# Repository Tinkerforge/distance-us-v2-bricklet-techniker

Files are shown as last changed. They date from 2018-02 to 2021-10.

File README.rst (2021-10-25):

Distance US Bricklet 2.0
========================

**This Bricklet is currently in development.**

This repository contains the firmware source code and the hardware design
files. The documentation generator configs can be found at
https://github.com/Tinkerforge/generators

Repository Content
------------------

software/:
 * examples/: Examples for all supported languages
 * build/: Compiled files
 * src/: Source code of firmware
 * Makefile: Makefile to build project

hardware/:
 * Contains KiCad project files and additionally schematics as PDF

datasheets/:
 * Contains datasheets for sensors and complex ICs that are used

Hardware
--------

The hardware is designed with the open source EDA Suite KiCad
(http://www.kicad.org). Before you are able to open the files,
you have to install the Tinkerforge kicad-libraries
(https://github.com/Tinkerforge/kicad-libraries). You can either clone
them directly in hardware/ or clone them in a separate folder and
symlink them into hardware/
(ln -s kicad_path/kicad-libraries project_path/hardware). After that you
can open the .pro file in hardware/ with KiCad and from there view and
modify the schematics and the PCB layout.

Software
--------

If you want to do your own Brick/Bricklet firmware development we highly
recommend that you use our build environment setup script and read the
tutorial (https://www.tinkerforge.com/en/doc/Tutorials/Tutorial_Build_Environment/Tutorial.html).

To compile the C code we recommend you to install the newest GNU Arm Embedded
Toolchain (https://launchpad.net/gcc-arm-embedded/+download).
You also need to install bricklib2 (https://github.com/Tinkerforge/bricklib2).

You can either clone it directly in software/src/ or clone it in a
separate folder and symlink it into software/src/
(ln -s bricklib_path/bricklib2 project_path/software/src/). Finally make sure to
have CMake installed (http://www.cmake.org/cmake/resources/software.html).

After that you can build the firmware by invoking make in software/.
The firmware (.zbin) can then be found in software/build/ and uploaded
with brickv (click button "Flashing" on start screen).

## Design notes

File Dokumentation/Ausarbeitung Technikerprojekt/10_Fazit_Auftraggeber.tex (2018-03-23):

Aus den Versuchen und Messungen lassen sich mehrere Aussagen treffen. \\
Als erstes, eine Ultraschall-Entfernungsmessung ist mit wenigen Bauteilen, sowohl als Zwei-Kapsel-Variante, als auch als Ein-Kapsel-Variante durchführbar. Bei der Ein-Kapsel-Variante ist darauf zu achten, dass der Verstärker eine ausreichende Spannungsfestigkeit besitzt, um nicht durch das Sendersignal gestört zu werden. Es ist wichtig, dass bei der Erzeugung des Pulsweiten-Modulierten Ausgangssignals die MOSFETs so angesteuert werden, dass den MOSFETs zwischen den Schaltsignalen genug Zeit gegeben wird, um die Schaltzustände zu erreichen. Vergleiche Abbildung \ref{fig:PWMs}. Dadurch lassen sich Kurzschlüsse an dieser Stelle vermeiden.\\
Eine Auswertung des Echo-Signals ist prinzipiell sowohl digital, als auch analog möglich. Bei der digitalen Auswertung muss die Zeit erfasst werden, die zwischen dem Senden des PWM-Signals und dem Empfangen des Echo-Signals vergeht. Die errechnete Strecke ist zu halbieren, da die vergangene Zeit sowohl den Hin-, als auch den Rückweg beinhaltet. Bei der analogen Auswertung besteht zwar die Alternative über einen Frequenzvergleich auch Signale mit kleinerer Echo-Amplitude zu erkennen und auszuwerten, allerdings beinhaltet dieses Vorgehen einen deutlich höheren Programmieraufwand.\\
Bei der Berechnung der Zeiten muss berücksichtigt werden, dass das eingehende Echo-Signal die Ultraschallkapsel langsam in Schwingungen versetzt. Die ersten eintreffenden Schwingungen eines PWM-Signals erzeugen kleinere Spannungssignale als die darauf folgenden. Außerdem schwingt die Ultraschallkapsel nach Ende des eingehenden Signals noch etwas nach, was zur Folge hat, dass das analoge Abbild des gesendeten PWM-Signals leicht versetzt und etwas verlängert wirkt. All diese Faktoren müssen für eine genauere Berechnung der Strecke, die das Signal zurück gelegt hat, berücksichtigt werden. Eine exakte Entfernungsmessung ist nicht möglich, denn das empfangene Signal an der Ultraschallkapsel verändert sich. Eine Beschränkung des Fehlers auf einzelne Zentimeter ist durch rechnerische Korrekturfaktoren realisierbar.\\
Was noch überprüft werden sollte, ist in wie weit sich eine leichte Erhöhung der Frequenz von 40\,kHz auf 42\,kHz auf die Signalqualität und die Reichweite auswirkt. Auch war es zeitlich nicht möglich weitere Messreihen im Außenbereich durchzuführen, was noch weitere Erkenntnisse bringen könnte. Mit den aktuellen Schaltplänen ist der Aufbau eines Ultraschall-Entfernungsmessers durchführbar. Diese Variante arbeitet in einem Bereich von 20\,cm bis 3\,m zuverlässig. Mit erhöhter Sendespannung von 15\,V-20\,V ist auch eine Reichweite von 5\,m bei festen Hindernissen kein Problem. Was noch aussteht, ist eine Festlegung auf definierte Werte für die Verstärkung und die Sendespannung, um die beiden Potentiometer durch Widerstände zu ersetzen. Dadurch lässt sich der Arbeitsbereich auf einen gewünschten Bereich fixieren. Das vorhandene Programm muss nur noch derart erweitert werden, dass die Zeiterfassung für das Echo-Signal überarbeitet und der errechnete Objektabstand ausgegeben wird. Daraus resultiert, dass durch weitere Bearbeitung des Projektes ein qualitatives und durch seine Bauweise, selten auf dem Markt zu findendes Produkt, entstehen kann.

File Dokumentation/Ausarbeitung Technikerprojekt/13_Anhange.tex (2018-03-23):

Abbildungen der Messreihen mit Sendespannungen von 5\,V und 10\,V bei Abständen von ein bis fünf Metern.\\
\begin{minipage}{0.46\textwidth}
\includegraphics[width=1\textwidth%, draft
]{Abbildungen/MessungenP2/5V/1m.PNG}
\captionof{figure}{Signalverlauf bei 5\,V auf 1\,m Abstand}
\end{minipage}\qquad
\begin{minipage}{0.46\textwidth}
\includegraphics[width=1\textwidth%, draft
]{Abbildungen/MessungenP2/10V/1m.PNG}
\captionof{figure}{Signalverlauf bei 10\,V auf 1\,m Abstand}
\end{minipage}\\
\begin{minipage}{0.46\textwidth}
\includegraphics[width=1\textwidth%, draft
]{Abbildungen/MessungenP2/5V/2m.PNG}
\captionof{figure}{Signalverlauf bei 5\,V auf 2\,m Abstand}
\end{minipage}\qquad
\begin{minipage}{0.46\textwidth}
\includegraphics[width=1\textwidth%, draft
]{Abbildungen/MessungenP2/10V/2m.PNG}
\captionof{figure}{Signalverlauf bei 10\,V auf 2\,m Abstand}
\end{minipage}\\
\begin{minipage}{0.46\textwidth}
\includegraphics[width=1\textwidth%, draft
]{Abbildungen/MessungenP2/5V/3m.PNG}
\captionof{figure}{Signalverlauf bei 5\,V auf 3\,m Abstand}
\end{minipage}\qquad
\begin{minipage}{0.46\textwidth}
\includegraphics[width=1\textwidth%, draft
]{Abbildungen/MessungenP2/10V/3m.PNG}
\captionof{figure}{Signalverlauf bei 10\,V auf 3\,m Abstand}
\end{minipage}\\
\begin{minipage}{0.46\textwidth}
\includegraphics[width=1\textwidth%, draft
]{Abbildungen/MessungenP2/5V/4m.PNG}
\captionof{figure}{Signalverlauf bei 5\,V auf 4\,m Abstand}
\end{minipage}\qquad
\begin{minipage}{0.46\textwidth}
\includegraphics[width=1\textwidth%, draft
]{Abbildungen/MessungenP2/10V/4m.PNG}
\captionof{figure}{Signalverlauf bei 10\,V auf 4\,m Abstand}
\end{minipage}\\
\begin{minipage}{0.46\textwidth}
\includegraphics[width=1\textwidth%, draft
]{Abbildungen/MessungenP2/5V/5m.PNG}
\captionof{figure}{Signalverlauf bei 5\,V auf 5\,m Abstand}
\end{minipage}\qquad
\begin{minipage}{0.46\textwidth}
\includegraphics[width=1\textwidth%, draft
]{Abbildungen/MessungenP2/10V/5m.PNG}
\captionof{figure}{Signalverlauf bei 10\,V auf 5\,m Abstand}
\end{minipage}\\
Abbildungen der Messreihen mit Sendespannungen von 15\,V und 20\,V bei Abständen von ein bis fünf Metern.\\
\begin{minipage}{0.46\textwidth}
\includegraphics[width=1\textwidth%, draft
]{Abbildungen/MessungenP2/15V/1m.PNG}
\captionof{figure}{Signalverlauf bei 15V auf 1m Abstand}
\end{minipage}\qquad
\begin{minipage}{0.46\textwidth}
\includegraphics[width=1\textwidth%, draft
]{Abbildungen/MessungenP2/20V/1m.PNG}
\captionof{figure}{Signalverlauf bei 20\,V auf 1\,m Abstand}
\end{minipage}\\
\begin{minipage}{0.46\textwidth}
\includegraphics[width=1\textwidth%, draft
]{Abbildungen/MessungenP2/15V/2m.PNG}
\captionof{figure}{Signalverlauf bei 15\,V auf 2\,m Abstand}
\end{minipage}\qquad
\begin{minipage}{0.46\textwidth}
\includegraphics[width=1\textwidth%, draft
]{Abbildungen/MessungenP2/20V/2m.PNG}
\captionof{figure}{Signalverlauf bei 20\,V auf 2\,m Abstand}
\end{minipage}\\
\begin{minipage}{0.46\textwidth}
\includegraphics[width=1\textwidth%, draft
]{Abbildungen/MessungenP2/15V/3m.PNG}
\captionof{figure}{Signalverlauf bei 15\,V auf 3\,m Abstand}
\end{minipage}\qquad
\begin{minipage}{0.46\textwidth}
\includegraphics[width=1\textwidth%, draft
]{Abbildungen/MessungenP2/20V/3m.PNG}
\captionof{figure}{Signalverlauf bei 20V auf 3m Abstand}
\end{minipage}\\
\begin{minipage}{0.46\textwidth}
\includegraphics[width=1\textwidth%, draft
]{Abbildungen/MessungenP2/15V/4m.PNG}
\captionof{figure}{Signalverlauf bei 15\,V auf 4\,m Abstand}
\end{minipage}\qquad
\begin{minipage}{0.46\textwidth}
\includegraphics[width=1\textwidth%, draft
]{Abbildungen/MessungenP2/20V/4m.PNG}
\captionof{figure}{Signalverlauf bei 20\,V auf 4\,m Abstand}
\end{minipage}\\
\begin{minipage}{0.46\textwidth}
\includegraphics[width=1\textwidth%, draft
]{Abbildungen/MessungenP2/15V/5m.PNG}
\captionof{figure}{Signalverlauf bei 15\,V auf 5\,m Abstand}
\end{minipage}\qquad
\begin{minipage}{0.46\textwidth}
\includegraphics[width=1\textwidth%, draft
]{Abbildungen/MessungenP2/20V/5m.PNG}
\captionof{figure}{Signalverlauf bei 20\,V auf 5\,m Abstand}
\end{minipage}\\
\newpage
Tabellen mit errechneten Objektabständen zu den durchgeführten Messungen\\
\begin{minipage}{1\textwidth}
\captionof{table}{Entfernungsmessung bei 5\,V Sendespannung}
\label{tab:Entfernungsmessung5V}
\begin{tabularx}{\textwidth}{|p{0.1\textwidth}|p{0.2\textwidth}|p{0.2\textwidth}|p{0.2\textwidth}|X|}
\hline
Entfernung [m]& Zeit bis Anfang Echo [ms] & Zeit bis Ende Echo [ms] & Errechnete Entfernung Anfang [m] & Errechnete Entfernung Ende [m]\\
\hline
1 & 6,11 & 7,23 & 1,0485 & 1,2407\\
\hline
1,5 & 9,02 & 9,89 & 1,5478 & 1,6971\\
\hline
2 & 11,97 & 12,76 & 2,0541 & 2,1896\\
\hline
2,5 & 14,88 & 15,5 & 2,5534 & 2,659\\
\hline
3 & 17,84 & 18,2 & 3,06134 & 3,1231\\
\hline
3,5 & 20,8 & 21,11 & 3,569 & 3,6225\\
\hline
4 & 23,71 & 23,81 & 4,0686 & 4,0858\\
\hline
4,5 & 26,61 & 26,73 & 4,5663 & 4,5869\\
\hline
5 & 29,59 & 29,68 & 5,0776 & 5,0961\\
\hline
\end{tabularx}
\end{minipage}
\begin{minipage}{1\textwidth}
\captionof{table}{Entfernungsmessung bei 10\,V Sendespannung}
\label{tab:Entfernungsmessung10V}
\begin{tabularx}{\textwidth}{|p{0.1\textwidth}|p{0.2\textwidth}|p{0.2\textwidth}|p{0.2\textwidth}|X|}
\hline
Entfernung [m]& Zeit bis Anfang Echo [ms] & Zeit bis Ende Echo [ms] & Errechnete Entfernung Anfang [m] & Errechnete Entfernung Ende [m]\\
\hline
1 & 6,07 & 7,37 & 1,0416 & 1,2647\\
\hline
1,5 & 8,99 & 10,02 & 1,5427 & 1,7194\\
\hline
2 & 11,94 & 12,9 & 2,0489 & 2,2136\\
\hline
2,5 & 14,83 & 15,7 & 2,5448 & 2,6941\\
\hline
3 & 17,8 & 18,48 & 3,0545 & 3,1712\\
\hline
3,5 & 20,7 & 21,36 & 3,5521 & 3,6654\\
\hline
4 & 23,62 & 24 & 4,0532 & 4,1184\\
\hline
4,5 & 26,55 & 26,9 & 4,5560 & 4,6160\\
\hline
5 & 29,5 & 29,9 & 5,0622 & 5,1308\\
\hline
\end{tabularx}
\end{minipage}
\begin{minipage}{1\textwidth}
\captionof{table}{Entfernungsmessung bei 15\,V Sendespannung}
\label{tab:Entfernungsmessung15V}
\begin{tabularx}{\textwidth}{|p{0.1\textwidth}|p{0.2\textwidth}|p{0.2\textwidth}|p{0.2\textwidth}|X|}
\hline
Entfernung [m]& Zeit bis Anfang Echo [ms] & Zeit bis Ende Echo [ms] & Errechnete Entfernung Anfang [m] & Errechnete Entfernung Ende [m]\\
\hline
1 & 6,08 & 7,37 & 1,04333 & 1,2647\\
\hline
1,5 & 8,96 & 10,05 & 1,5375 & 1,7246\\
\hline
2 & 11,92 & 12,95 & 2,0455 & 2,2222\\
\hline
2,5 & 14,81 & 15,75 & 2,5414 & 2,7027\\
\hline
3 & 17,78 & 18,5 & 3,0510 & 3,1746\\
\hline
3,5 & 20,65 & 21,47 & 3,5435 & 3,6843\\
\hline
4 & 23,6 & 24,35 & 4,0698 & 4,1785\\
\hline
4,5 & 26,5 & 26,93 & 4,5474 & 4,6212\\
\hline
5 & 29,48 & 30 & 5,0588 & 5,148\\
\hline
\end{tabularx}
\end{minipage}
\begin{minipage}{1\textwidth}
\captionof{table}{Entfernungsmessung bei 20\,V Sendespannung}
\label{tab:Entfernungsmessung20V}
\begin{tabularx}{\textwidth}{|p{0.1\textwidth}|p{0.2\textwidth}|p{0.2\textwidth}|p{0.2\textwidth}|X|}
\hline
Entfernung [m]& Zeit bis Anfang Echo [ms] & Zeit bis Ende Echo [ms] & Errechnete Entfernung Anfang [m] & Errechnete Entfernung Ende [m]\\
1 & 6,07 & 7,42 & 1,0416 & 1,2733\\
\hline
1,5 & 8,97 & 10,12 & 1,5392 & 1,7366\\
\hline
2 & 11,92 & 13 & 2,0454 & 2,2308\\
\hline
2,5 & 14,8 & 15,8 & 2,5396 & 2,7113\\
\hline
3 & 17,75 & 18,55 & 3,0459 & 3,1832\\
\hline
3,5 & 20,65 & 21,52 & 3,5435 & 3,6928\\
\hline
4 & 23,56 & 24,31 & 4,0428 & 4,1716\\
\hline
4,5 & 26,49 & 27,13 & 4,5456 & 4,6555\\
\hline
5 & 29,46 & 30,1 & 5,0553 & 5,1652\\
\hline
\end{tabularx}
\end{minipage}\\

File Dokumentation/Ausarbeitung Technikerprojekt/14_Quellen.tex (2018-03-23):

\subsection{Dokumentationen}

{ {[EUR] {Eurocircuits}}, {https://www.eurocircuits.com/pcb-design-guidelines/ }
\\ {22.\,März.\,2018}.\\

{ {[RNW] {RN-Wissen}}, {http://rn-wissen.de/wiki/index.php/Abblockkondensator }
\\ {22.\,März.\,2018}.\\

{ {[EV] {Elektronikpraxis Vogel}}, {https://www.elektronikpraxis.vogel.de/sieben-suenden-beim-\\leiterplatten-design-a-356703/ }
\\ {22.\,März.\,2018}.\\

{ {[Mik1] {Mikrocontroller.net}}, { https://www.mikrocontroller.net/articles/Richtiges\_Designen\_von\\
\_Platinenlayouts }
\\ {22.\,März.\,2018}.\\

{ {[Mik2] {Mikrocontroller.net}}, {https://www.mikrocontroller.net/articles/Schaltplan\_richtig\_zeichnen }
\\ {22.\,März.\,2018}.\\

{ {[INFI3] {Infineon}}, {https://www.infineon.com/cms/de/product/microcontroller/32-bit-industria\\
l-microcontroller-based-on-arm-cortex-m/32-bit-xmc1000-industrial-microcontroller-arm-cortex-m0/   }
\\ {22.\,März.\,2018}.\\

\subsection{Datenblätter}

{ {[NEX] {Nexperia}}, {https://assets.nexperia.com/documents/data-sheet/2N7002P.pdf}
\\ {22.\,März.\,2018}.\\

{{[INC1] {Doides Incorporated}}, {https://www.diodes.com/assets/Datasheets/ds30149.pdf}
\\{22.\,März.\,2018}.\\

{{[INC2] {Doides Incorporated}}, {https://www.diodes.com/assets/Datasheets/DMG6602SVT.pdf}
\\{22.\,März.\,2018}.\\

{{[INFI1] {Infineon}}, {https://www.infineon.com/dgdl/Infineon-XMC1400-DS-v01\_03-EN.pdf?\\fileId=5546d46250cc1fdf015110a2596343b2}
\\ {22.\,März.\,2018}.\\

{{{INFI2}}, {https://www.infineon.com/dgdl/Infineon-XMC1400-AA\_ReferenceManual-UM
\\-v01\_01-EN.pdf?fileId=5546d46250cc1fdf0150f6ebc29a7109}
\\ {22.\,März.\,2018}.\\

{{[KHM] {Elektrotechnik Karl-Heinz Mauz GmbH}}, {http://www.produktinfo.conrad.com/daten
\\blaetter/525000-549999/541348-da-01-en-OFFENER\_ULTRASCHALLSENSOR\_A\_16P\_T\_R.pdf}
\\{22.\,März.\,2018}.\\

{{[AM] { Allegro MicroSystems, LLC }}, {https://www.allegromicro.com/de-DE/Products/Motor-
\\Driver-And-Interface-ICs/Brush-DC-Motor-Drivers/A5950.aspx}
\\ {22.\,März.\,2018}.\\

{{[TI] {Texas Instruments}}, {http://pdf1.alldatasheet.com/datasheet-pdf/view/522033/TI/TLC272A.html}
\\{22.\,März.\,2018}.\\

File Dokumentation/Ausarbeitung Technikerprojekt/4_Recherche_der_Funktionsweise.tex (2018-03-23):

\tikzstyle{block} = [draw, fill=blue!20, rectangle, 
    minimum height=3em, minimum width=6em]
\tikzstyle{block1} = [draw, fill=white!20, rectangle, 
    minimum height=3em, minimum width=10em]
\tikzstyle{pinstyle} = [pin edge={to-,think,black}]
\tikzstyle{input} = [coordinate]
\tikzstyle{output} = [coordinate]
\tikzstyle{line} = [ draw, dashed, line width = 0.5pt, -latex']
\begin{center}
\begin{minipage}{0.75\textwidth}
\includegraphics[width=1\textwidth%, draft
]{Abbildungen/Schema.png}
\captionof{figure}{Blockschaltbild des Ultraschall-Entfernungsmessers}
\label{fig:Blockschaltbild}
%\begin{tikzpicture}[auto, node distance=2cm,>=latex']
%\begin{picture}(250,100)
%%\put(-38,-122){\dashbox{2.5}(210,45)[rb] {Empfänger}}
%%\put(-38-122){\text{Empfänger}}
%\node [block](controller){Controller};
%\node [block, right of=controller, node distance=4.5cm] (schalter)  {Schalter};
%\node [block, above of=schalter, node distance=2cm] (hochsetzsteller) {Hochsetzsteller};
%\node [block, right of=schalter, node distance=4.5cm] (ultraschallkapsel)  {Ultraschallkapsel};
%\node [block, below of=ultraschallkapsel, node distance=3.5cm] (filterung)  {Filterung};
%\node [block, left of=filterung, node distance=4.5cm] (verstaerker)  {Verstaerker};
%\node [block, left of=verstaerker, node distance=4.5cm] (komperrator)  {Komperrator};
%
%\draw [->] (controller) -- node[name=PWM ] {$PWM$}  (schalter);
%\node [output, right of=schalter] (output) {};
%\coordinate [below of=PWM] (tmp);
%\draw [->] (hochsetzsteller) -- node[name=VBB ] {$VBB$}  (schalter);
%\node [output, above of=schalter] (output) {};
%\coordinate [below of=VBB] (tmp);
%\draw [->] (schalter) --  (ultraschallkapsel);
%\draw [->] (ultraschallkapsel) --  (filterung);
%\draw [->] (filterung) --  (verstaerker);
%\draw [->] (verstaerker) --  (komperrator);
%\node [output, right of=schalter] (output) {};
%\coordinate [below of=PWM] (tmp);
%\draw [->] (komperrator) --  node[name=Digital ] {$Digital$} (controller);
%\node [output, above of=komperrator] (output) {};
%\coordinate [below of=Digital] (tmp);
%\path[line] (verstaerker)--node[name=analog] {$Analog$}  (controller);
%\end{picture}
%\end{tikzpicture}
%\captionof{figure}{Blockschaltbild}
%\label{fig:Blockschaltbild1}

\end{minipage}
\end{center}
Die Abbildung \ref{fig:Blockschaltbild} zeigt eine vereinfachte Funktionsübersicht der Platine. Die Schaltpläne zu den verschiedenen Ausführungen der Platine sind den Anlagen beigefügt.

\subsection{Mikrocontroller}
Der Mikrocontroller soll eine stabile und variable PWM ausgeben können. Es werden für die Zeiterfassung und die PWM Ausgabe mehrere Timer benötigt, die sowohl intern als auch über die Hardware angesteuert werden können. Ein Analog/Digital-Wandler sollte ebenfalls vorhanden sein.

\subsection{Sender}
Der Sender soll Schallwellen im Ultraschallbereich (40\,kHz) aussenden. Diese sollen einen ausreichenden Schalldruck haben um von Hindernissen, die mehrere Meter entfernt sind, ein Echo erhalten zu können. Dafür muss die Ultraschallkapsel mit einem sinusähnlichen Signal angesteuert werden. Dessen Amplitude muss angemessen hoch sein, um den gewünschten Schalldruck zu erzeugen. Der Mikrocontroller ist auf eine Spannungsebene von 3,3\,V begrenzt. Um höhere Spannungen an der Ultraschallkapsel realisieren zu können, muss ein Schalter als weiteres Bauteil dazwischen geschaltet werden. Dieses zusätzliche Bauteil dient als Trennung zwischen den 3,3\,V des Mikrocontrollers und der höheren Spannungsebene der Lautsprecherkapsel. Dabei muss darauf geachtet werden, dass der Schalter schnell genug arbeitet, um die 40\,kHz auch zuverlässig schalten zu können.

\subsection{Hochsetzsteller}
Der Hochsetzsteller generiert aus den 5\,V Versorgungsspannung eine höhere Spannung für den Sendebetrieb. So kann der Schalldruck, der ausgegeben wird erhöht werden (größere Reichweite/größeres Rücksignal) siehe Abbildung \ref{fig:5v5m2}.\\
Die Funktionsweise des Hochsetzstellers (Spannungspumpe/Aufwärtswandler/Aufwärtsregler) ist überschaubar und findet in vielen Bereichen Anwendung. Grundsätzlich wird eine Induktivität in Reihe mit einer Freilaufdiode vor einen Ladekondensator geschaltet. Dieser liegt parallel zum Ausgang. Zwischen der Spule und der Diode ist ein Schalter angeschlossen, der die Spule gegen Masse schaltet. Die Spule lädt sich bei Betätigung des Schalters auf. Durch den Stromfluss entsteht ein Magnetfeld und beim öffnen steigt die Spannung am sekundären Ende der Spule. Durch das zusammenbrechende Magnetfeld an und lädt den Kondensator auf. Dieser Vorgang wird wiederholt bis der Kondensator so weit aufgeladen ist, dass die Ausgangsspannung den gewünschten Wert hält. Die mögliche Ausgangsspannung ist nicht unbegrenzt über das Schaltspiel regelbar. Sie ist von den Eigenschaften der Komponenten abhängig. Vergleiche Abbildung \ref{fig:Hochsetzsteller}.

\subsection{Ultraschallkapsel}
Für das Senden und Empfangen des Ultraschalls wird eine auf Piezomodulen basierende Ultraschallkapsel verwendet, weil Sie die Möglichkeit hat ein Signal auszugeben sowie zu empfangen und in Kleinbauform erhältlich ist. Wie stark das Nachschwingen der Kapsel eine Auswirkung auf die Empfängerschaltung hat, sowie die Größe der Störfrequenz bei verschiedenen Amplituden auf unterschiedlichen Entfernungen sollte überprüft werden. Es sollte auch getestet werden welche Kapseln sich für einen stand-alone Betrieb am besten eignen.

\subsection{Filter}
Die Filterschaltung soll am Eingang des Empfängers etwaig Störfrequenzen herauszufiltern um eine Verfälschung der gemessenen Strecke zu vermeiden, da die Ultraschallkapsel nicht ausschließlich Ultraschallsignale aufnimmt. Für hohe Frequenzen eignet sich eine passive Hochpassfilter-Schaltung, es wird zu einem Kondensator oder einer Spule ein Widerstand parallel zur Masse bestückt. 

\subsection{Empfänger}
Im Empfangsbetrieb werden die zurückkommenden Schallsignale, die auf die Ultraschallkapsel treffen, in sinusförmige Spannungssignale umgewandelt. Die Amplitude hängt von dem Schalldruck der empfangenen Signale ab und ist deutlich niedriger als die Amplitude der gesendeten Signale. Diese Signale müssen anschließend verstärkt werden, um sie mit dem Mikrocontroller auswerten zu können. Zur Vereinfachung der Auswertung wird das eingehende analoge Signal in ein digitales Signal umgewandelt, um Verarbeitungsaufwand einsparen zu können. Die Analyse eines Analogsignals erfordert mehr Programmieraufwand als die Auswertung eines Digitalsignals. Um die Qualität der gemessenen Entfernung besser zu beurteilen, sollte potenziell auch das Analogsignal ausgewertet und mit dem digitalen Signal verglichen werden.

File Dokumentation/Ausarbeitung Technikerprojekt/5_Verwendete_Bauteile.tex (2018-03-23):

Bevor ein erster Prototyp erstellt werden konnte, mussten die richtigen Bauteile ausgewählt werden. Dies Geschah unteranderem anhand der gewonnenen Informationen aus dem Kapitel 2 Vorbereitung. 

\subsection{Mikrocontroller}
Der Infineon XMC 1404\_Q048 gehört zur Familie der ARM Cortex -M0 Prozessoren und ist ein 32\,Bit Industrial Mikrocontroller, wird mit 48\,MHz externer Clock betrieben. Die Q048 im Namen steht für die Anzahl der Pins. Der interne Timer läuft mit 96~MHz. Die CCU4 des Prozessors bietet ein 2x4 16\,Bit Timer. Zudem hat der XMC einen 12\,Bit A/D Wandler, welcher für die Analogmessung eine genauere Auflösung bieten kann als ein 8\,Bit A/D Wandler. Die Betriebsspannung des Prozessors beträgt 3,3\,V. Die Auswahl des Mikrocontrollers wurde getroffen, weil dieser standardmäßig bei Tinkerforge eingesetzt wird und uns für den Prototypen vorgegeben wurde.

\subsection{Sender}Um eine Trennung zwischen der Mikrocontroller, (3,3\,V) und dem Hochsetzsteller (5\,V-20\,V)zu ermöglichen, wurde ein zusätzliches Bauteil benötigt. Dafür wurde das IC A5950 (Voll Brücke) ausgewählt. Diese H-Brücke kann eine angeschlossene Last mit der vom Hochsetzstellers erzeugten Spannung versorgen. Deren Frequenz wird über das Signal an dem Pin \glqq Phase \grqq~von dem Prozessor vorgegeben. An den Anschlüssen Out1 und Out2 wird das Ausgangssignal abgegriffen. Für die genaue Beschaltung des ICs siehe Anhang Datenblatt  \glqq Schimatic A5950 \grqq.

\subsection{Hochsetzsteller}
Tinkerforge nutzt schon eine Variante eines Hochsetzstellers auf ihren Platinen. Der Aufbau und die Bauteilauswahl mussten nur auf die variable Ausgangspannungs erweitert werden. Die Standardschaltung, von Tinkerforge, wurde an dem Eingang der Feedbackspannung mit einem Potentiometer (R\textsubscript{V1}) ergänzt, um die gewünschte variable Spannung zu generieren. Zu sehen in Abbildung \ref{fig:Hochsetzsteller}.\\
Die Ausgangsspannung wird mit den externen Widerständen R\textsubscript{V1}, R\textsubscript{13} und R\textsubscript{2} eingestellt (siehe Grundschaltung Datenblatt vom IC LRM62014x, Seite 11). Ein Wert von ca. \(\displaystyle 13,3\,k\Omega \) wurde für R\textsubscript{2} empfohlen. Mit den Potentiometer R\textsubscript{V1} lässt sich die Ausgangsspannung bei 5\,V Eingangsspannung bis 21,5\,V einstellen. In der Formel werden die Widerstände R\textsubscript{V1} und R\textsubscript{13} zum Ersatzwiderstand R\textsubscript{E} zusammengefasst.
\onehalfspacing \\
\[\displaystyle R_{E}=R_{2}*\left(\frac{Vout}{1,23}-1\right) \Rightarrow Vout=\left(\frac{R_{E}}{R_{2}}+1\right)*1,23\] 
\singlespacing
\begin{center}
\begin{minipage}{1\textwidth}
\includegraphics[width=1\textwidth%, draft
]{Abbildungen/Pumpe.png}
\captionof{figure}{Schaltplan des beschalteten Hochsetzstellers}
\label{fig:Hochsetzsteller}
\end{minipage}\\
\end{center}

\subsection{Ultraschallkapsel}%bearbeiten
Für den Prototypen wurden mehrere Kapseln diverser Hersteller bestellt. Dieses geschah um Unterschiede der verschieden preisigen Bauteile zu ermitteln und um festzustellen, welches Preissegment die nötige Qualität für die vorliegende Anwendung erfüllt.

\subsection{Filter}%bearbeiten
Um unerwünschte Signalanteile mit Frequenzen, die unter 40\,kHz liegen, zu unterdrücken musste die Filterschaltung mit einem Hochpassfilter (CR Glied) bestehend aus einem Kodensator und einem Widerstand bestückt. Der Widerstand wurde nach der e24\,Reihe ausgewählt.
Die Kapazität des Kondensators wurde an die Grenzfrequenz von 40\,kHz und den Widerstand angepasst.
\onehalfspacing \\
\[\displaystyle C=\frac{1}{2*\pi*fg*R}\Rightarrow\frac{1}{2*\pi*40\,kHz*100\,k\Omega}\approx40\,pF \]
\singlespacing
Anhand der Berechnung wurde für den Hochpassfilter ein Kondensator mit \(\displaystyle 39\,pF\) für C12 in der Abbildung \ref{fig:Empfaengerschaltung} verwendet.
\newpage
\subsection{Empfänger}
Die Abbildung \ref{fig:Empfaengerschaltung} zeigt die Empfängerschaltung. Durch diese Verschaltung von Operationsverstärkern wird das ankommende sinusförmige Signal verstärkt und in ein digitales Signal umgewandelt. Für die Verstärkung der Amplitude und der Umwandlung des analogen Signals in ein Rechtecksignal mit 40\,KHz wurde der das IC TLC272 ausgewählt, weil dieses günstig im Stückpreis ist und die technischen Spezifikationen ausreichend sind. Siehe Datenblatt vom IC TLC272 [TI].\\
Für die Verstärkung der Amplitude ist der Operationsverstärker TLC272 U2B als nicht invertierender Verstärker geschaltet.
Zur Umwandlung des analogen Signales in ein digitales wurde der Operationsverstärker TLC272 U2C als Komparator geschaltet. Beim Auftreten von Differenzen zwischen den Eingangssignalen, wechselt der Ausgang des Komparators zwischen Low (0\,Volt) auf High (3,3\,Volt).\\ Die Referenzspannung (\(\displaystyle U_{ref})\)  wird durch den Spannungsteiler R\textsubscript{9} und R\textsubscript{10} bestimmt.
\onehalfspacing \\
\[\displaystyle U_{ref}=\frac{U_{ges}*R_{9}}{R_{9}+R_{10}}\Rightarrow\frac{3,3\,V*120\,k\Omega}{100\,k\Omega+120\,k\Omega}=1,8\,V \]
\singlespacing
\begin{center}
\begin{minipage}{1\textwidth}
\includegraphics[width=1\textwidth%, draft
]{Abbildungen/Empfaenger.png}
\captionof{figure}{Schaltplan zweier Operationsverstärker mit einer vorgelagerten Filterung als Empfängerschaltung}
\label{fig:Empfaengerschaltung}
\end{minipage}\\
\end{center}

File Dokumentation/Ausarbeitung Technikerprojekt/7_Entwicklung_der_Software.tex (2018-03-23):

Zum Betrieb der Prototypen wurde bereits eine rudimentäre Version einer Betriebssoftware erstellt. Diese wurde benötigt um Ausgangssignale generieren zu können, damit Messungen an dem Empfängerkreis durchgeführt werden konnten.
\subsection{Benötigte Kenntnisse}
Um das Programm zu erstellen sollten Kenntnisse z.B. für die Capture Compare Unit des Mikrocontrollers vorhanden sein. Die CCU4 hat insgesamt 4 Einheiten und jede einzelne besitzt mehrer Slices von CC40 bis CC43. Slices können untereinander verschachtelt werden um z.B. Interrupt Service Routinen aufzurufen, siehe dazu das Reference Manual [INF2].
Die Werte der Register mit denen die Zeit gemessen wird müssen sofort zum beginn der Interrupt Service Routine zwischengespeichert werden damit sichergestellt wird das nicht die Zeit zur Brechung mit gemessen wird.\\

\subsubsection{Durchgeführte Berechnungen}
Für die Programmierung waren diverse Berechnungen notwendig. Zur Erzeugung der Ultraschallimpulse wurde ein pulsweitenmoduliertes Rechtecksignal mit einer Frequenz von 40\,kHz generiert. Dafür war es notwendig mithilfe der CCU4 einen Timer zur erstellen. Dabei musste bei einem Timertakt von 96\,MHz eine Periodendauer von 2400 Takten und einem Compare-Wert von 1200 Takten konfiguriert werden. Im Zählvorgang des Timers wird der Ausgang nach erreichen des Compare-Wertes auf 1 gesetzt, und nach erreichen der Periodendauer wieder auf 0 zurückgesetzt. Dadurch ergibt sich eine Periodendauer von 25\,\textmu s, was einer Frequenz von 40\,kHz entspricht.\\
Die Zeit, die vergeht, bis das Echo des Ultraschall-Impulses zurückkommt, wird über einen Timer erfasst. 
\onehalfspacing \\ \\
\[\displaystyle Periodendauer=\frac{96\,MHz}{40\,kHz} = 2400,\qquad	 Compare-Wert=\frac{2400}{2} = 1200 \] 
\singlespacing

\subsection{Quellcodeentwurf}

\textbf{Programmstruktur:}\\
In der Hauptpfunktion main.c befinden sich nur Funktionsaufrufe die eine Grundkonfiguration  für den Mikrocontroller beinhalten und eine Schleife die immer wieder aufgerufen wird um z.B. eine neue Entfernungsmessung zu starten. Siehe Abbildung \ref{fig:main.c1}. Anstatt den gesamten Programmcode in der Hauptpfunktion zu verfassen, hat das Auslagern den Vorteil, dass der Quellcode logisch getrennt werden kann. Dieses Vorgehen führt zu einer Verschlankung des Quellcodes anstatt ihn unübersichtlich zu gestalten. Somit stehen in dem Hauptprogramm nur noch die Aufrufe der separat verfassten Funktionen. Dadurch vereinfacht diese Struktur gerade bei Prototypen das Testen der Funktion. So kann im Falle einer fehlerhaften Funktion einfach ein Aufruf auskommentiert werden, um zu testen, ob der Fehler wirklich von der Funktion herrührt. Somit müssen nicht etliche Zeilen Programmcode einer Funktion auskommentiert werden. Dadurch ist die Fehlerrate durch verbleibende Zeichen oder beim Entfernen der Auskommentierung gelöschte Zeichen deutlich gesenkt.\\
\begin{minipage}{1\textwidth}
\begin{lstlisting}
#include <stdio.h>
#include <stdbool.h>
#include "bricklib2/logging/logging.h"
#include "bricklib2/bootloader/bootloader.h"
#include "communication.h"
/****Eigene Include Dateien*******/
#include "configs/config.h"
#include "system_timer/system_timer.h"
#include "a16pt.h"
int main(void)
{ 
	logging_init(); 
	logd("Start Distance US V2 Bricklet/n/r");  	//For the Debugmodus
	communication_init(); 					//Function call
	a16pt_init(); 								//Function call	
	while(true)
	{
		a16pt_tick(); 						//Function call
		bootloader_tick(); 					//Function call
		communication_tick(); 				//Function call	
	}
}
\end{lstlisting}
\captionof{figure}{kompletter Quellcode der main.c}
\label{fig:main.c1}
\end{minipage}\\
%Um die Funktionsaufrufe wie die a16pt\_init und die a16pt\_tick zu verstehen muss die Abbildung \ref{fig:a16pt.h}: Headerdatei der a16pt.h näher betrachtet werden. In der der Datei werden die Funktionen definiert und deren Funktionsanweisung steht dann in der a16pt.c.\\
Die verwendete Vorgehensweise bei der Programmierung arbeitet mit einer gewissen Verschachtlung. In den *.c Dateien befindet sich zwar der Großteil des des aktiv geschriebenen Programms, doch stehen die Funktionsdefinitionen in den Headerdateien, wie der a16pt.h. Zu sehen in der nachfolgenden Abbildung \ref{fig:a16pt.h}\\
\begin{minipage}{1\textwidth}
\begin{lstlisting}
#ifndef A16PT_H
#define A16PT_H
#include <stdint.h>
	void a16pt_init(void);			//Functional definition
	void a16pt_tick(void); 			//Functional definition
	uint16_t a16pt_get_distance(void); //Functional definition
#endif
\end{lstlisting}
\captionof{figure}{Inhalt der Headerdatei a16pt.h}
\label{fig:a16pt.h}
\end{minipage}\\
\\
\textbf{Init Aufruf:}
In der Abbildung \ref{fig:a16pt.c} ist ein Teilausschnitt aus der a16pt.c zu sehen. Dieser enthält zwei verschiedene PWM Konfigurationen, die auf den Ports P4\_4 und P4\_6 ausgegeben werden.

\begin{minipage}{1\textwidth}
\begin{lstlisting}
void a16pt_init(void)
{
/*****************Externe_Interrupt*******************/

	eru_init(eru_port);

/************PWM_Init*****************************/

	XMC_CCU4_Init(CCU41, XMC_CCU4_SLICE_MCMS_ACTION_TRANSFER_PR_CR_PCMP);
	XMC_CCU4_StartPrescaler(CCU41);

	ccu4_pwm_init(pwm_port_0,cc40, period_1);	//P4_4
	ccu4_pwm_set_duty_cycle( cc40, compare_1);

	ccu4_pwm_init(pwm_port_1,cc42, period_0);	//P4_6
	ccu4_pwm_set_duty_cycle( cc42, compare_0);
...
\end{lstlisting}
\captionof{figure}{Ein Teilausschnitt aus der a16pt.c mit Konfigurationen von Funktionen}
\label{fig:a16pt.c}
\end{minipage}

\textbf{Interrupt Aufrufe:}
In der Abbildung \ref{fig:a16pt.c1} werden beispielsweise die für die Entfernungsmessung notwendigen Funktionen und die Interrupt Anweisungen abgearbeitet. in diesem Fall die IRQ21. Außerdem werden die PWM-Signale synchron abgeschaltet. Unter der Überschrift \glqq New pin configuration\grqq~wird bereits eine neue Ausgangskonfiguration angefangen. Die IRQ wird als Interrupt Request bezeichnet und wird von der Hardware oder von der Software ausgelöst.
\\
\begin{minipage}{1\textwidth}
\begin{lstlisting}

/*************Interrupt_Funktionen****************/

void IRQ_Hdlr_21(void) // Compare Interrupt counter 10
{
	// Disable IRQs so we can't be interrupted
	__disable_irq();

	// Set CCU trigger to low, otherwise ccu counter is restarted
	XMC_SCU_SetCcuTriggerLow(XMC_SCU_CCU_TRIGGER_CCU41);

	// Stop slice 2
	XMC_CCU4_SLICE_StopClearTimer(CCU41_CC40);

	// For slice 1 we wait until PWM is run through (to get exactly 10 pwm peaks on P4_4 and P4_6)
	while(XMC_CCU4_SLICE_GetTimerValue(CCU41_CC42) > compare_1) {

		__NOP();
	}
	
	//New pin configuration
	const XMC_GPIO_CONFIG_t pin_out_config	= {
			.mode                = XMC_GPIO_MODE_OUTPUT_PUSH_PULL,
			.output_level        = XMC_GPIO_OUTPUT_LEVEL_HIGH,
		};

...
\end{lstlisting}
\captionof{figure}{Ein Teilausschnitt von der a16pt.c mit einem Interrupt Request}
\label{fig:a16pt.c1}
\end{minipage}

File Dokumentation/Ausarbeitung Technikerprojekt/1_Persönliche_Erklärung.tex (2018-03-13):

\textbf{\Large{Persönliche Erklärung}}\vspace{10pt}

Hiermit bestätigen wir, dass die vorliegende Arbeit selbstständig verfasst und keine anderen als die angegebenen Hilfsmittel benutzt wurden. Die Stellen der Arbeit, die dem Wortlaut oder dem Sinn nach anderen Werken (dazu zählen auch Internet-quellen) entnommen sind, wurden unter Angabe der Quellen kenntlich gemacht.

\vspace{50pt}

\noindent Bielefeld,\noindent\rule{4cm}{.4pt} \hfill\rule{5cm}{.4pt}\par
\hfill Eduard Meiser 

\vspace{30pt}
%\noindent\rule{5cm}{.4pt}
\hfill\rule{5cm}{.4pt}\par
%\noindent Ort, Datum
\hfill Omar Hachimi 

\vspace{30pt}
%\noindent\rule{5cm}{.4pt}
\hfill\rule{5cm}{.4pt}\par
%\noindent Ort, Datum 
\hfill Stephan Dannat

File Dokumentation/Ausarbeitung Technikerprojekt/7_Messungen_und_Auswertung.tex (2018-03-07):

Zu Beginn wurden Messungen direkt an dem Prozessor durchgeführt, um zu kontrollieren, dass die im Programm errechneten Signale auch die vorgesehenen Frequenzen erreichen. Anschließend wurden einzelne Baugruppen mit dem Prozessor kombiniert, um das Zusammenspiel dieser auswerten zu können. Danach wurden die Baugruppen um den Sensor erweitert und auch dieses Zusammenspiel wurde ausgewertet. Zum Abschluss wurde dann die komplette Platine im Betrieb getestet und optimiert.

\section{Ausgabe}
Um das Signal für die Entfernungsmessung zu generieren wurde der Mikrocontroller so programmiert, dass zehn Impulse mit einer Frequenz von 40kHz ausgegeben werden. Danach erfolgt eine Pause, um das zurückkehrende Signal abzuwarten und auszuwerten.\\
\begin{minipage}{0.5\textwidth}
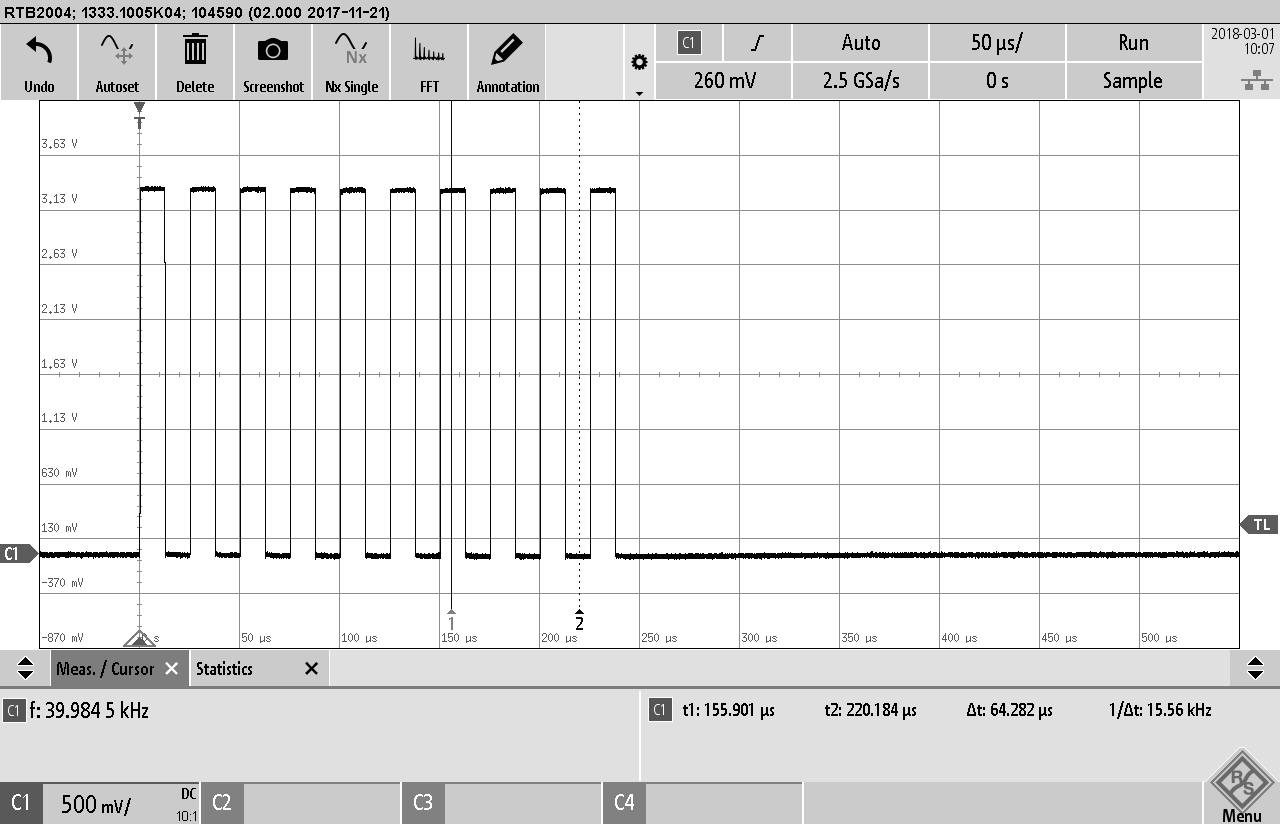
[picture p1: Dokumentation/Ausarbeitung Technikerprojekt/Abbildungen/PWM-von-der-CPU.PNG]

\captionof{figure}{PWM-Burst auf 40kHz Basis an der CPU}
\label{fig:pwm-burst}
\end{minipage}
\begin{minipage}{0.5\textwidth}
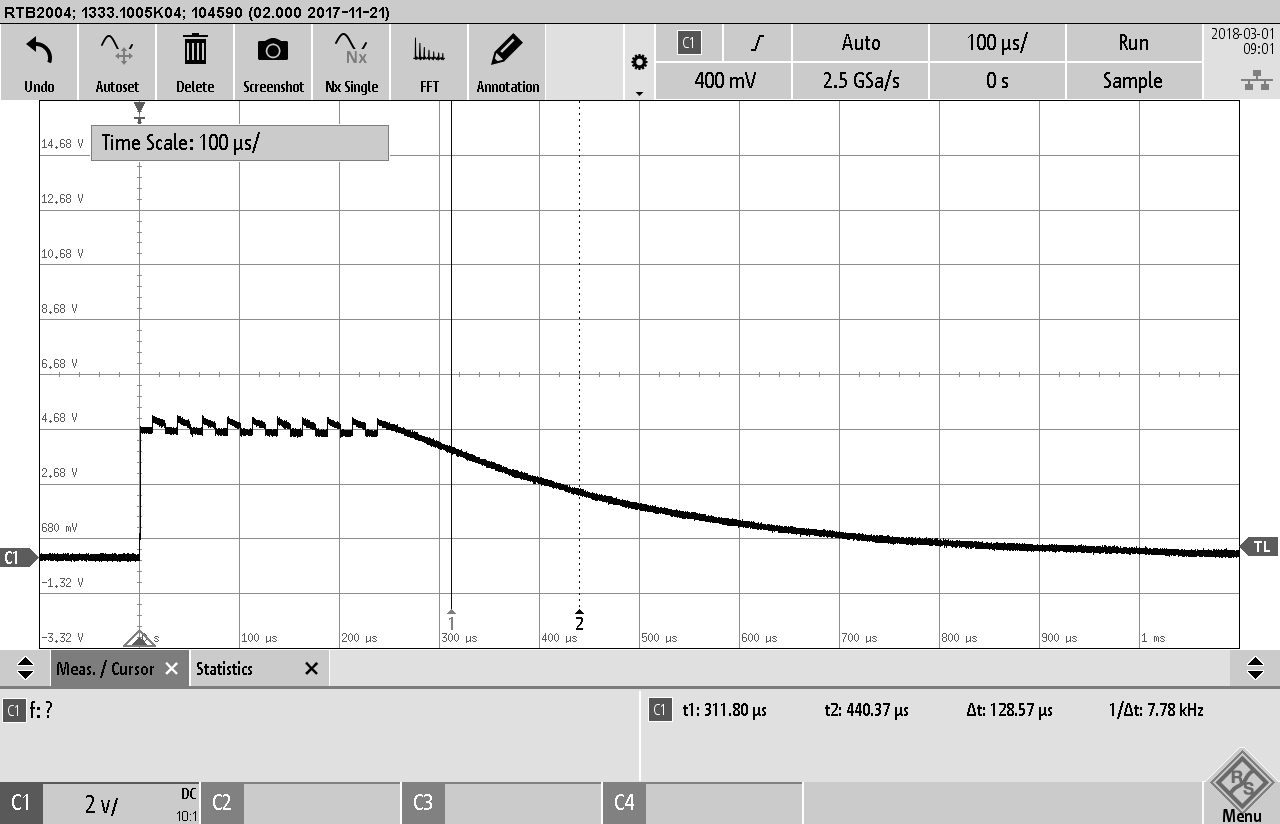
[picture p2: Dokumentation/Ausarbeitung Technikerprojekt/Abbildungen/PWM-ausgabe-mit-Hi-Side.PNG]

\captionof{figure}{PWM Ausgabe über einen Hi-Side}
\label{fig:HiSide}
\end{minipage}

In der Abbildung \ref{fig:pwm-burst} ist zu sehen, dass ein Burst aus zehn Impulsen mit einer Periodendauer von jeweils 25us generiert wurde. Diese Messung wurde direkt an dem Mikrocontroller vorgenommen, um zu überprüfen, wie sich das Signal durch die eingesetzten Bauteile verändert.\\
Die Abbildung \ref{fig:HiSide} zeigt, wie das Ausgangssignal nach der Hi-Side aussieht. So wird zwar im Takt des PWM-Signals geschaltet, allerdichgs fehlt es an einem Gegenpool, um das Potential in den Schaltpausen wieder auf Null zu ziehen. Dadurch bleibt das Signal während des Schaltens immer auf einem erhöhten Pegel und sinkt erst nach Ende des Signals langsam ab. Dadurch kann natürlich keine vernünftige Ausgabe am Lautsprecher erzeugt werden, denn ohne deutliche Potentialunterschiede kann dieser auch nicht richtig schwingen. Der ausgegebene Schalldruck würde maximal für kürzeste Entfernungsmessungen reichen, wenn überhaupt und dann würde das zurückkommende Signal noch von der abklingenden Spannung des Hi-Side überlagert. Dadurch ist dieser Aufbau nicht operabel.\newpage
Wird das Signal über eine Halbbrücke geschaltet, um das Potential auch auf Null ziehen zu können, ergibt sich das folgende Bild. \ref{fig:Halfbridge}.\\
\begin{minipage}{0.5\textwidth}
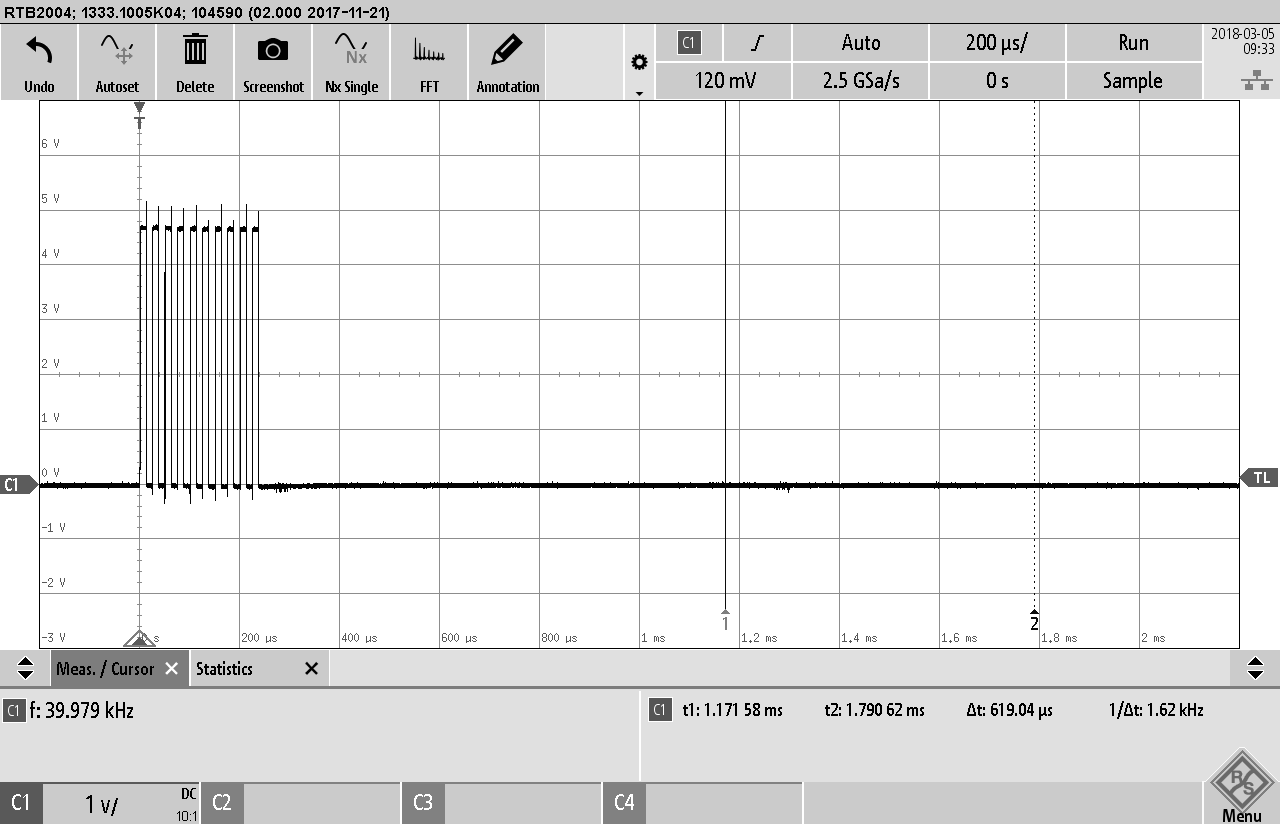
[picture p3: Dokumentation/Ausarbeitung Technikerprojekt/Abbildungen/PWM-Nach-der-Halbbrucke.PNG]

\captionof{figure}{PWM Ausgabe über eine Halbbrucke}
\label{fig:Halfbridge}
\end{minipage}
\begin{minipage}{0.5\textwidth}
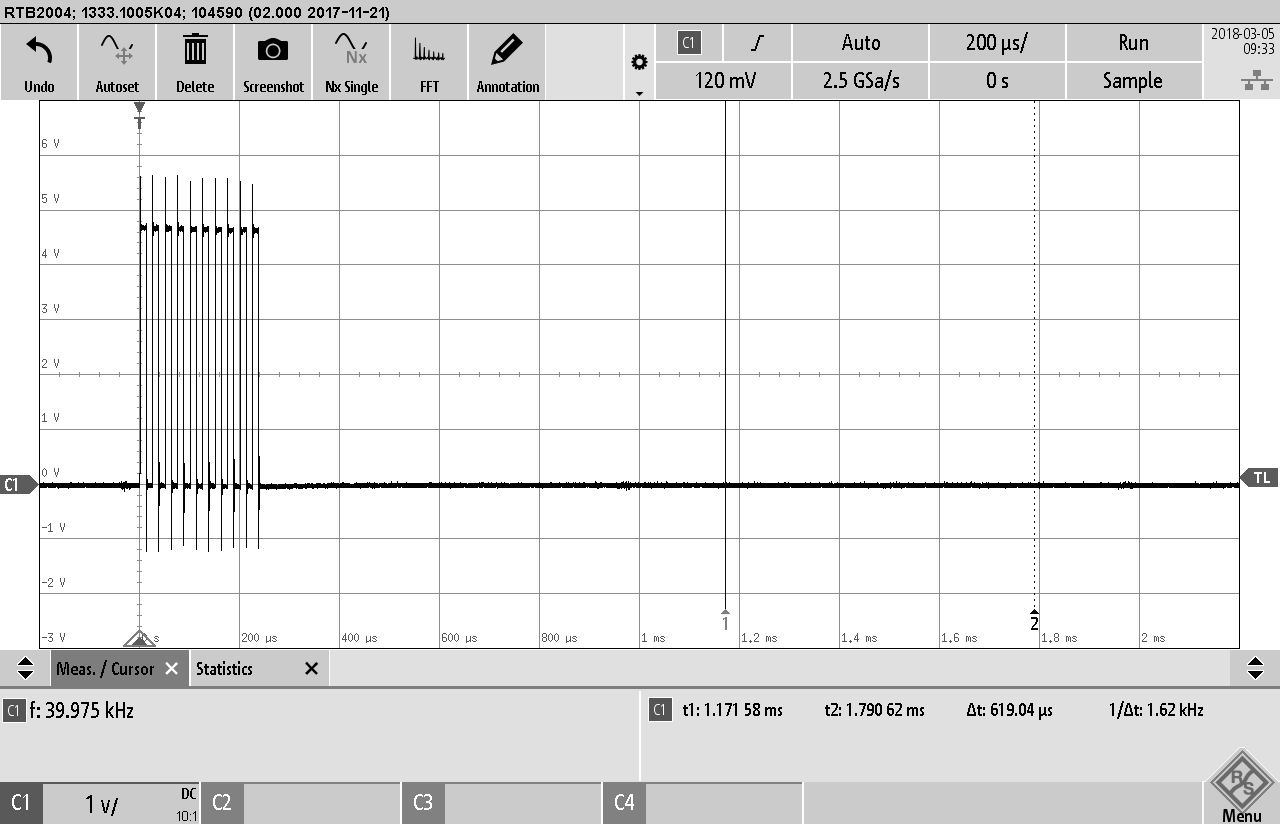
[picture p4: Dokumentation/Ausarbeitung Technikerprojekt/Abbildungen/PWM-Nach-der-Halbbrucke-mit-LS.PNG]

\captionof{figure}{Ausgabe der PWM mit erhöhter Amplitude am Sender}
\label{fig:Sender}
\end{minipage}
Es zeigt sich, dass das Signal nach der Erweiterung auf eine Halbbrücke wieder wie das von der CPU ausgegebene PWM-Signal \ref{fig:pwm-burst} aussieht, nur dass die Amplitude wie geplant höher ausfällt. Somit kann die Höhe der Amplitude über die Spannungspumpe variiert werden um die Stärke des ausgegebenen Signals zu variieren, ohne die CPU durch die höhere Spannung zu beschädigen.
Wie in der Abbildung \ref{fig:Sender} zu entnehmen ist, entstehen durch den angeschlossenen Sender noch Spannungsimpulse im Schaltmoment.

%\section{H-Brücke}
%Mach ersten Versuchen wurde die H-Brücke durch einen IXDN602, einen MOSFET ersetzt. Dies geschah, weil erstens die Beschaltung des OPV nur für eine positive Halbwelle funktioniert und zweitens die Beschaltung der H-Brücke fehlerhaft war. So wurde einer der Ausgänge auf Masse gelegt, was im Betrieb einen Kurzschluss verursachen würde. Um diese Probleme zu beheben, müssten der Sender- und der Empfängerkreis aufgetrennt werden und eine zweite Ultrashallkapsel eingesetzt werden. Dadurch ließ sich eine Reihe an Tests an der Senderschaltung durchführen. Allerdings viel auf, dass im Betrieb keine Signale empfangen wurden. Der Grund dafür war, dass der Mosfet als Low-Side-Driver geschaltet war, was bedeutet dass er das Signal entweder auf High, oder auf Low zieht. Somit werden auch alle von der Ultraschallkapsel empfangenen Signale direkt auf Low gezogen. Also musste eine weitere Überlegung angestellt werden und es wurden aus einem Mosfet zwei. Einer, der vom Prozessor angesteuert wird(3.3V) und den zweiten, der die Sendespannung(5V-20V) freigibt, schaltet. 
\section{Empfangseinheit}
In den ersten Versuchen wurde die Empfangseinheit auf einer zweiten Platine getrennt vom Sender getestet, um eine mögliche Überlagerung der elektrischen Signale zu verhindern. Dafür wurden beide Platinen auf einem Versuchsaufbau befesting und die Sender- und die Empfängerkapsel nebeneinander, parallel ausgerichtet, befestigt.\\
\begin{minipage}{0.5\textwidth}
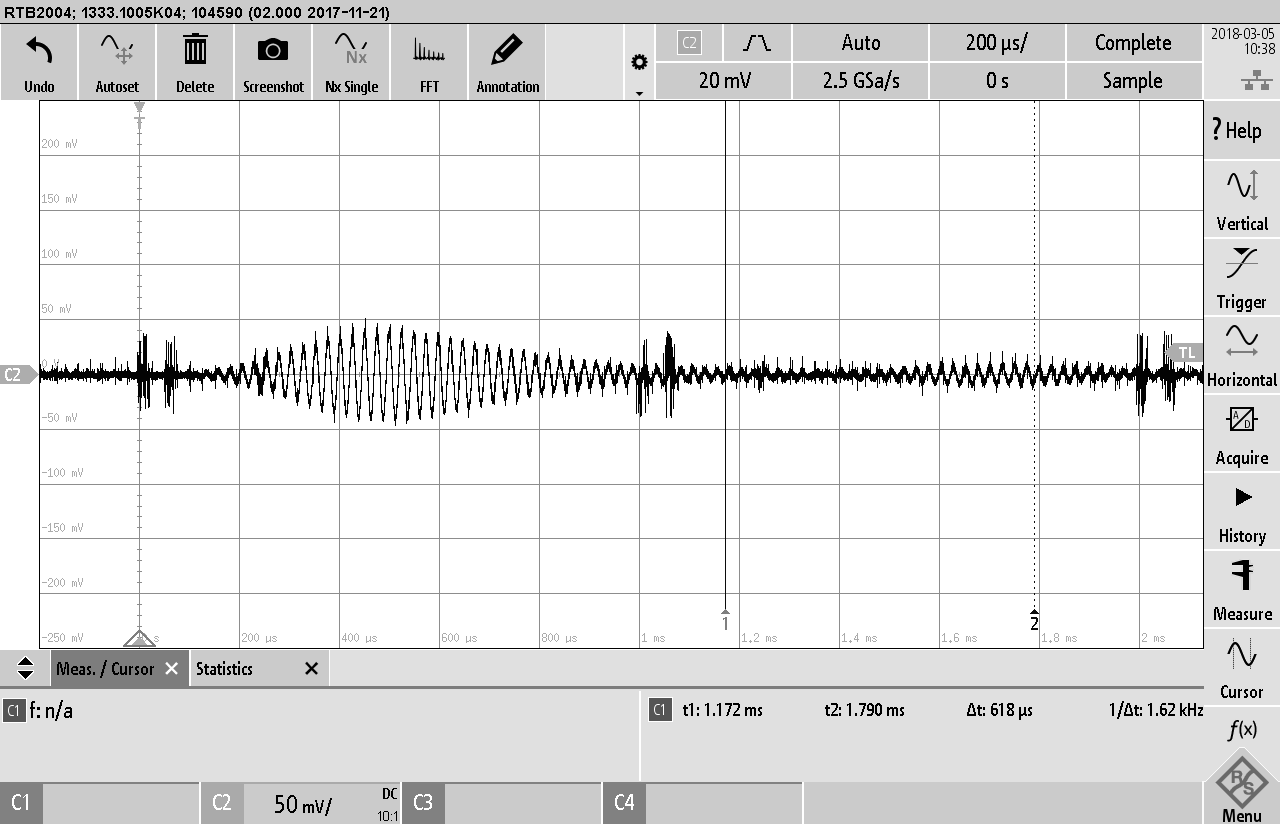
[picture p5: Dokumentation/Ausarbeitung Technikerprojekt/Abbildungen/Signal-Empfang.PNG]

\captionof{figure}{Signal Empfang}
\label{fig:Empfang am LS}
\end{minipage}
\begin{minipage}{0.5\textwidth}
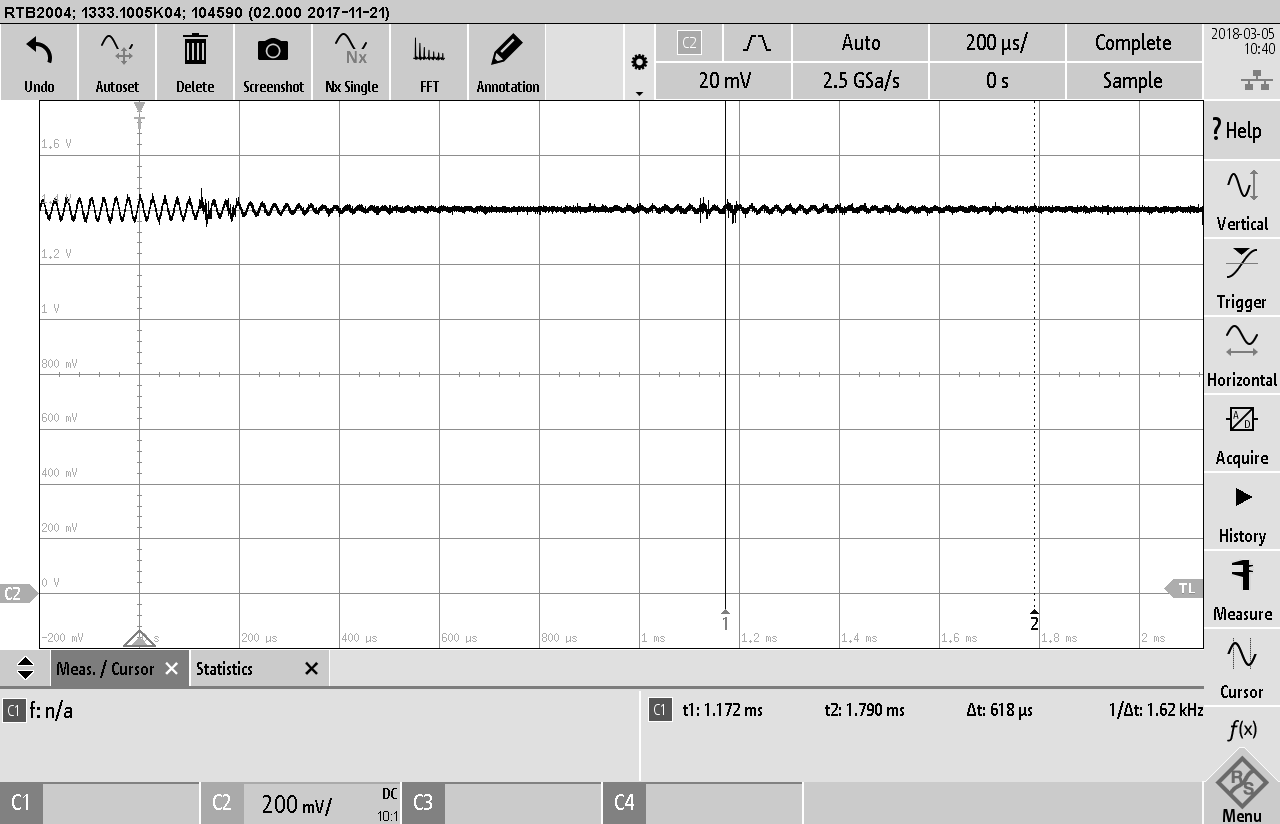
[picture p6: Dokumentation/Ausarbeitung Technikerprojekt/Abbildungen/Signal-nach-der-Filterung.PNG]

\captionof{figure}{Signal nach der Filterung}
\label{fig:Filterung}
\end{minipage}
Die Abbildung \ref{fig:Empfang am LS} zeigt das Signal, das direkt am Empfänger zu messen war. Hier sind verschiedene vorerst nicht zuordnenbare Signale zu sehen. Allein aus diesem Bild lässt sich aber keine Aussage zu den Signalen machen, fest steht nur dass ebenfalls Signale, die nicht der gewünschten Frequenz entsprechen ebenfalls vom Empfänger aufgenommen werden. Diese gilt es natürlich schnellst möglich auszumerzen, um unerwünschte Störungen zu vermeiden.
In der Abbildung \ref{fig:Filterung} ist das Signal nach dem eingebauten Hochpassfilter zu sehen.\\
\begin{minipage}{0.5\textwidth}
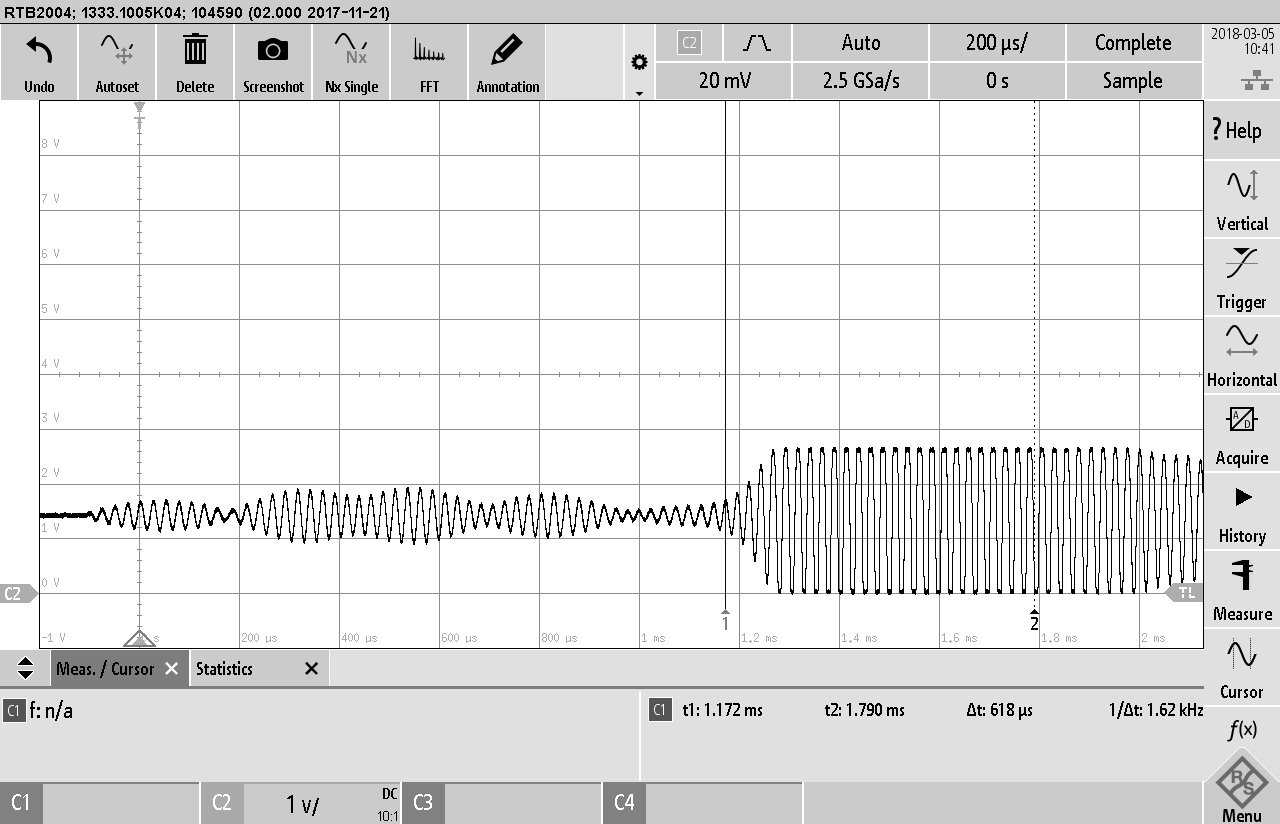
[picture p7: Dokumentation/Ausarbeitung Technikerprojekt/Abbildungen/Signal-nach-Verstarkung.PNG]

\captionof{figure}{Signal nach Verstärkung}
\label{fig:Verstaerkung}
\end{minipage}
\begin{minipage}{0.5\textwidth}
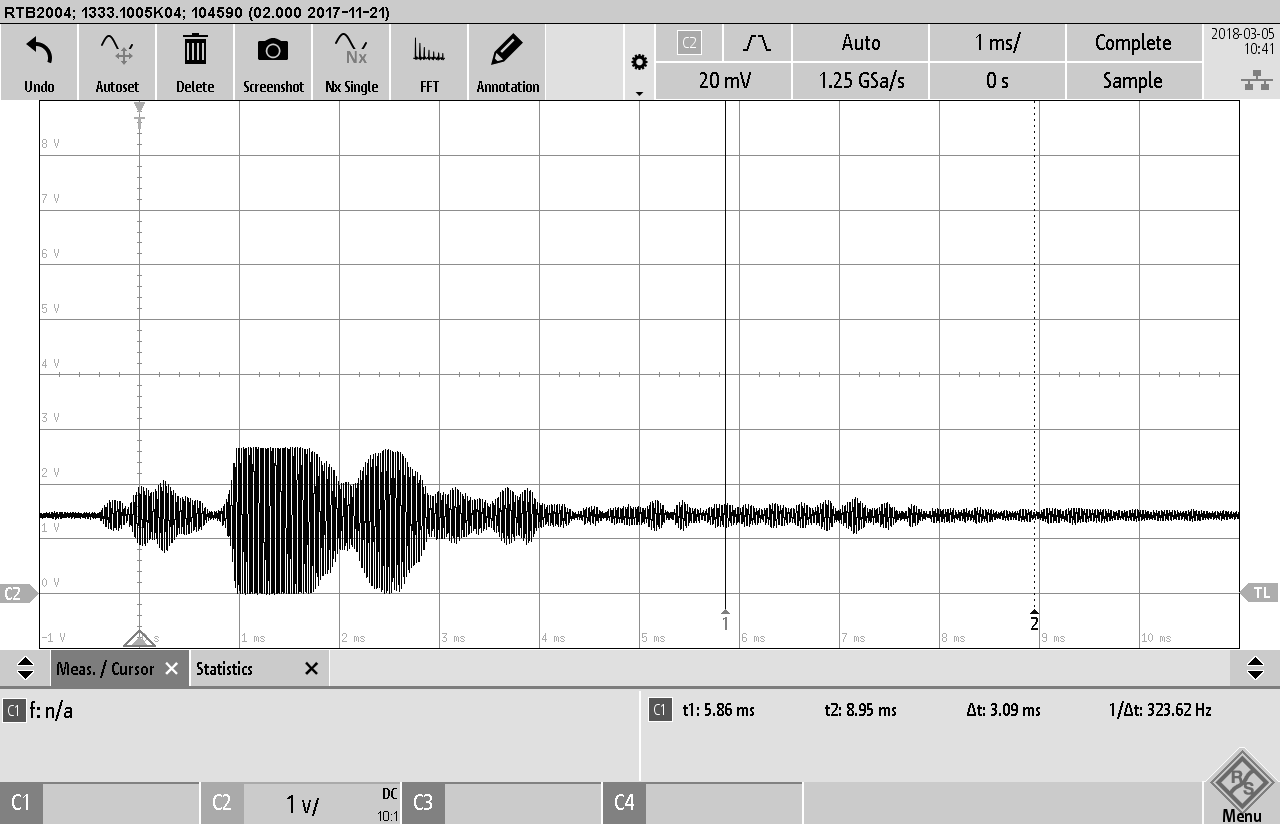
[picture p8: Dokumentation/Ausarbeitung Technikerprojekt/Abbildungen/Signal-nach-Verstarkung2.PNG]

\captionof{figure}{Signal nach Verstärkung2}
\label{fig:Verstaerkung2}
\end{minipage}
Der erste Operationsverstärker dient der Verstärkung des gefilterten Eingangssignals. Dieses ist notwendig, da das ausgesendete Schallsignal mit zunehmendem Weg an Schalldruck verliert, und beim Eintreffen am Empfänger deutlich niedrigere Spannungen erzeugt, als beim absenden eingesetzt wurden. 
\begin{figure}[H]
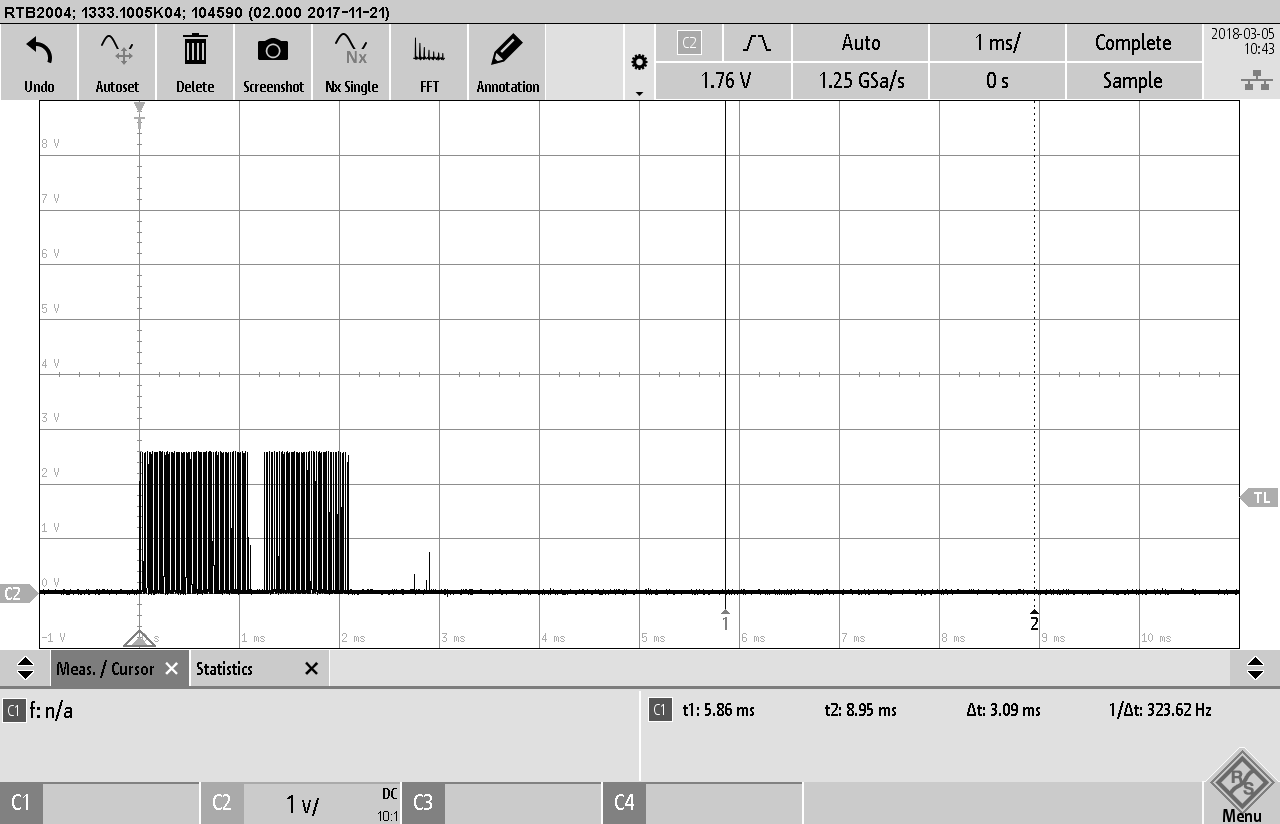
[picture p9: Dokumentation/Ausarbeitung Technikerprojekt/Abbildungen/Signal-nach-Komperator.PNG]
\caption{Signal nach Komperator}\label{fig:Komperator}
\end{figure}
Nach dem das Signal den Komperator passiert hat, ergibt sich das Bild wie in Abbildung \ref{fig:Komperator} zu sehen ist. Aus dem anfänglichen Eingangssignal, aus dem nichts verwertbares abzulesen war, ist ein wesentlich übersichtligeres Signal entstanden. Nun sind lediglich zwei Signalblöcke übriggeblieben, die beide eine Frequenz von 40kHz haben. Bei dem ersten Signalblock handelt es sich um ein Störsignal, denn es ist das vom Sender ausgesandte Signal, das seitlich auf den Empfänger abstrahlt. Der zweite Signalblock ist dagegen das Echo, also das Signal, das vom Hindernis zurückgeworfen wurde. Mit diesem Signal ließe sich die Entfernung zum Hinderniss berechnen.\\
Nachfolgend wurden die Signalverläufe mit verschiedenen Ultraschallkapseln aufgenommen, um vergleichen zu können, wie die Signalqualität bei verschiedenen Produkten schwankt. Dabei wurde die Amplitude von 4,6V für das Sendersignal nicht verändert.\\
\begin{minipage}{0.5\textwidth}
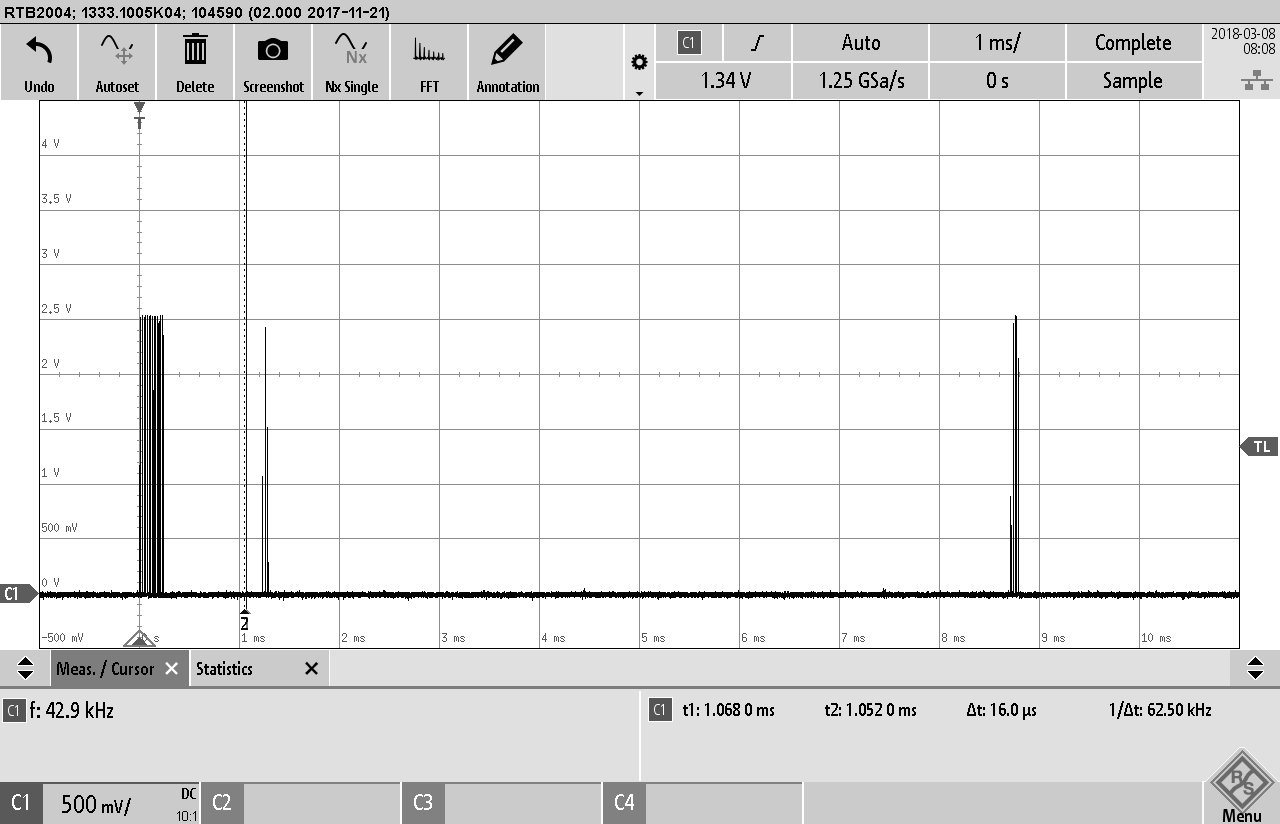
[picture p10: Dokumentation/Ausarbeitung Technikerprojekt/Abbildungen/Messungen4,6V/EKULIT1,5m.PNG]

\captionof{figure}{EKULIT}
\label{fig:EKULIT1,5m}
\end{minipage}
\begin{minipage}{0.5\textwidth}
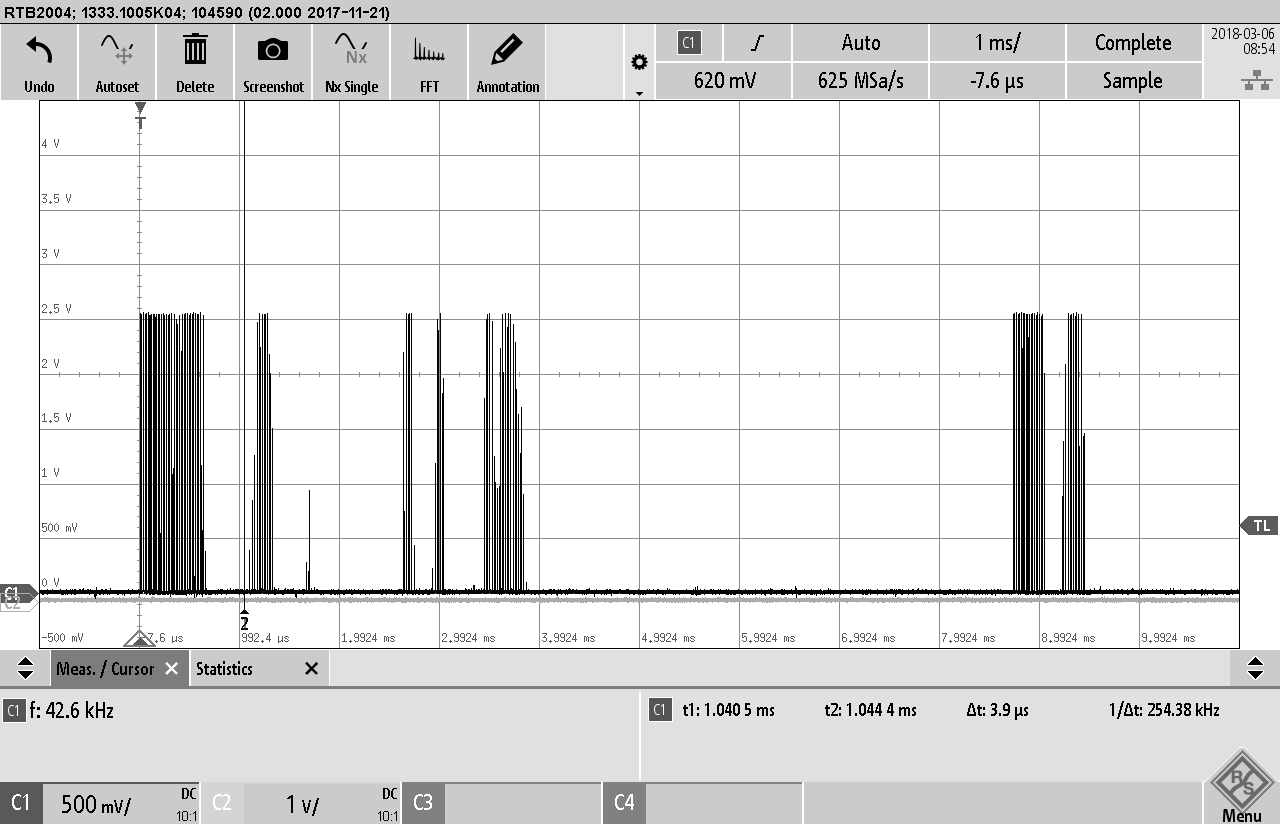
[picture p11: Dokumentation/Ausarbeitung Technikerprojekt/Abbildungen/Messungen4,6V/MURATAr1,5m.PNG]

\captionof{figure}{MURATA reciver}
\label{fig:EKULIT1,5m}
\end{minipage}
\begin{minipage}{0.5\textwidth}
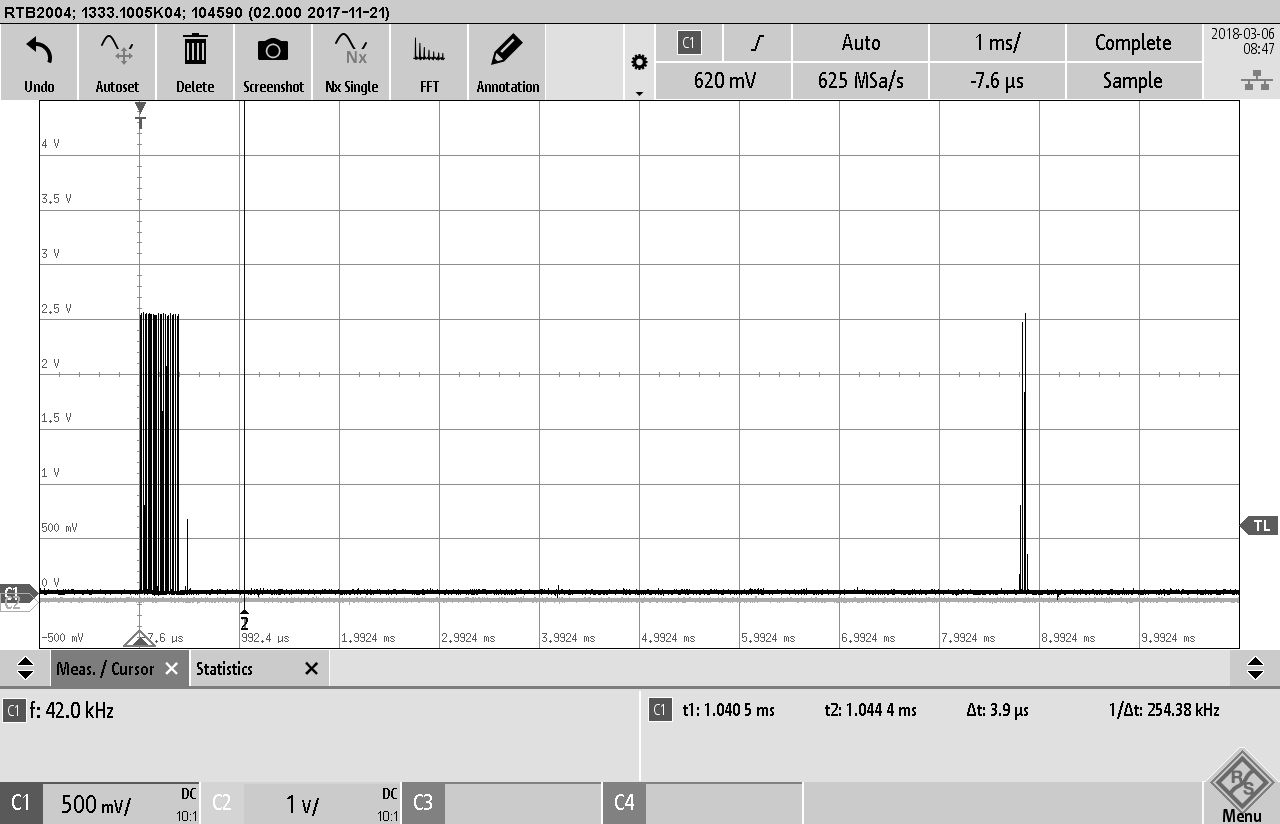
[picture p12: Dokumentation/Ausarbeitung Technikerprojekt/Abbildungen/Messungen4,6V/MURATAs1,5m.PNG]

\captionof{figure}{MURATA sender}
\label{fig:EKULIT1,5m}
\end{minipage}
\begin{minipage}{0.5\textwidth}
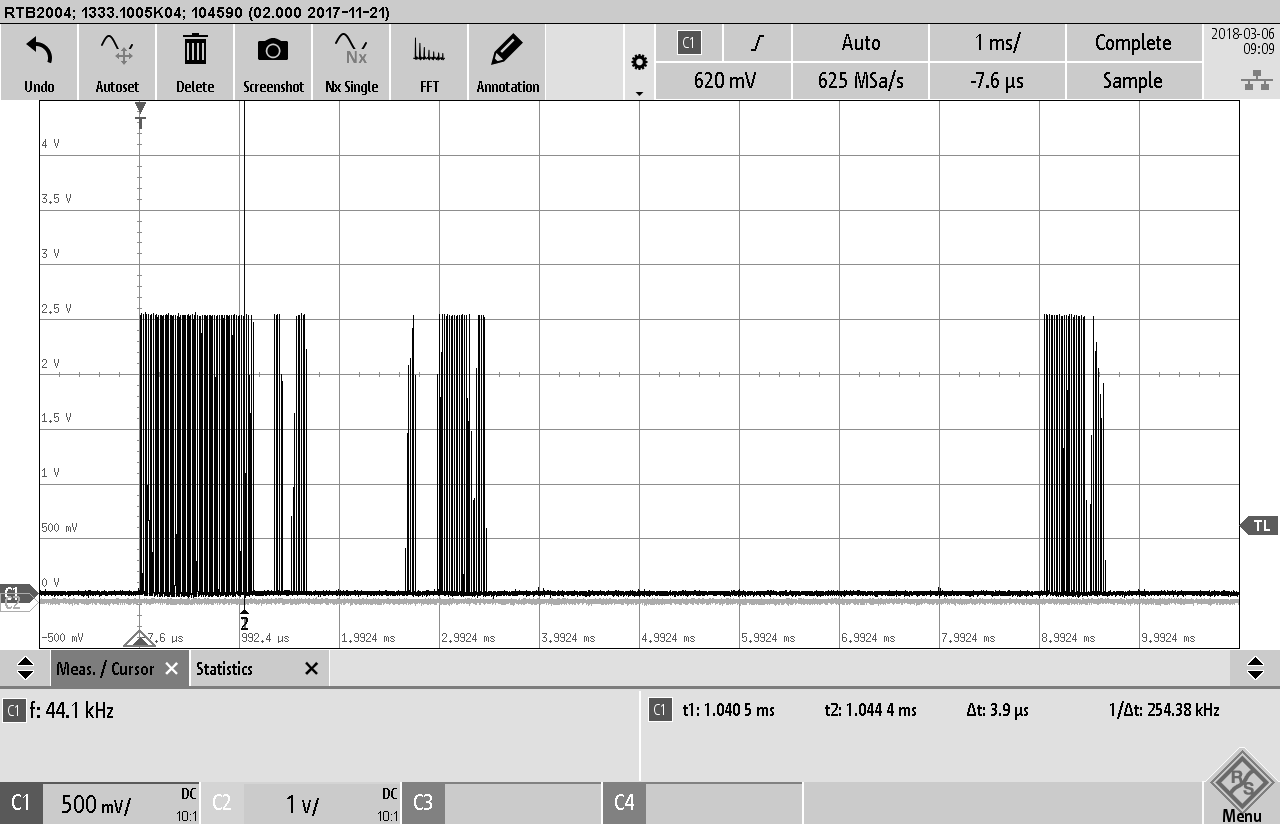
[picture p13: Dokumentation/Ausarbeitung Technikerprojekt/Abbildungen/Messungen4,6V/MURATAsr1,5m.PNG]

\captionof{figure}{MURATA sender+reciver}
\label{fig:EKULIT1,5m}
\end{minipage}

%\section{Signalverlauf nach Verstärkung durch den OPV}
%Durch die Verbindung der Sender- und der Empfängerseite entstand das Problem, dass die Entstörkondensatoren am Empfänger durch den Sendebetrieb zu sehr aufgeladen wurden, und sich danach erstmal entladen mussten, was eine Spannung am Sender/Empfänger zur Folge hatte. Das Entladen der Kondensatoren dauerte länger als die Pausen zwischen den Sendeimpulsen, dadurch konnten keine Signale empfangen werden.Um dieses Problem zu beheben wurde versucht, die OPV's durch einen MOSFET vom Sensor zu trennen, so lange gesendet wird. Da dieses erfolglos blieb wurde der Empfänger durch eine weitere Filterstufe erweitert.

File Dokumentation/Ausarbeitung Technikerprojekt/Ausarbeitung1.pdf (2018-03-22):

# Entwicklung und testen eines Ultraschall-Entfernungsmessers als Vorbereitung eines Produktentwurfes

# Projektarbeit

## erstellt an der Fachschule für Technik des Carl-Severing-Berufskolleg für Metall- und Elektrotechnik der Stadt Bielefeld

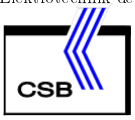
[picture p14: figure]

## Erstellt durch:

## Eduard Meiser Omar Hachimi Stephan Dannat FET6A

## in Zusammenarbeit mit der Fa. Tinkerforge betreut durch Herr Simon

## Bielefeld, 22. März 2018

## Persönliche Erklärung

Hiermit bestätigen wir, dass die vorliegende Arbeit selbstständig verfasst und keine anderen als die angegebenen Hilfsmittel benutzt wurden. Die Stellen der Arbeit, die dem Wortlaut oder dem Sinn nach anderen Werken (dazu zählen auch Internet-quellen) entnommen sind, wurden unter Angabe der Quellen kenntlich gemacht.

Bielefeld,
Eduard Meiser

Omar Hachimi

Stephan Dannat

# Inhaltsverzeichnis

1 Einleitung | 1

1.4 Richtlinien zu Erstellung von Schaltplänen und Platinenlayout anhand einem ECAD-

2 Vorbereitung | 4
3 Messungen und Auswertung der Ergebnisse | 12
4 Reektion über den Projektablauf | 19
5 Anhänge | 20

i

# 1 Einleitung

## 1.1 Zusammenfassung

Bei dieser Projektarbeit wurden Messungen an einem zuvor selbst entworfenen Prototyp eines Ultraschall-Entfernungsmessers durchgeführt. Das geschah im Auftrag der Firma Tinkerforge, um herauszunden, wie sich ein solcher Sensor realisieren lässt. Dabei gab es zwei Möglichkeiten und entsprechend dieser auch zwei unterschiedliche Prototyp-Versionen. Begonnen wurde mit einer Variante mit getrenntem Sende- und Empfangsbetrieb, auf zwei Platinen aufgebaut. Danach wurde eine zweite Variante mit kombiniertem Betrieb, auf einer Platine aufgebaut. Diese zweite Prototyp-Version besaÿ nur noch eine Ultraschallkapsel für den Sende- und Empfangsbetrieb Trotz mehrerer notwendiger Veränderungen an den Platinen lieÿen sich Aussagekräftige Messungen durchführen.

## 1.2 Lastenheft

1.2.1 Über Tinkerforge

Die Tinkerforge GmbH wurde Ende 2011 mit dem Ziel gegründet, die Handhabung eingebetteter Systeme zu vereinfachen. Das Tinkerforge Baukastensystem besteht aus aktuell fast 80 verschiedenen Modulen, die vom Anwender exibel für die jeweilige Aufgabe kombiniert werden können. Zu den Modulen zählen diverse Sensor- Aktor- und Schnittstellenmodule, die alle über Hochsprachen wie C#, Python und Java gesteuert werden können. Tinkerforge unterstützt aktuell 17 verschiedene Programmiersprachen. Sowohl Hardware als auch die Software aller Module sind OpenSource. Die Stärke des Baukastensystems ist aus Anwendersicht die enorme Flexibilität, die Einfachheit und die Schnelligkeit mit der Projekte realisiert werden können. Es eignet sich daher besonders im Bereich Rapid Prototyping. Daher ndet das Tinkerforge Baukastensystem Anwendung in vielen Forschungsinstituten, in diversen Entwicklungsabteilungen bekannter Automobilhersteller und Ingenieurbüros.

1.2.2 Motivation

Diese Technikerarbeit soll die Grundlage zur Entwicklung eines Entfernungssensors für das Baukastensystem bilden, der auf einer Ultraschall-Entfernungsmessung basiert. Das Baukastensystem verfügt aktuell über so einen Sensor. Bei diesem handelt es sich um ein zugekauftes Modul, welches nicht die gewünschten Leistungen liefert. Daher soll an einem zu entwerfenden Prototypen Forschung betrieben werden, um eine eigene Lösung entwerfen zu können.

1.2.3 Aufgabenbeschreibung

Innerhalb dieser Arbeit soll der Entwurf eines Prototypen des Entfernungssensors und die damit verbundene Forschung durchgeführt werden. Dabei ist durch Recherche zu erarbeiten, welche Möglichkeiten zur Realisierung zur Verfügung stehen. Durch Messungen am Prototypen soll festgestellt werden, welche dieser Möglichkeiten funktional realisierbar sind, um ein eigenes Produkt zu erstellen.

Diverse Teilaufgaben sind zu erledigen:

Recherche
Zu Anfang muss recherchiert werden, welche Möglichkeiten es gibt mittels Ultraschall eine

Entfernung zu ermitteln und wie diese technisch umgesetzt werden können. Zusätzlich müssen die Techniker sich mit dem Tinkerforge Baukastensystem und seiner internen Funktionsweise vertraut machen.

Bauteilauswahl
Abhängig von der gewählten technischen Umsetzung müssen geeignete Komponenten ausgewählt werden. Die Auswahl sollte auch unter dem Gesichtspunkten Preis, der Bauteilverfügbarkeit und der technischen Anforderungen erfolgen.

Schaltplanentwurf und Layouterstellung
Von Tinkerforge wird das Open Source CAD Programm KiCad verwendet. Mit diesem Programm ist ein Schaltplan für den Prototypen und anschlieÿend ein Leiterplattenlayout zu erstellen.

Leiterplattenbestückung
Die erstellte Leiterplatte wird von Tinkerforge in Auftrag gegeben. Diese muss mit den gewählten Komponenten bestückt werden. Die Tinkerforge GmbH stellt dazu die notwendigen Werkzeuge bereit.

Einrichten und Einarbeitung in die Tinkerforge Toolchain
Viele Softwarekomponenten werden von der Tinkerforge Toolchain automatisch generiert. Um diese Nutzen zu können muss ein Linux System eingerichtet werden. Anschlieÿend muss sich mit der Funktionsweise des Generators und der Softwareversionsverwaltung Git vertraut gemacht werden.

Testsoftware und Forschung
Um Messungen an der Hardware durchführen zu können gilt es Programmblöcke zu entwerfen, mit denen die einzelnen Funktionen der Baugruppen getestet werden können. So soll ermittelt werden, wie zum einen das Ultraschallsignal eektiv ausgegeben werden kann und wie sich die Signalamplitude auf die Reichweite auswirkt. Zum anderen gilt es zu recherchieren, wie das zurückkommende Signal verarbeitet werden kann. Auch soll erarbeitet werden, wie gut das Signal unter verschiedenen Bedingungen verarbeitet werden kann und ob eine zuverlässige Verarbeitungsqualität ohne groÿen Aufwand realisierbar ist.

## 1.3 Management des Projektes

1.3.1 Trello

Zur zeitlichen Planung und Übersicht des Ablaufes wurde auf das Onlinetool Trello zurückgegrien. Dieses ist ein kostenfreies, webbasiertes Projektmanagementtool. Es ermöglicht den Gruppenmitgliedern gleichzeitig von verschiedenen Orten auf die Oberäche zuzugreifen und Änderungen vorzunehmen. So kann ein Teilnehmer auch neue Termine mit Kennzeichnung der Fälligkeit für andere Gruppenmitglieder einfügen, oder bereits erledigte Aufgaben für alle abhaken. Auch können hier relevante Dokumente, die alle Gruppenmitglieder lesen sollen hochgeladen, und bei Bedarf noch kommentiert werden. Für die Dokumentation lässt sich an diesem System auch einfach abgleichen, zu welchen Zeitpunkten die einzelnen Aufgaben abgeschlossen wurden.

1.3.2 Github

Bei Github handelt es sich um einen webbasierten Online-Dienst, der Server für Entwicklungsprojekte mit einer Versionsverwaltung bereitstellt. So können alle Daten nach einer Änderung im Programm wieder hochgeladen und mit einem Kommentar versehen werden. Sollte nach mehreren Änderungen ein Problem auftreten, kann einfach auf eine ältere Version zurück gegrien und so der Fehler eingegrenzt werden. Auch kann ein Projekt in mehrere Abschnitte aufgeteilt werden, damit mehrere Personen unabhängig voneinander daran arbeiten können. Nach der Bearbeitung können diese wieder zusammengefügt werden. Dabei ist erkennbar, welche Änderungen von wem vorgenommen wurden. So können alle Vorgänge jederzeit verfolgt werden, um eine gröÿtmögliche Übersicht zu gewährleisten. Durch das Kommentieren der Änderungen kann die Nachvollziehbarkeit dieser ebenfalls deutlich gesteigert werden. Des weiteren ist diese Plattform gerade für Unternehmen wie Tinkerforge, die ihren Quellcode als Open-Source anbieten besonders praktisch, da den Nutzern hier alle veröentlichten Daten direkt zur Verfügung stehen.

## 1.4 Richtlinien zu Erstellung von Schaltplänen und Platinenlayout anhand einem ECAD-Programmpaket

Das Open Source ECAD-Programm KiCAD ist eine Anwendung zum Erstellen von Schaltplänen und elektronischen Leiterplatten. Mit einem solchen Programm lassen sich die erstellten Schaltpläne vor einer Leiterplattenerstellung auf Verdrahtungsfehler prüfen, um spätere Probleme zu vermeiden.

1.4.1 Schaltplan

Beim Schaltplanentwurf gilt es auf gewisse Regeln zu achten, zu dem ist auf die Übersichtlichkeit des Schaltplans zu achten. So sollten beispielsweise Filterkondensatoren an der Spannungsversorgung des Mikrocontrollers eingeplant werden, um die Versorgungsspannung zu stabilisieren. Auch ist schon bei dem Entwurf des Schaltplans an das spätere Platinenlayout zu denken. So muss bei der Platzierung der Bauteile darauf geachtet werden, dass die Signalintegrität gewährleistet ist, und es zu keiner Potential Verschiebung kommt.
Im Schaltplan wurden die Baugruppen Empfänger, Sender, Hochsetzsteller und die Anschlüsse vom Controller getrennt und so positioniert, dass die beste Übersicht dargestellt wird.
Um die einzelnen Bestandteile separat testen zu können, wurden dem Design NULL Ohm Widerstände, an den Verbindungspunkten, hinzugefügt. Auÿerdem ist es dadurch möglich, eine Zerstörung einzelner Baugruppen durch einen Verdrahtungsfehler bei der Erstinitialisierung zu vermeiden.

1.4.2 Platinenlayout

Beim Entwerfen eines Platinenlayouts gibt es viele Möglichkeiten ein Ergebnis zu erzielen. So können alle Bauteile so angeordnet werden, dass alle parallelen Bauteile nebeneinander aufgereiht werden und die in Reihe dazu liegenden Bauteile darunter angeordnet sind. So sähe die Platine zwar ähnlich eines Kontaktplanes aus, allerdings ist diese Variante aus Sicht der EMV nicht sonderlich empfehlenswert.
Eine andere Möglichkeit wäre, die Bauteile schon im Schaltplan in Gruppen zusammenzulegen und den Schaltplan auf der Platine exakt nachzubilden. Auch bei dieser Variante ergeben sich gelegentlich Probleme, was die Führung der Leitungen und vor allem den Verlauf der Ströme angeht.
So sollte ein Augenmerk auf den stromführenden Leitungen liegen. Je höher der Strom ist, desto breiter und kürzer ist die Leitung auszulegen, um weniger EMV-Störungen zu erzeugen. Auch sollte die Rückführung (GND) günstigerweise als eigene Leiterschicht ausgeführt werden, um einen groÿen Leiterquerschnitt zu gewährleisten. So kann bei der Rückführung der Ströme auch das Risiko vermieden werden, durch Bildung von gröÿeren Schleifen, Antennen zu erzeugen. Die GND-Schicht sollte so wenig wie möglich unterbrochen werden, vor allem sind Unterbrechungen quer zur Strom-ussrichtung zu vermeiden. Zusätzlich ist zu beachten, dass Kondensatoren, die der Verringerung von Störenden Spannungsschwankungen dienen, nahe schaltenden Bauteilen angebracht werden. Die optimale Platzierung ist direkt am VDD oder VCC des ICs, so dass die Leiterbahn vor dem IC mit einem höheren Querschnitt am Kondensator liegt und dann mit leicht verringertem Querschnitt an das IC angeschlossen ist.

# 2 Vorbereitung

Bevor ein erster Entwurf der Schaltpläne durchgeführt werden konnte, mussten Informationen zu den zu verwendenden Bauteilen eingeholt werden, um sicherzustellen, dass diese auch die passenden Betriebsparameter haben und untereinander kompatibel sind.

## 2.1 Recherche der Funktionsweise

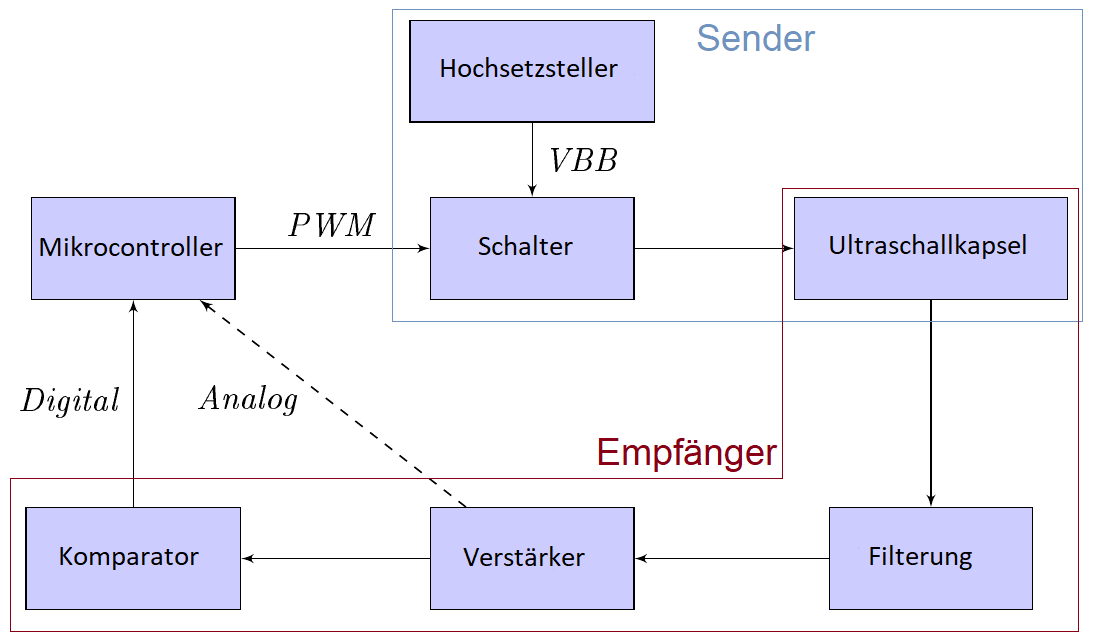
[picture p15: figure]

Abbildung 2.1: Blockschaltbild des Ultraschall-Entfernungsmessers

Die Abbildung 2.1 zeigt eine vereinfachte Funktionsübersicht der Platine. Die Schaltpläne zu den verschiedenen Ausführungen der Platine sind den Anlagen beigefügt.

2.1.1 Mikrocontroller

Der Mikrocontroller soll eine stabile und variable PWM ausgeben können. Es werden für die Zeiterfassung und die PWM Ausgabe mehrere Timer benötigt, die sowohl intern als auch über die Hardware angesteuert werden können. Ein Analog/Digital-Wandler sollte ebenfalls vorhanden sein.

2.1.2 Sender

Der Sender soll Schallwellen im Ultraschallbereich (40 kHz) aussenden. Diese sollen einen ausreichenden Schalldruck haben um von Hindernissen, die mehrere Meter entfernt sind, ein Echo erhalten zu können. Dafür muss die Ultraschallkapsel mit einem sinusähnlichen Signal angesteuert werden. Dessen Amplitude muss angemessen hoch sein, um den gewünschten Schalldruck zu erzeugen. Der Controller ist auf eine Spannungsebene von 3,3 V begrenzt. Um höhere Spannungen an der Ultraschallkapsel realisieren zu können, muss ein Schalter als weiteres Bauteil dazwischen geschaltet werden. Dieses zusätzliche Bauteil dient als Trennung zwischen den 3,3 V des Mikrocontrollers und der höheren Spannungsebene der Lautsprecherkapsel. Dabei muss darauf geachtet werden, dass der Schalter schnell genug arbeitet, um die 40 kHz auch zuverlässig schalten zu können.

2.1.3 Hochsetzsteller

Der Hochsetzsteller generiert aus den 5 V Versorgungsspannung eine höhere Spannung für den Sendebetrieb. So kann der Schalldruck, der ausgegeben wird erhöht werden (gröÿere Reichweite/-gröÿeres Rücksignal) siehe Abbildung 3.14.
Die Funktionsweise des Hochsetzstellers (Spannungspumpe/Aufwärtswandler/Aufwärtsregler) ist überschaubar und ndet in vielen Bereichen Anwendung. Grundsätzlich wird eine Induktivität in Reihe mit einer Freilaufdiode vor einen Ladekondensator geschaltet. Dieser liegt parallel zum Ausgang. Zwischen der Spule und der Diode ist ein Schalter angeschlossen, der die Spule gegen Masse schaltet. Die Spule lädt sich bei Betätigung des Schalters auf. Durch den Stromuss entsteht ein Magnetfeld und beim Önen steigt die Spannung am sekundären Ende der Spule. Durch das zusammenbrechende Magnetfeld an und lädt den Kondensator auf. Dieser Vorgang wird wiederholt bis der Kondensator so weit aufgeladen ist, dass die Ausgangsspannung den gewünschten Wert hält. Die mögliche Ausgangsspannung ist nicht unbegrenzt über das Schaltspiel regelbar. Sie ist von den Eigenschaften der Komponenten abhängig.

2.1.4 Ultraschallkapsel

Für das Senden und Empfangen des Ultraschalls wird eine auf Piezomodulen basierende Ultraschallkapsel verwendet, weil Sie die Möglichkeit hat ein Signal auszugeben sowie zu empfangen und in Kleinbauform erhältlich ist. Wie stark das Nachschwingen der Kapsel eine Auswirkung auf die Empfängerschaltung hat, sowie die Gröÿe der Störfrequenz bei verschiedenen Amplituden auf unterschiedlichen Entfernungen sollte überprüft werden. Es sollte auch getestet werden welche Kapseln sich für einen stand-alone Betrieb am besten eignen.

2.1.5 Filter

Die Filterschaltung soll am Eingang des Empfängers mögliche Störfrequenzen herauszultern um eine Verfälschung der gemessenen Strecke zu vermeiden, da die Ultraschallkapsel nicht ausschlieÿlich Ultraschallsignale aufnimmt. Für Hochefrequenzen eignet sich eine passive Hochpasslter-Schaltung, es wird zu einem Kondensator oder einer Spule ein Widerstand parallel zur Masse bestückt.

2.1.6 Empfänger

Im Empfangsbetrieb werden die zurückkommenden Schallsignale, die auf die Ultraschallkapsel treffen, in sinusförmige Spannungssignale umgewandelt. Die Amplitude hängt von dem Schalldruck der empfangenen Signale ab und ist deutlich niedriger als die Amplitude der gesendeten Signale. Diese Signale müssen anschlieÿend verstärkt werden, um sie mit dem Mikrocontroller auswerten zu können. Zur Vereinfachung der Auswertung wird das eingehende analoge Signal in ein digitales Signal umgewandelt, um Verarbeitungsaufwand einsparen zu können. Die Auswertung eines Analogsignals erfordert mehr Programmieraufwand als die Auswertung eines Digitalsignals. Um die Qualität der gemessenen Entfernung besser zu beurteilen sollte eventuell auch das Analogsignal ausgewertet und mit dem digitalen Signal verglichen werden.

## 2.2 Verwendete sowie Dimensionierung der Bauteile

Bevor ein erster Prototyp erstellt werden konnte, mussten die richtigen Bauteile ausgewählt werden. Dies Geschah unteranderem anhand der gewonnenen Informationen aus dem Kapitel 2 Vorbereitung.

2.2.1 Mikrocontroller

Der Inneon XMC 1404_Q048 gehört zur der Familie der ARM Cortex -M0 Prozessoren und ist ein 32-bit Industrial Microcontroller, wird mit 48 MHz externer Clock betrieben. Die 48 im Namen des Prozessors steht für die Anzahl der Pins. Der interne Timer läuft mit 96Mhz. Die CCU4 des Prozessor bietet ein 2x4 16 bit Timer. Auÿerdem hat der XMC einen 12 bit A/D Wandler, welcher für die Analogmessung eine genauere Auösung bieten kann als ein 8 bit A/D Wandler. Die Betriebsspannung des Prozessors beträgt 3,3 V. Die Auswahl des Controller wurde getroen, weil dieser standardmäÿig auch schon bei Tinkerforge eingsetz wird und uns für den Prototypen vorgegeben wurde.

2.2.2 Sender

Um eine Trennung zwischen der CPU (3,3 V) und dem Hochsetzsteller (5 V-20 V)zu ermöglichen, wurde ein weiteres Bauteil benötigt. Dafür wurde das IC A5950 (Voll Brücke) ausgewählt. Diese H-Brücke kann eine angeschlossene Last mit der vom Hochsetzstellers erzeugten Spannung versorgen. Deren Frequenz wird über das Signal an dem Anschluss Phase von der CPU vorgegeben. An den Anschlüssen Out1 und Out2 wird das Ausgangssignal abgegrien. Für die genaue Beschaltung des ICs siehe Anhang Datenblatt Schimatic A5950.

2.2.3 Hochsetzsteller

Tinkerforge nutzt schon eine Variante eines Hochsetzstellers auf ihren Platinen. Der Aufbau und die Bauteilauswahl musste nur auf die variable Ausgangspannungs erweitert werden. Die Standardschaltung, von Tinkerforge, wurde an dem Eingang der Feedbackspannung mit einem Potentiometer (RV1) erweitert, um die gewünschte Variable Spannung zu generieren.
Die Ausgangsspannung wird mit den externen Widerständen RV1, R13 und R2 eingestellt (siehe Grundschaltung Datenblatt vom IC LRM62014x, Seite 11). Ein Wert von ca. 13, 3 kΩ wurde für R2 empfohlen. Mit den Potentiometer (RV1) lässt sich die Ausgangsspannung bei 5 V Eingangsspannung bis 21,5 V einstellen. In der Formel werden die Widerstände RV1 und R13 zum Ersatzwiderstand(Re) zusammengefasst.

Re = R2 ∗

Vout
1, 23

− 1

⇒ Vout =
Re
R2

+ 1
∗ 1, 23

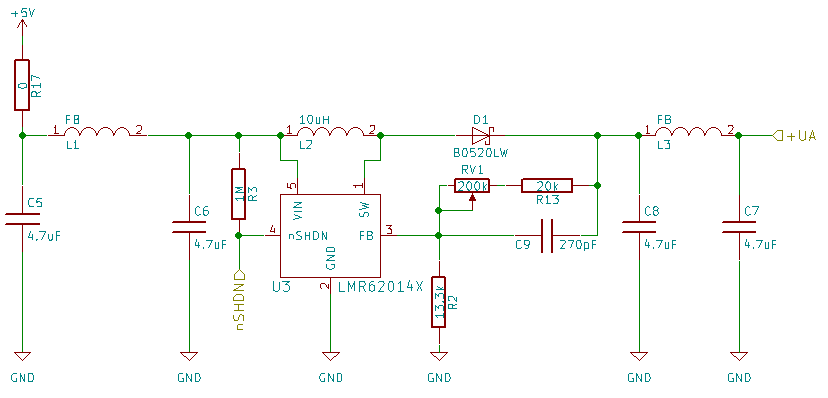
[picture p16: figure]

Abbildung 2.2: Schaltplan des beschalteten Hochsetzstellers

2.2.4 Ultraschallkapsel

Für den Prototypen wurden mehrere Kapseln verschiedener Hersteller bestellt. Dieses geschah um Unterschiede der verschiedenpreisigen Bauteile zu ermitteln und festzustellen welches Preissegment die nötige Qualität für die vorliegende Anwendung erfüllt.

2.2.5 Filter

Um unerwünschte Signalanteile mit Frequenzen, die unter 40 kHz liegen, zu unterdrücken musste die Filterschaltung mit einem Hochpasslter (CR Glied) bestehend aus einem Kodensator und einem Widerstand bestückt. Der Widerstand wurde nach der e24 Reihe ausgewählt. Die Kapazität des Kondensators wurde an die Grenzfrequenz von 40 kHz und den Widerstand angepasst.

C =

1
2 ∗ pi ∗ fg ∗ R

⇒

1
2 ∗ pi ∗ 40 kHz ∗ 100 KΩ

≈ 40 pF

Anhand der Berechnung wurde für den Hochpasslter ein Kondensator mit 39 pF genommen.

2.2.6 Empfänger

Die Abbildung 2.3 zeigt die Empfängerschaltung. Durch diese Verschaltung von Operationsverstärkern wird das ankommende sinusförmige Signal verstärkt und in ein digitales Signal umgewandelt. Für die Verstärkung der Amplitude so wie der Umwandlung des analogen Signals in ein Rechtecksignal mit 40 KHz wurde der TLC272 ausgewählt, weil er günstigem Stückpreis ist und die Technischenspezikationen ausreichend sind. Für die Verstärkung der Amplitude ist der Operationsverstärker TLC272 U2B als nicht invertierender Verstärker geschaltet.

Für die Umwandlung des analogen Signales in ein digitales wurde der Operationsverstärker TLC272 U2C als Komparator geschaltet. Beim Auftreten von Dierenzen zwischen den Eingangssignalen, wechselt der Ausgang des Komparators zwischen Low (0 Volt) auf High (3,3 Volt).
Die Referenzspannung (Uref ) wird durch den Spannungsteiler R9 und R8 bestimmt.

Uref =

Uges ∗ R9
R8 + R9

⇒

3, 3 V ∗ 120 KΩ
100 KΩ + 120 KΩ

= 1, 8 V

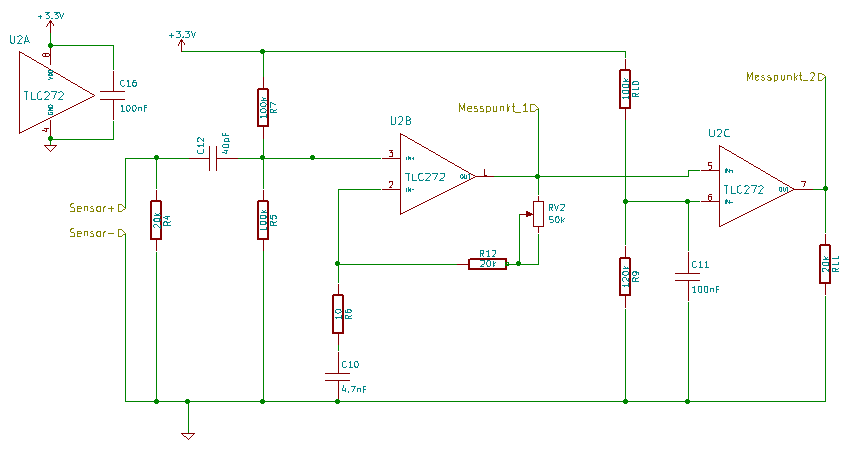
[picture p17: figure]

Abbildung 2.3: Schaltplan zweier Operationsverstärker mit einer vorgelagerten Filterung als Empfängerschaltung

## 2.3 Entwicklung der Software zum Betrieb des Prototypen

2.3.1 Benötigte Kenntnisse

Um das Programm zu erstellen sollten Kenntnisse z.B. für die Capture Compare Unit des Mikrocontrollers vorhanden sein. Die CCU4 hat insgesamt 4 Einheiten und jede einzelne besitzt mehrer Slices von CC40 bis CC43. Slices können untereinander verschachtelt werden um so z.B. Interrupt Service Routinen aufzurufen, siehe dazu das Reference Manuel. Die Werte der Register mit denen die Zeit gemessen wird müssen sofort zum beginn der Interrupt Service Routine zwischengespeichert werden damit sichergestellt wird das nicht die Zeit zur Brechung mit gemessen wird.

Durchgeführte Berechnungen

Auch für die Programmierung waren diverse Berechnungen notwendig. Zur Erzeugung der Ultraschallimpulse wurde ein pulsweitenmoduliertes Rechtecksignal mit einer Frequenz von 40 kHz generiert. Dafür war es notwendig mit Hilfe der CCU4 einen Timer zur erstellen. So musste bei einem Timertakt von 96 MHz eine Periodendauer von 2400 Takten und einem Compare_Wert von 1200 Takten konguriert werden. Im Zählvorgang des Timers wird der Ausgang nach erreichen des Compare-Wertes auf 1 gesetzt, und nach erreichen der Periodendauer wieder auf 0 zurückgesetzt. Dadurch ergibt sich eine Periodendauer von 25 µs, was einer Frequenz von 40 kHz entspricht. Die Zeit die vergeht bis das Echo des Ultraschall-Impulses zurück kommt wird über einen Timer erfasst.

Periodendauer =

96 MHz
40 kHz = 2400, Compare_Wert =

2400
2

= 1200

2.3.2 Quellcodeentwurf

Programmstruktur:
In dem Hauptprogramm main.c benden sich nur Funktionsaufrufe die eine Grundkonguration für den Mikrocontroller beinhaltet und eine Schleife die immer wieder abgerufen wird um z.B. eine neue Entfernungsmessung zu starten, siehe Abbildung 2.4. Anstatt den gesamten Programmcode im Hauptprogramm zu verfassen was bei komplexen Programmen schnell zu Unübersichtlichkeit führt hat das Auslagern den Vorteil, dass der Quellcode Logisch getrennt werden kann was eine Verschlankung des Quellcodes mit sich bringt. Somit stehen in dem Hauptprogramm nur noch die Aufrufe der separat verfassten Funktionen. Auch vereinfacht diese Struktur gerade bei Prototypen das Testen der Funktion. So kann im Falle einer fehlerhaften Funktion einfach ein Aufruf auskommentiert werden um zu testen, ob der Fehler wirklich von der Funktion herrührt. Dadurch müssen nicht etliche Zeilen Programmcode einer Funktion auskommentiert werden. Dadurch ist die Fehlerrate durch übriggebliebene Zeichen, oder gar beim entfernen der Auskommentierung gelöschte Zeichen deutlich gesenkt.

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

21

22 | }
23 | }

Abbildung 2.4: Quellcode der main.c des Distance US

Die verwendete Vorgehensweise bei der Programmierung arbeitet mit einer gewissen Verschachtlung. In den *.c Dateien bendet sich zwar der Groÿteil des des aktiv geschriebenen Programms, doch ste-

hen die Funktionsdenitionen in den Headerdateien, wie der a16pt.h 2.5

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

Abbildung 2.5: Inhalt der Headerdatei a16pt.h

Init Aufruf: In der Abbildung 2.6 ist ein Teilausschnitt aus der a16pt.c zu sehen. Dieser enthält zwei verschiedene PWM kongurationen, die auf den Ports P4_4 und P4_6 ausgegeben werden.

1 | v oid a 1 6 p t_i ni t ( v oid )
2 | {
3 | /* **************** E x te rne_ In te r rup t ****************** */

4
5 e r u_i ni t ( eru_port ) ;

6

7 /* ***********PWM_Init**************************** */

8
9 | XMC_CCU4_Init(CCU41, XMC_CCU4_SLICE_MCMS_ACTION_TRANSFER_PR_CR_PCMP) ;
10 | XMC_CCU4_StartPrescaler (CCU41) ;

11
12 | ccu4_pwm_init (pwm_port_0 , cc40 , period_1 ) ; //P4_4
13 | ccu4_pwm_set_duty_cycle ( cc40 , compare_1 ) ;

14
15 | ccu4_pwm_init (pwm_port_1 , cc42 , period_0 ) ; //P4_6
16 | ccu4_pwm_set_duty_cycle ( cc42 , compare_0 ) ;
17 | . . .

Abbildung 2.6: Ein Teilausschnitt aus der a16pt.c mit Kongurationen von Funktionen

Interrupt Aufruf: In der Abbildung 2.7 :a16pt.c Interrupt Request, werden die für die Entfernungsmessung notwendigen Funktionen und die Interrupt Anweisungen, in dem Fall die IRQ21, abgearbeitet. Auÿerdem werden die Timer synchron abgeschaltet und aus experimentellen gründen wurde ein weiterer Impuls generiert um zu beobachten wie sich das Nachschwingen bei einer längeren Kurzschlusszeit an der Ultraschallkapsell verhält. Die IRQ wird auch als Interrupt Request bezeichnet und wird von der Hardware oder von der Software ausgelöst.

1

2 /* ************ In te r rup t_Funk ti onen *************** */

3
4 | v oid IRQ_Hdlr_21 ( v oid ) // Compare I n t e r r u p t c o u n t e r 10
5 | {

6
7 | // Di s a bl e IRQs s o we can ' t be i n t e r r u p t e d
8 | __disable_irq ( ) ;

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

12
13 | // Stop s l i c e 2
14 | XMC_CCU4_SLICE_StopClearTimer (CCU41_CC40) ;

15
16 // For s l i c e 1 we w ai t u n t i l PWM i s run through ( t o g e t e x a c tl y 10 pwm peaks on P4_4 and P4_6)
17 w hil e (XMC_CCU4_SLICE_GetTimerValue(CCU41_CC42) > compare_1 ) {

18
19 | __NOP( ) ;
20 | }

21
22 | //New pin c o n f i g u r a t i o n
23 | c o n s t XMC_GPIO_CONFIG_t pin_out_con fig | = {
24 | . mode | = XMC_GPIO_MODE_OUTPUT_PUSH_PULL,
25 | . o u t p u t_l e v el | = XMC_GPIO_OUTPUT_LEVEL_HIGH,
26 | } ;

27
28 | XMC_GPIO_Init(P4_6 , &pin_out_con fig ) ;
29 | //Creatw a hi gh impul se
30 | f o r ( s =0; s <50; s++)
31 | {
32 | __NOP( ) ;
33 | }
34 | // Stop s l i c e 0
35 | XMC_CCU4_SLICE_StopClearTimer (CCU41_CC42) ;

36
37 | //Pin c o n f i g u r a t i o n back t o the PWM−Mode
38 | c o n s t XMC_GPIO_CONFIG_t gpio_ou t_con fig1 | = {
39 | . mode | = XMC_GPIO_MODE_OUTPUT_PUSH_PULL_ALT9,
40 | . i n p u t _ h y s t e r e si s | = XMC_GPIO_INPUT_HYSTERESIS_STANDARD,
41 | . o u t p u t_l e v el | = XMC_GPIO_OUTPUT_LEVEL_LOW,
42 | } ;

43
44 | XMC_GPIO_Init(P4_6 , &gpio_ou t_con fig1 ) ;
45 | // Enable IRQs a g ain
46 | __enable_irq ( ) ;

47

48

49 }

Abbildung 2.7: Ein Teilausschnitt von der a16pt.c mit einem Interrupt Request

# 3 Messungen und Auswertung der Ergebnisse

Für die Messungen wurden im Laufe des Projekts zwei Versionen an Prototyp-Platinen entworfen. Im Verlauf der Versuche wurden Veränderungen an den Platinen vorgenommen, um den Betrieb dieser zu verbessern.

## 3.1 Prototyp 1

Bei dem ersten Prototyp wurden die Sendereinheit und die Empfängereinheit auf getrennten Platinen aufgebaut. So bestand die Möglichkeit, den Senderkreis und den Empfängerkreis getrennt zu untersuchen, ohne dass sich elektrische Signale der beiden Schaltkreise überlagern konnten. Anfangs wurde für den Senderkreis eine komplette H-Brücke als Schalter verwendet. Allerdings war der Aufbau nicht funktional, da ein Beschaltungsfehler vorhanden war. Dieser wurde mit Fädeldraht provisorisch behoben. Dadurch, dass das A5950 eine H-Brücke mit integrierter Kontroll-Logik und eigener Spannungspumpe ist, wurde anhand der Schaltweise der Baugruppe festgestellt, dass diese H-Brücke nicht für die Schaltung einsetzbar ist. Um nicht sofort eine neue Platine in Auftrag geben zu müssen, was einiges an Zeit gekostet hätte, wurde das IC einfach ausgelötet. Danach wurde zunächst ein MOSFET als HIGH-Side an der Stelle eingesetzt.Dadurch lieÿen sich erste Versuche durchführen, allerdings entsprach das Ergebnis noch nicht den Anforderungen. Deswegen wurde die Beschaltung an dieser Stelle auf eine Halbbrücke erweitert. Damit war die Funktion des Senderkreises für die ersten Versuche und Messungen gegeben.
Der Empfängerkreis war von Beginn an funktional, konnte aber erst mit Inbetriebnahme des Senderkreises richtig getestet werden. Am Empfängerkreis wurden lediglich zu Testzwecken Änderungen an der Filterung, vor dem Verstärker, vorgenommen. Die Filterung wurde in ihrer Dimensionierung verändert, um herauszunden, wie sich die Qualität des Echo-Signals verbessern lässt.

3.1.1 Senderkreis

Zu erst wurden Signale direkt an der CPU gemessen, um sicher zu stellen, dass die Einstellungen im Programm auch die gewünschten Ausgaben zur Folge haben, und keine Gefärdung der Bauteile entsteht. Um das Signal für die Entfernungsmessung zu generieren wurde der Mikrocontroller so programmiert, dass zehn Impulse mit einer Frequenz von 40 kHz ausgegeben werden. Danach erfolgt eine Pause, um das zurückkehrende Signal abzuwarten und auszuwerten.

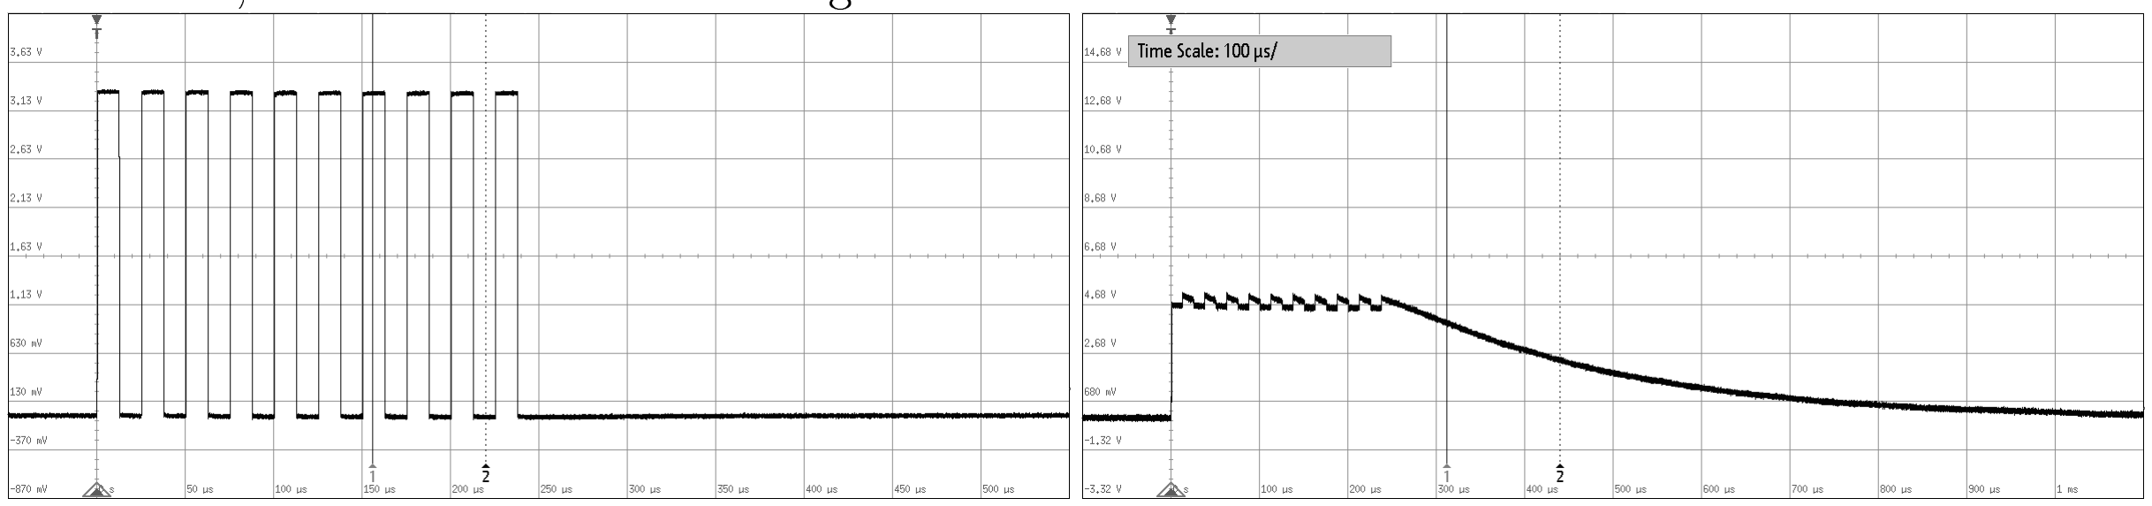
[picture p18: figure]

Abbildung 3.1: PWM-Burst auf 40 kHz Basis an der CPU

Abbildung 3.2: PWM Ausgabe | über | einen
HIGH-Side

In der Abbildung 3.1 ist zu sehen, dass der gewünschte Burst aus zehn Impulsen mit einer Periodendauer von jeweils 25 µs vom Mikrocontroller generiert wurde. Diese Messung wurde auch vorgenommen, um zu überprüfen, wie sich das Signal durch die eingesetzten Bauteile verändert.

Die Abbildung 3.2 zeigt, wie das Ausgangssignal nach einer HIGH-Side aussieht. So wird zwar im Takt des PWM-Signals geschaltet, allerdings fehlt es an einem Gegenpol, um das Potential in den Schaltpausen wieder auf Null zu ziehen. Dadurch bleibt die Spannung während des Schaltens immer auf einem erhöhten Pegel und sinkt erst nach Ende des PWM-Signals langsam ab. Dadurch kann natürlich keine vernünftige Ausgabe am Lautsprecher erzeugt werden, denn ohne deutliche Potentialunterschiede kann dieser auch nicht in Schwingungen versetzt werden. Der ausgegebene Schalldruck würde nur für kurze Entfernungsmessungen reichen. Das zurückkommende Signal wird von der abklingenden Spannung des HIGH-Side überlagert. Somit ist dieser Aufbau nicht operabel. Um die Spannung nicht nur auf einen HIGH-Pegel, sondern auch auf einen LOW-Pegel schalten zu können wurde danach auf eine Halbbrücke gewechselt. Mit dieser lässt sich der Ausgang, über zwei durch das PWM-Signal gesteuerte MOSFETs, sauber auf HIGH- oder LOW-Pegel schalten. Mit der verwendeten Halbbrücke ergab sich die Abbildung 3.3

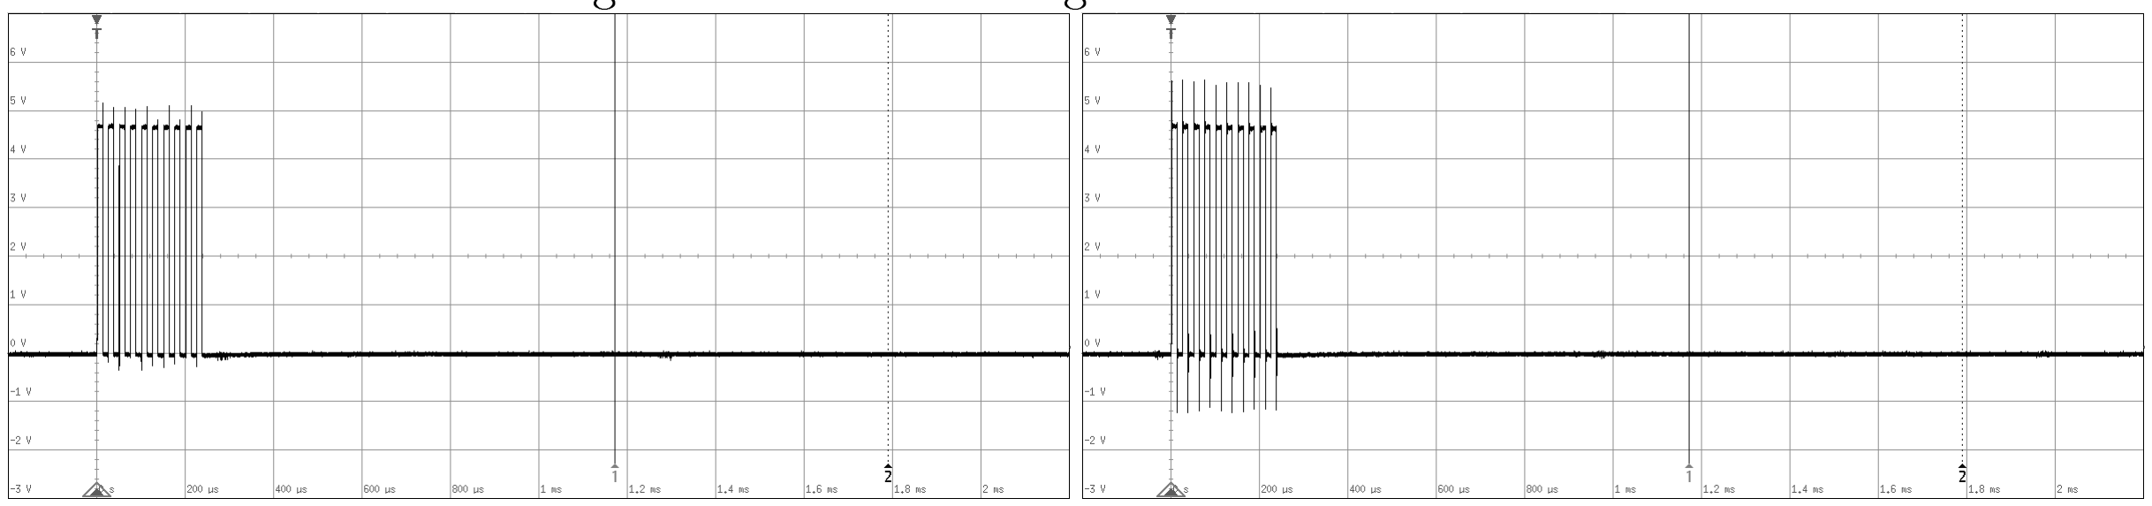
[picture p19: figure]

Abbildung 3.3: PWM Ausgabe über eine Halbbrucke

Abbildung 3.4: Ausgabe der PWM an der Ultraschallkapsel

Es zeigt sich, dass das Signal nach der Erweiterung auf eine Halbbrücke wieder wie das von der CPU ausgegebene PWM-Signal 3.1 aussieht. Die Amplitude fällt wie geplant höher aus. Somit kann die Höhe der Amplitude über die Spannungspumpe variiert werden um die Stärke des ausgegebenen Signals zu verändern, ohne die CPU durch die höhere Spannung zu beschädigen. Wie in der Abbildung 3.4 zu entnehmen ist, entstehen durch die angeschlossene Ultraschallkapsel höhere Spannungsimpulse in den Schaltmomenten. Diese Spannungsspitzen, die durch die Ultraschallkapsel entstehen, wurden in den Versuchen vernachlässigt, da keine Gefährdung anderer Bauteile entstand. Das somit generierte Ausgangssignal entsprach den Anforderungen und musste für die Versuche nicht weiter bearbeitet werden.

3.1.2 Empfängerkreis

Die Platinen des Sender- und Empfängerkreises wurden gemeinsam auf einer Halterung montiert, so dass die Ultraschallkapseln zum senden und empfangen der Signale nebeneinander befestigt werden konnten. Ziel war es, durch verschieben eines Hindernisses die Signaländerungen an den Platinen beobachten zu können, ohne die gesamten Messaufbauten bewegen zu müssen. Bei der Aufnahme der Messungen wurde der Empfängerkreis Schritt für Schritt überprüft um zu erfahren, wie sich das empfangene Signal durch die einzelnen Bauteile verändert.

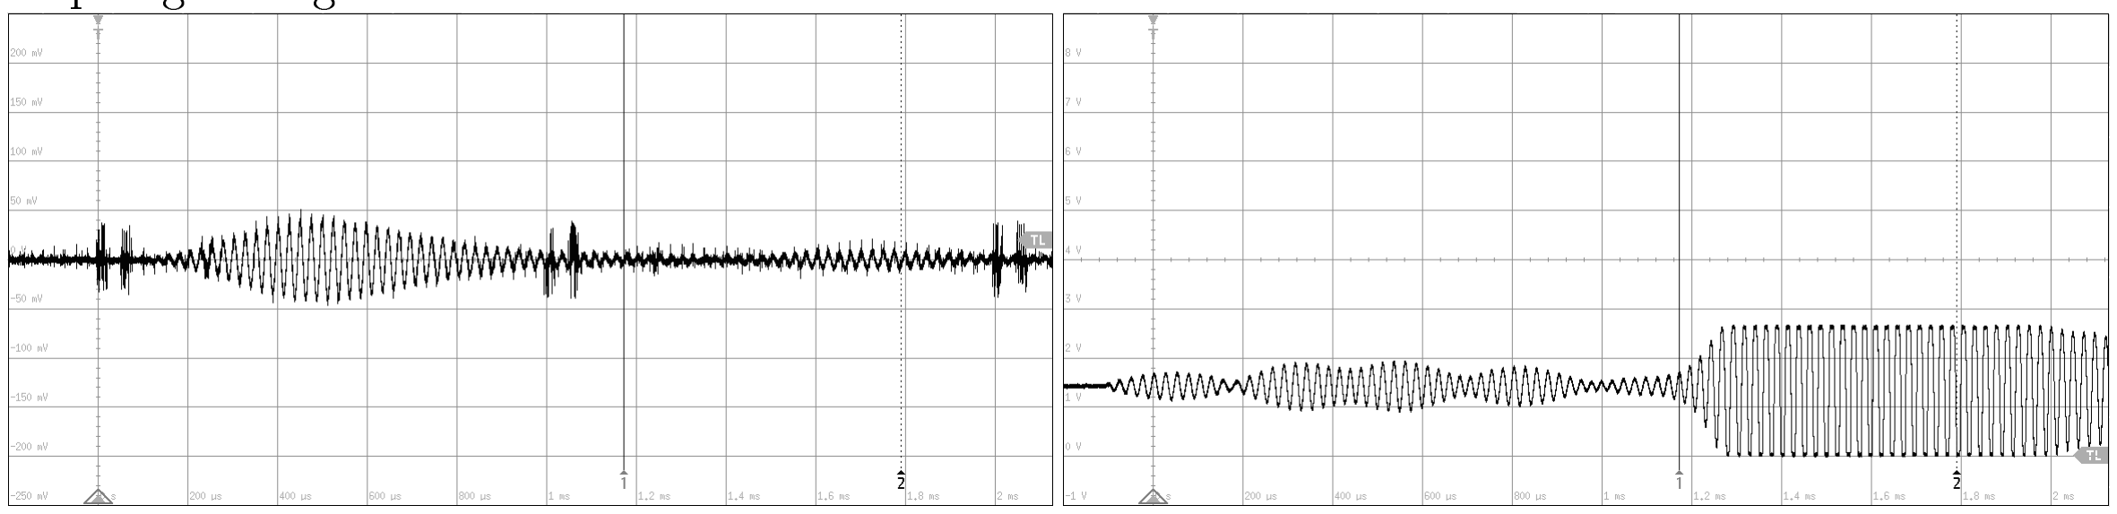
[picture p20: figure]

Abbildung 3.5: Signal Empfang | Abbildung 3.6: Signal nach Verstärkung

Die Abbildung 3.5 zeigt das Signal, das direkt am Empfänger zu messen war. Hier sind verschiedene vorerst nicht zuordenbare Signale zu sehen. Allein aus diesem Bild lässt sich daher keine Aussage zu den einzelnen Signalen machen. Fest steht nur, dass ebenfalls Signale die nicht der gewünschten Frequenz entsprechen, vom Empfänger aufgenommen werden. Dies gilt es natürlich schnellst möglich auszumerzen, um unerwünschte Störungen zu vermeiden. Die Abbildungen 3.6 und 3.7 zeigen den Verlauf des Signals nach der Filterung und Verstärkung in zwei verschiedenen Zeitauösungen. Dabei entspricht 3.6 den ersten drei Kästchen von 3.7 und dient um darzustellen, dass die Verstärkung eine maximale Aussteuerung von 3,3 V nicht überschreitet.

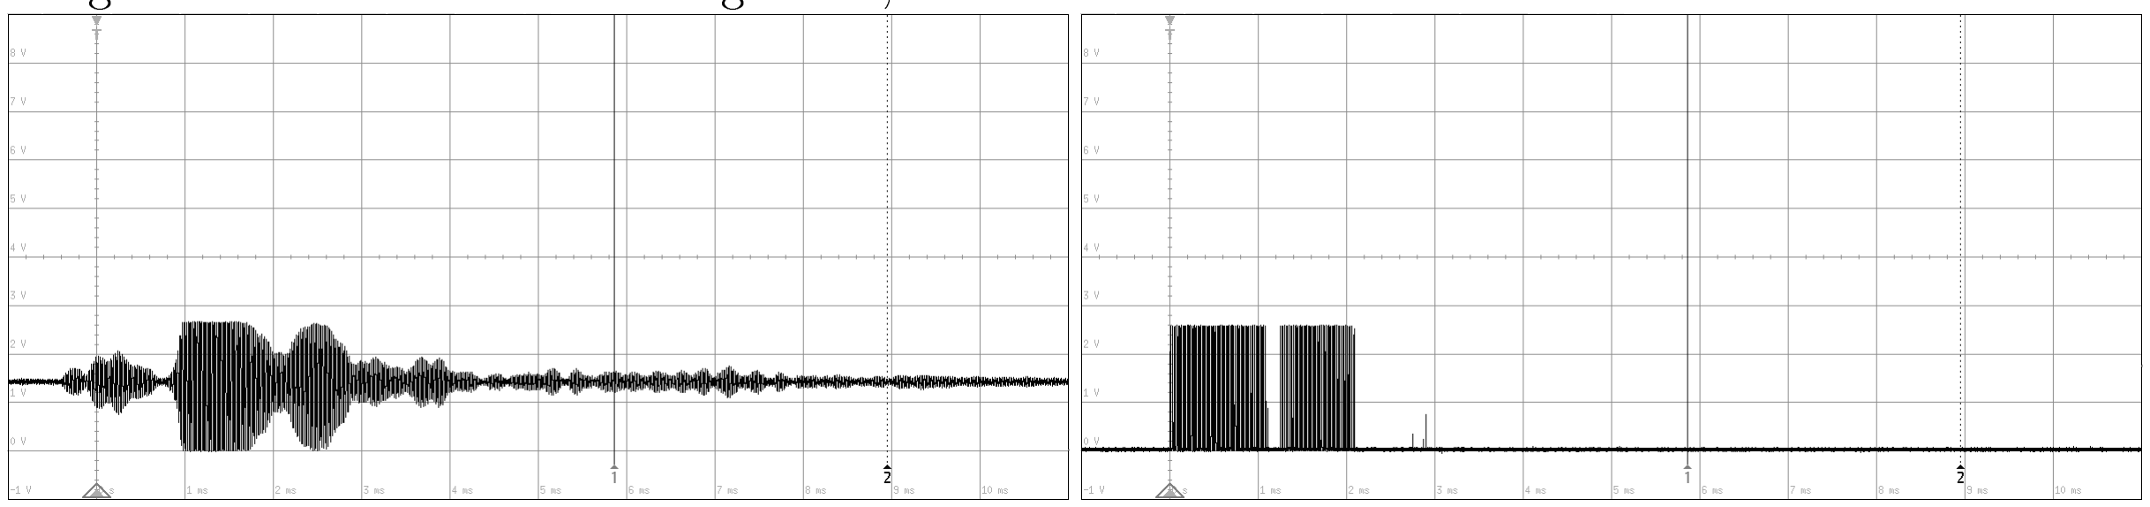
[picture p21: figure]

Abbildung 3.7: Signal nach Verstärkung2 | Abbildung 3.8: Signal nach Komparator

Nach dem das Signal den Komparator passiert hat, ergibt sich das Bild wie in Abbildung 3.8 zu sehen ist. Bei einem Vergleich mit dem Signal nach der Verstärkung 3.7 wird sichtbar, dass der Komparator nur Signale, die über seinem Schwellwert von 1,8 V liegen, durchschaltet. Die Aufteilung in zwei Signalblöcke in den Abbildungen kommt daher, dass der erste Block das Signal der Sender-Kapsel ist, das direkt beim Senden seitlich auf die Empfänger-Kapsel abgestrahlt wurde. Der zweite Block ist bereits das Echo, das vom 20 cm entfernten Hindernis zurückgeworfen wurde. Anhand dieser Ergebnisse kann festgehalten werden, dass die einfachere Version des Ultraschall-Entfernungsmessers durchaus simpel umzusetzen ist. Es fehlt nur noch ein Programm, das die Zeit zum eintreen des Echo-Signals in einen Abstand zum Hindernis konvertiert. Besagtes Programm wurde nicht für diese Prototypversion erstellt, da der Anspruch bestand, den Betrieb nicht nur über eine Platine, sondern auch noch über eine Ultraschallkapsel ablaufen zu lassen.

## 3.2 Prototyp 2

Nachdem mit der ersten Prototyp-Version bereits Versuche an der Elektronik durchgeführt wurden und auch erste Messungen mit einem beweglichen Hindernis auswertbare Ergebnisse brachten, wurde eine zweite Prototyp-Version entworfen. Bei der zweiten Prototyp-Version wurden der Senderund der Empfängerkreis auf einer Platine aufgebaut und es wurde nur noch eine Ultraschallkapsel für beide Anwendungen vorgesehen. Dadurch wurden für den fehlerfreien Betrieb drei und nicht zwei Schaltzustände der Halbbrücke benötigt. Deswegen wurde die Halbbrücke der ersten Prototyp-Version durch eine voll gesteuerte Halbbrücke ersetzt. Nicht nur sollte die Ultraschallkapsel mit HIGH-, oder LOW-Signal ansteuerbar sein, auch ein dritter potentialfreier Zustand war nötig, damit die Echo-Signale auch empfangen werden konnten. Um bei diesem Aufbau einen fehlerfreien Betrieb der verwendeten voll gesteuerten Halbbrücke sicherzustellen wurden durch den Mikrocontroller zwei getrennte PWM-Signale generiert die wie in Abbildung 3.9 zu sehen ist durch Lücken getrennt sind. Verzögerungen im Schaltbetrieb der Halbleiter konnten daher, keine Kurzschlüsse mehr verursachen. Auÿerdem konnten durch den neuen Platinenentwurf die ab der ersten Prototyp-Version vorgenommenen Änderungen direkt in den Schaltplan übernommen werden. Dadurch lieÿ sich die Störanfälligkeit durch empndliche Drahtbrücken deutlich reduzieren. Bedingt durch anfängliche Befürchtungen wurden für die MOSFETs der Halbbrücke anfangs jeweils ein weiteres MOSFET vorgeschaltet. Dieser Zusatz stellte sich als unnötig heraus, da durch eines der zusätzlichen Bauteile eines der PWM-Signale invertiert wurde. Somit wurde das überüssige MOSFET entfernt. Durch zwei Drahtbrücken konnte die komplette Schaltung nach Entlarvung eines weiteren Verdrahtungsfehlers, in Betrieb genommen werden.

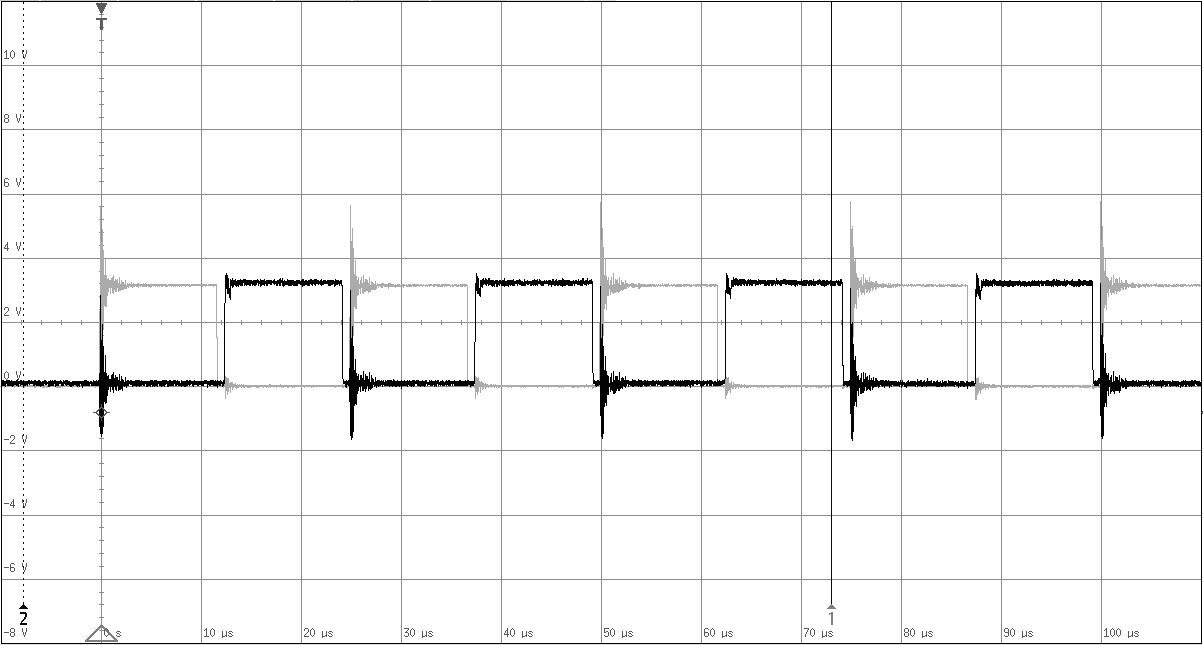
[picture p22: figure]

Abbildung 3.9: Verlauf der zwei generierten PWMs für den Betrieb der voll
gesteuerte Halbbrücke

Nachdem dieser Betrieb sichergestellt war, wurden Messungen am Verstärker (obere Linie), und am Komparator (untere Linie) vorgenommen. Dabei wurde die Verstärkung so eingestellt, dass unerwünschte Störungen nicht vom Komparator weitergegeben wurden. Die Spannung für den Sendebetrieb wurde für die Versuche zwischen 5V und 20V variiert, um betrachten zu können, wie sich das auf die Reichweite und Genauigkeit der Messungen auswirkt. Als Hindernis wurde bei allen Versuchen eine glatte Holzplatte der Maÿe 50x64cm verwendet und in einem Abstand von ein bis fünf Metern von der Ultraschallkapsel entfernt aufgestellt. In den Abbildungen 3.10 bis 3.13 sind die Ergebnisse einer Messreihe mit einer Spannung von 5 V für den Sendebetrieb dargestellt. Die Ansicht wurde so eingestellt, dass zwei Sendeimpulse zu sehen sind. Dadurch wird deutlicher, welches die Sende Impulse sind, und welches die von der Entfernung abhängigen Echos sind.

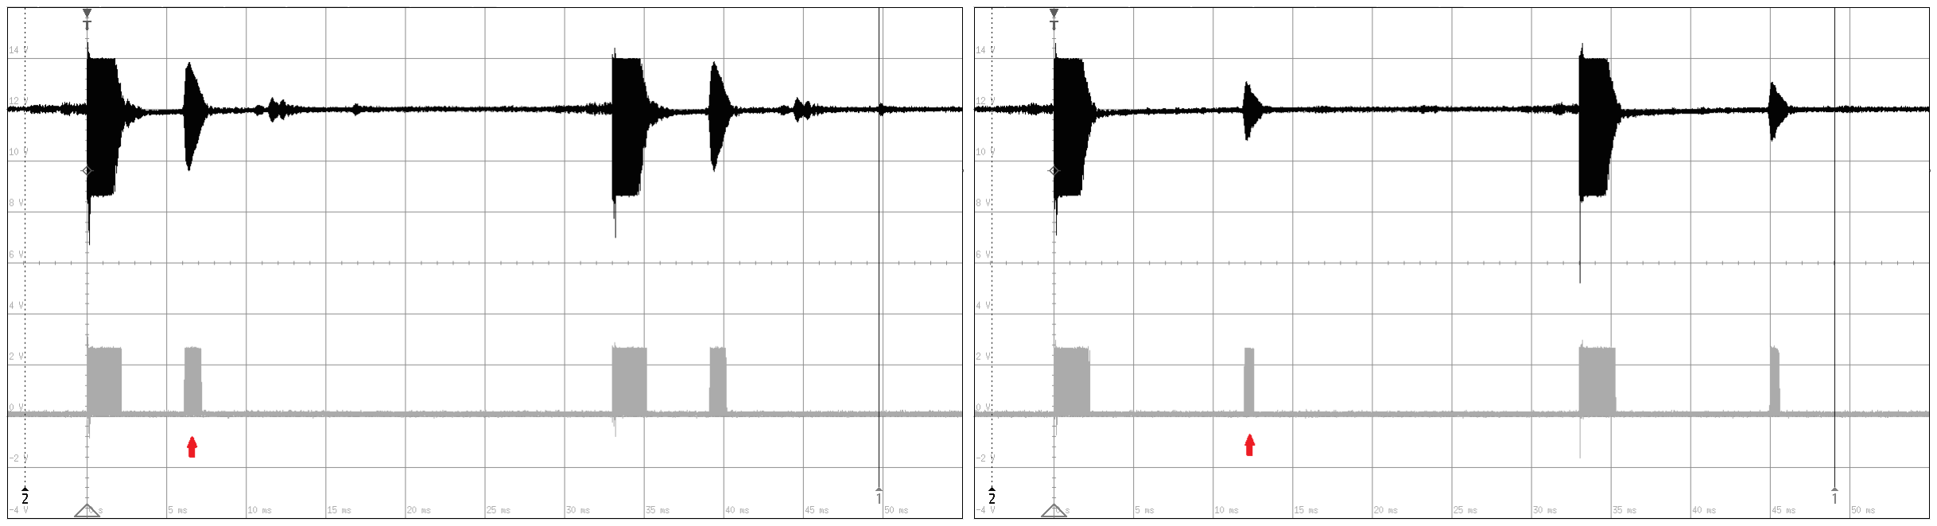
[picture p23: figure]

Abbildung 3.10: Signalverlauf bei 5 V auf 1 m Abstand

Abbildung 3.11: Signalverlauf bei 5 V auf 2 m Abstand

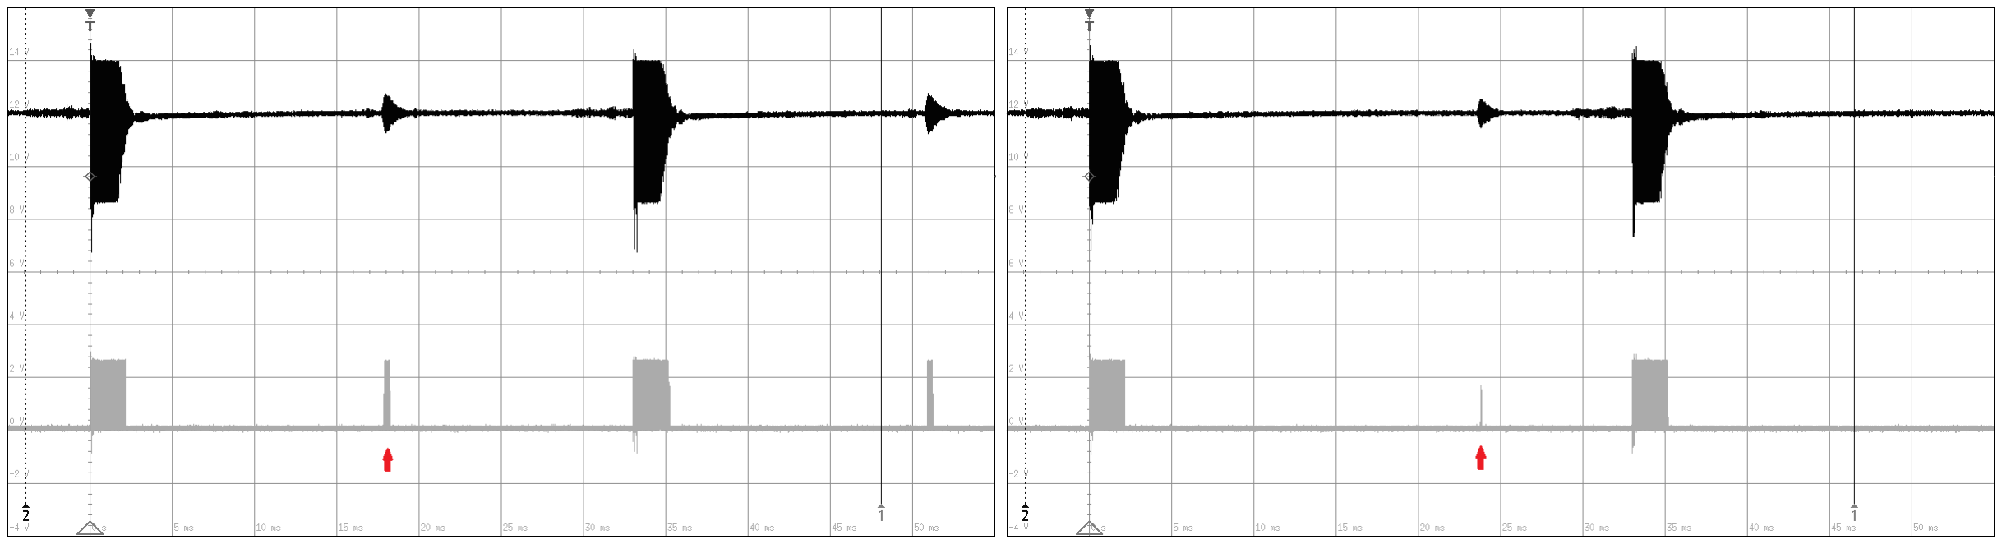
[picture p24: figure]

Abbildung 3.12: Signalverlauf bei 5 V auf 3 m Abstand

Abbildung 3.13: Signalverlauf bei 5 V auf 4 m Abstand

Bei den Abbildungen ist zu sehen, dass das Echo-Signal mit zunehmender Entfernung immer schwächer wird. Bei einer Entfernung von vier Metern (Abbildung 3.13) wird das Echo-Signal so schwach, dass die Signalstärke nach dem Komparator nicht mehr für eine eindeutige Auswertung über den Mikrocontroller ausreicht. Nachfolgend sind die Abbildungen einer Messreihe mit verschiedenen Spannungseinstellungen für den Sendebetrieb zu sehen. Anhand dieser Messreihe soll dargestellt werden, welchen Einuss die eingestellte Spannung im Sendebetrieb auf die Reichweite des Ultraschallsignals hat. Für die Darstellung wurden die Messungen bei 5 Meter Abstand ausgewählt.


Abbildung 3.14: Signalverlauf bei 5 V auf 5 m Abstand

Abbildung 3.15: Signalverlauf bei 10 V auf 5 m Abstand


Abbildung 3.16: Signalverlauf bei 15 V auf 5 m Abstand

Abbildung 3.17: Signalverlauf bei 20 V auf 5 m Abstand

Bei Vergleich der Abbildungen 3.14 und 3.15 mit den Abbildungen 3.16 und 3.17 ist zu sehen, dass bei einem Abstand von 5 Metern erst bei einer Sendespannung von über 10 V, auch am Komparator ein über den Mikrocontroller auswertbares Signal vorhanden ist.
In der nachfolgenden Tabelle 3.1 wurden die Zeitabstände vom ersten Impuls des gesendeten Signals, bis zum ersten Impuls des Echo-Signals aufgetragen. Anhand der Schallgeschwindigkeit die Entfernung, die der Schall zurückgelegt hat berechnet. Dazu wurde noch die Abweichung der berechneten Entfernung von der eingestellten Entfernung angegeben.

Tabelle 3.1: Entfernungsmessung mit Abweichung bei 20 V Sendespannung

Entfernung [m] | Zeit bis Anfang Echo [ms] | Errechnete Entfernung [m] | Abweichung [cm]
1 | 6,07 | 1,0416 | 4,16
1,5 | 8,97 | 1,5392 | 3,92
2 | 11,92 | 2,0454 | 4,54
2,5 | 14,8 | 2,5396 | 3,96
3 | 17,75 | 3,0459 | 4,59
3,5 | 20,65 | 3,5435 | 4,35
4 | 23,56 | 4,0428 | 4,28
4,5 | 26,49 | 4,5456 | 4,56
5 | 29,46 | 5,0553 | 5,53

Wie befürchtet sind bei der errechneten Entfernung Abweichungen im Bereich weniger Zentimeter aufgetreten. Bei Betrachtung der Abweichungen wird allerdings deutlich, dass die Werte bis auf einen, alle im Bereich von 4 cm bis 4,5 cm liegen. Ähnliche Abweichungen waren auch bei den anderen Messreihen zu beobachten. Somit lieÿe sich die Abweichung durch einen Korrekturwert auf ein Minimum reduzieren und würde einen Zentimeter nur noch selten überschreiten. Der erste Impuls des Echo-Signals als Referenz für die Entfernungsberechnung zu nutzen ist. Die anfänglichen Überlegungen, den letzten Impuls des Echo-Signals, oder einen Mittelwert aus allen empfangenen Impulsen zu verwenden beinhaltet ein höheres Fehlerpotential. Die Dauer des Echo-Signals kann durch niederfrequente Störgeräusche deutlich verlängert werden. Dies lieÿ sich bei einem der Tests beobachten, als im Hintergrund ein Lasercutter betrieben wurde. Dabei entstanden entgegen der Befürchtung keine Störsignale, stattdessen war die Signalintensität des Echo-Signals deutlich höher als bei Versuchen in einer stillen Umgebung.

## 3.3 Fazit aus den Ergebnissen für den Auftraggeber

Aus den Versuchen und Messungen lassen sich mehrere Aussagen treen.
Als erstes, eine Ultraschall-Entfernungsmessung ist mit wenigen Bauteilen, sowohl als Zwei-Kapsel-Variante, als auch als Ein-Kapsel-Variante durchführbar. Bei der Ein-Kapsel-Variante ist darauf zu achten, dass der Verstärker eine ausreichende Spannungsfestigkeit besitzt, um nicht durch das

Sendersignal gestört zu werden. Auch ist wichtig, dass bei der Erzeugung des PW-Modulierten Ausgangssignals die MOSFETs so angesteuert werden, dass den MOSFETs zwischen den Schaltsignalen genug Zeit gegeben wird, um die Schaltzustände zu erreichen. Vergleiche Abbildung 3.9. Dadurch lassen sich Kurzschlüsse an dieser Stelle vermeiden.
Eine Auswertung des Echo-Signals ist prinzipiell sowohl digital, als auch analog möglich. bei der digitalen Auswertung muss die Zeit erfasst werden, die zwischen dem Senden des PWM-Signals und dem Empfangen des Echo-Signals vergeht. Die errechnete Strecke ist zu halbieren, da die vergangene Zeit sowohl den Hin-, als auch den Rückweg beinhaltet. Bei der analogen Auswertung besteht zwar die Möglichkeit über einen Frequenzvergleich auch Signale mit kleinerer Echo-Amplitude zu erkennen und auszuwerten, allerdings beinhaltet dieses Vorgehen einen deutlich höheren Programmieraufwand.
Bei der Berechnung der Zeiten muss berücksichtigt werden, dass das eingehende Echo-Signal die Ultraschallkapsel langsam in Schwingungen versetzt. Die ersten eintreenden Schwingungen eines PWM-Signals erzeugen kleinere Spannungssignale als die darauf folgenden. Auÿerdem schwingt die Ultraschallkapsel auch nach Ende des eingehenden Signals noch etwas nach, was zur Folge hat, dass das analoge Abbild des gesendeten PWM-Signals leicht versetzt und etwas verlängert wirkt. All diese Faktoren müssen für eine genauere Berechnung der Strecke, die das Signal zurück gelegt hat, berücksichtigt werden. Die Tatsache, dass das empfangene Signal an der Ultraschallkapsel verändert wird, ist eine absolut exakte Messung nicht möglich. Eine Beschränkung des Fehlers auf einzelne Zentimeter ist realisierbar.
Mit den aktuellen, korregierten Schaltplänen ist der Aufbau eines Ultraschall-Entfernungsmessers durchführbar. Was noch aussteht, ist eine Festlegung auf denierte Werte für die Verstärkung und die Sendespannung, um die beiden Potentiometer durh Widerstände zu ersetzen. Denn schlieÿlich soll ein Produkt nist erst eingestellt werden, sondern nach einschalten funktionieren.

# 4 Reektion über den Projektablauf

Nach Erhalt der Aufgabenbeschreibung war das Bild, das man sich von den bevorstehenden Aufgaben machte, doch sehr anders, als die Abeiten später aussahen. So war mit der Programmierung, auf Grund des doch deutlich komplexeren Mikrocontrollers, ein enormer Lernaufwandt verbunden. Die Recherche der Hardwarebauteile und das Erstellen der Schaltpläne und Platinen hingegen verlief ähnlich den Erwartungen.
Eddy: Die Einarbeitung in die Tinkerforge verwendeten Programme, KiCad und GitHub, erforderten genausoviel Aufmerksamkeit wie die Programmierung trotz der Einarbeitungsphasen war stest konstant ein Lernerfolg zu verbuchen und konnten bis zum ende des Projektes uns neues Wissen sowie Fähigkeiten erwerben.

# 5 Anhänge


Abbildungen der Messreihen mit verschiedenen Spannungen bei Abständen von ein bis fünf Metern.

Abbildung 5.1: Signalverlauf bei 5V auf 1m Abstand

Abbildung 5.2: Signalverlauf bei 10V auf 1m Abstand

Abbildung 5.3: Signalverlauf bei 5V auf 2m Abstand

Abbildung 5.4: Signalverlauf bei 10V auf 2m Abstand

Abbildung 5.5: Signalverlauf bei 5V auf 3m Abstand

Abbildung 5.6: Signalverlauf bei 10V auf 3m Abstand

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

# Abbildungsverzeichnis

2.1 Blockschaltbild des Ultraschall-Entfernungsmessers | | 4
2.2 Schaltplan des beschalteten Hochsetzstellers | | 6
2.3 Schaltplan zweier Operationsverstärker mit einer vorgelagerten Filterung als Emp-
fängerschaltung | | 8
2.4 Quellcode der main.c des Distance US | | 9
2.5 Inhalt der Headerdatei a16pt.h | | 9
2.6 Ein Teilausschnitt aus der a16pt.c mit Kongurationen von Funktionen | 10
2.7 Ein Teilausschnitt von der a16pt.c mit einem Interrupt Request | 11
3.1 PWM-Burst auf 40 kHz Basis an der CPU | 12
3.2 PWM Ausgabe über einen HIGH-Side | 12
3.3 PWM Ausgabe über eine Halbbrucke | 13
3.4 Ausgabe der PWM an der Ultraschallkapsel | 13
3.5 Signal Empfang | 13
3.6 Signal nach Verstärkung | 13
3.7 Signal nach Verstärkung2 | 14
3.8 Signal nach Komparator | 14
3.9 Verlauf der zwei generierten PWMs für den Betrieb der voll gesteuerte Halbbrücke . 15
3.10 Signalverlauf bei 5 V auf 1 m Abstand | 16
3.11 Signalverlauf bei 5 V auf 2 m Abstand | 16
3.12 Signalverlauf bei 5 V auf 3 m Abstand | 16
3.13 Signalverlauf bei 5 V auf 4 m Abstand | 16
3.14 Signalverlauf bei 5 V auf 5 m Abstand | 16
3.15 Signalverlauf bei 10 V auf 5 m Abstand | 16
3.16 Signalverlauf bei 15 V auf 5 m Abstand | 17
3.17 Signalverlauf bei 20 V auf 5 m Abstand | 17
5.1 Signalverlauf bei 5V auf 1m Abstand | 20
5.2 Signalverlauf bei 10V auf 1m Abstand | 20
5.3 Signalverlauf bei 5V auf 2m Abstand | 20
5.4 Signalverlauf bei 10V auf 2m Abstand | 20
5.5 Signalverlauf bei 5V auf 3m Abstand | 20
5.6 Signalverlauf bei 10V auf 3m Abstand | 20
5.7 Signalverlauf bei 5V auf 4m Abstand | 21
5.8 Signalverlauf bei 10V auf 4m Abstand | 21
5.9 Signalverlauf bei 5V auf 5m Abstand | 21
5.10 Signalverlauf bei 10V auf 5m Abstand | 21

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

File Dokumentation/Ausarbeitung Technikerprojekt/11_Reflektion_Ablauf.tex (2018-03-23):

Bei Erhalt der Aufgabenstellung entstand bereits ein Bild der zu erledigenden Arbeiten. Dieses Bild wurde binnen kürzester Zeit deutlich umgestaltet. So war der Aufwand bei der Einarbeitung, gerade im Bereich der Programmierung deutlich höher als durch schulische Erfahrungen angenommen. Dank der tatkräftigen Unterstützung durch die betreuenden Mitarbeiter konnten größere Schwierigkeiten in diesem Bereich vermieden werden. Bezüglich der Hardwareentwicklung zeigte sich bei diesem Projekt das Problem, dass jeder Fehler im Platinenlayout ein längeres Nachspiel mit sich brachte. Erstens konnte der Fehler nach Bestellung der Platine nicht mehr korrigiert werden und die Platine musste mit Hilfe von Fädeldraht und Leiterbahnunterbrechungen angepasst werden. Zweitens betrug die Lieferzeit einer Platine immer mindestens eine halbe Woche. Dies bedeutet, dass auch wenn ein Fehler bekannt war, dieser erst nach Erhalt der Platine behoben werden konnte. Dadurch ging zusätzlich Zeit verloren, die bereits für Messungen hätte genutzt werden können. Durch die kontinuierliche Mitschrift von Informationen und Stichpunkten für die Dokumentation konnte in diesem Punkt einiges an Aufwand und Zeit eingespart werden, obwohl einzelne Teile der Dokumentation komplett überarbeitet werden mussten. Bedingt durch anfängliche, kleine Fehler in der Recherche wurden anfangs falsche Bauteile für die Platine ausgewählt. Aufgrund einer umsichtigen Arbeitsweise ließ sich die Zerstörung anderer Bauteile durch Fehler größtenteils vermeiden. Durch die Aufteilung der Gruppenmitglieder, zu beginn des Projekts, auf verschiedene Arbeitsbereiche, ließen sich auch im späteren Verlauf mehrere Aufgaben parallel abarbeiten. Durch diese Aufteilung ließen sich gleichzeitig Versuche an der Testplatine und an dem Programm zur Steuerung der Platine durchführen.\\
Daraus resultierend ließ sich das Ziel des Projekts trotz Verzögerungen problemlos erreichen.

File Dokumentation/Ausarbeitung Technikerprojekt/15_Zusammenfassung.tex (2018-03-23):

\section{Zusammenfassung}
Das Ziel des Technikerprojekts war das Entwickeln und testen eines Ultraschall-Entfernungsmessers als Vorbereitung eines Produktentwurfes. Dabei gab es zwei Möglichkeiten den Ultraschall- Entfernungsmesser zu realisieren. Begonnen wurde mit einer Variante mit getrenntem Sende- und Empfangsbetrieb, auf zwei Leiterplatten aufgebaut. Bei den Tests dieser wurden Fehler behoben und Verbesserungen integriert. Danach entstand eine neue Variante mit kombiniertem Betrieb, auf einer Platine aufgebaut. Diese zweite Prototyp-Version besaß nur noch eine Ultraschallkapsel für den Sende- und Empfangsbetrieb. Mit dieser zweiten Prototyp-Version wurden zahlreiche Messungen durchgeführt um aufzuzeigen, dass die Ergebnisse mit denen einer zwei-Kapsel Variante vergleichbar sind.
Aus den Messungen und Tests ist klar ersichtlich, dass ein Ultraschall-Entfernungsmesser mit nur einer Ultraschallkapsel realisierbar ist. Die Messgenauigkeiten liegen im Bereich von wenigen Zentimetern. Diese lassen sich durch Anpassungen in der Software noch weiter verbessern. Das Ergebnis ist ein funktionaler Prototyp.

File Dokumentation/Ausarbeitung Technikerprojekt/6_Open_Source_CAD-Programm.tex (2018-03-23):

Das Open Source ECAD-Programm KiCAD ist eine Anwendung zum Erstellen von Schaltplänen und elektronischen Leiterplatten. Mit einem solchen Programm lassen sich die erstellten Schaltpläne vor einer Leiterplattenerstellung auf Verdrahtungsfehler prüfen, um spätere Probleme zu vermeiden.

\subsection{Schaltplan}
Beim Schaltplanentwurf gilt es auf gewisse Regeln zu achten, zu dem ist auf die Übersichtlichkeit des Schaltplans zu achten.
So sollten beispielsweise Filterkondensatoren an der Spannungsversorgung des Mikrocontrollers eingeplant werden, um die Versorgungsspannung zu stabilisieren. Auch ist schon bei dem Entwurf des Schaltplans an das spätere Platinenlayout zu denken. So muss bei der Platzierung der Bauteile darauf geachtet werden, dass die Signalintegrität gewährleistet ist, und es zu keiner Potential Verschiebung kommt.\\
Im Schaltplan wurden die Baugruppen Empfänger, Sender, Hochsetzsteller und die Anschlüsse vom Mikrocontroller getrennt und so positioniert, dass die beste Übersicht dargestellt wird.\\
Um die einzelnen Bestandteile separat testen zu können, wurden dem Design 0\,Ohm Widerstände, an den Verbindungspunkten, hinzugefügt. Außerdem ist es dadurch möglich, eine Zerstörung einzelner Baugruppen durch einen Verdrahtungsfehler bei der Erstinitialisierung zu vermeiden.\\   
\newpage
\subsection{Platinenlayout}
Beim Entwerfen eines Platinenlayouts gibt es viele Alternativlösungen ein Ergebnis zu erzielen. Somit können alle Bauteile so angeordnet werden, dass alle parallelen Bauteile nebeneinander aufgereiht werden und die in Reihe dazu liegenden Bauteile darunter geordnet sind. So sähe die Platine zwar ähnlich eines Kontaktplanes aus, jedoch ist diese Variante aus Sicht der EMV nicht sonderlich empfehlenswert.\\
Eine andere Gestaltungsmöglichkeit wäre, die Bauteile schon im Schaltbild in Gruppen zusammenzulegen und den Schaltplan auf der Platine exakt nachzubilden. Auch bei dieser Variante ergeben sich gelegentlich Probleme, was die Führung der Leitungen und vor allem den Verlauf der Ströme angeht.\\
Es sollte ein Augenmerk auf den stromführenden Leitungen liegen. Je höher der Strom ist, desto dicker und kürzer ist die Leitung auszulegen, um weniger EMV-Störungen zu erzeugen. Auch sollte die Rückführung (GND) günstigerweise als eigene Leiterschicht ausgeführt werden, um einen großen Leiterquerschnitt zu gewährleisten. So kann bei der Rückführung der Ströme auch das Risiko vermieden werden, durch Bildung von größeren Schleifen, Antennen zu erzeugen. Die GND-Schicht sollte so wenig wie möglich unterbrochen werden, vor allem sind Unterbrechungen quer zur Stromflussrichtung zu vermeiden. Zusätzlich ist zu beachten, dass Kondensatoren, die der Verringerung von störenden Spannungsschwankungen dienen, nahe schaltenden Bauteilen angebracht werden. Die optimale Platzierung ist direkt am VDD oder VCC Pin des ICs, sodass die Leiterbahn vor dem IC mit einem höheren Querschnitt am Kondensator liegt und dann mit leicht verringertem Querschnitt an dem IC angeschlossen ist.

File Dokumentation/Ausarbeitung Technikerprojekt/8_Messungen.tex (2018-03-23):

Für die Messungen wurden im Laufe des Projekts zwei Versionen an Prototyp-Platinen entworfen. Im Verlauf der Versuche wurden Veränderungen an den Platinen vorgenommen, um den Betrieb dieser zu verbessern. 
\section{Prototyp 1}
\begin{center}
\begin{minipage}{0.75\textwidth}
\includegraphics[width=1\textwidth%, draft
]{Abbildungen/BilderPrototypen/Prototyp1.JPG}
\captionof{figure}{Aufgebaute und bearbeitete Platine des ersten Prototypen}
\label{fig:Prototyp1}
\end{minipage}
\end{center}
Bei dem ersten Prototyp wurden die Sendereinheit und die Empfängereinheit auf getrennten Platinen aufgebaut. So bestand die Möglichkeit, den Senderkreis und den Empfängerkreis unabhängig voneinander zu untersuchen, ohne dass sich elektrische Signale der beiden Schaltkreise überlagern konnten. Anfangs wurde für den Senderkreis eine komplette H-Brücke als Schalter verwendet. Allerdings war der Aufbau nicht funktional, da ein Beschaltungsfehler vorhanden war. Dadurch, dass das IC A5950 eine H-Brücke mit integrierter Kontroll-Logik und eigener Spannungspumpe ist, wurde anhand der Schaltweise der Baugruppe festgestellt, dass diese H-Brücke nicht für die Schaltung einsetzbar ist. Denn durch die nicht veränderbare Ansteuerung der beiden Brückenzweige entstand ein Kurzschluss auf der Platine. Um nicht sofort eine neue Platine in Auftrag geben zu müssen, was einiges an Zeit gekostet hätte, wurde das IC ausgelötet. Danach wurde ein MOSFET als HIGH-Side an der Stelle eingesetzt. Vergleiche Abbildung \ref{fig:hiside} Die notwendige Umverdratung wurde mit Fädeldrat durchgeführt. Dadurch ließen sich erste Versuche realisieren, nichtsdestotrotz entsprach das Ergebnis noch nicht den Anforderungen. Deswegen wurde die Beschaltung an dieser Stelle auf eine Halbbrücke erweitert. Damit war die Funktion des Senderkreises für die ersten Versuche und Messungen gegeben.\\
Der Empfängerkreis war von Beginn an funktional, konnte aber erst mit Inbetriebnahme des Senderkreises richtig getestet werden. Am Empfängerkreis wurden zu Testzwecken Änderungen an der Filterung, vor dem Verstärker, vorgenommen. Die Filterung wurde in ihrer Dimensionierung verändert, um herauszufinden, wie sich die Qualität des Echo-Signals verbessern lässt.\\

\begin{minipage}{1\textwidth}
\begin{center}
\includegraphics[width=0.5\textwidth%, draft
]{Abbildungen/h-side.png}
\captionof{figure}{Aufbau des Senders mit einem HIGH-Side}
\label{fig:hiside}
\end{center}
\end{minipage}

\subsection{Senderkreis}
Zuerst wurden Signale direkt an dem Mikrocontroller gemessen, um sicher zu stellen, dass die Einstellungen im Programm die gewünschten Ausgaben zur Folge haben, und keine Gefährdung der Bauteile entsteht.
Um das Signal für die Entfernungsmessung zu generieren wurde der Prozessor so programmiert, dass zehn Impulse mit einer Frequenz von 40\,kHz ausgegeben werden. Danach erfolgt eine Pause, um das zurückkehrende Signal abzuwarten und auszuwerten.\\
\begin{minipage}{0.46\textwidth}
\includegraphics[width=1\textwidth%, draft
]{Abbildungen/MessungenP1/PWM-von-der-cpu.png}
\captionof{figure}{PWM-Burst auf 40\,kHz Basis an der CPU}
\label{fig:pwm-burst}
\end{minipage}\qquad
\begin{minipage}{0.46\textwidth}
\includegraphics[width=1\textwidth%, draft
]{Abbildungen/MessungenP1/PWM-ausgabe-mit-Hi-Side.png}
\captionof{figure}{PWM Ausgabe über einen HIGH-Side}
\label{fig:HiSide}
\end{minipage}\\
In der Abbildung \ref{fig:pwm-burst} ist zu sehen, dass der gewünschte Burst aus zehn Impulsen mit einer Periodendauer von jeweils 25\,\textmu s vom Mikrocontroller generiert wurde. Diese Messung wurde auch vorgenommen, um zu überprüfen, wie das Signal durch die eingesetzten Bauteile verändert wird.\\
Die Abbildung \ref{fig:HiSide} zeigt, wie das Ausgangssignal nach einer HIGH-Side aussah. So wurde zwar im Takt des PWM-Signals geschaltet, allerdings fehlte es an einem Gegenpol, um das Potential in den Schaltpausen wieder auf Null zu ziehen. Somit blieb die Spannung während des Schaltens immer auf einem erhöhten Pegel und sank erst nach Ende des PWM-Signals allmählich ab. Dadurch konnte keine vernünftige Ausgabe an der Ultraschallkapsel erzeugt werden, denn ohne deutliche Potentialunterschiede konnte diese auch nicht in Schwingungen versetzt werden. Der ausgegebene Schalldruck würde nur für kurze Entfernungsmessungen reichen. Das zurückkommende Signal wäre von der abklingenden Spannung des HIGH-Side überlagert worden. Somit war dieser Aufbau nicht umsetzbar.\\
Um die Spannung nicht nur auf einen HIGH-Pegel, sondern auch auf einen LOW-Pegel schalten zu können wurde danach auf eine Halbbrücke gewechselt. Mit dieser ließ sich der Ausgang, über zwei durch das PWM-Signal gesteuerte MOSFETs, sauber auf HIGH- oder LOW-Pegel schalten. 
Mit der verwendeten Halbbrücke ergab sich die Abbildung \ref{fig:Halfbridge}\\
\begin{minipage}{0.46\textwidth}
\includegraphics[width=1\textwidth%, draft
]{Abbildungen/MessungenP1/PWM-Nach-der-Halbbrucke.png}
\captionof{figure}{PWM Ausgabe über eine Halbbrücke}
\label{fig:Halfbridge}
\end{minipage}\qquad
\begin{minipage}{0.46\textwidth}
\includegraphics[width=1\textwidth%, draft
]{Abbildungen/MessungenP1/PWM-Nach-der-Halbbrucke-mit-LS.png}
\captionof{figure}{Ausgabe der PWM an der Ultraschallkapsel}
\label{fig:Senderausgabe}
\end{minipage}\\
Es zeigt sich, dass das Signal nach der Erweiterung auf eine Halbbrücke wieder wie das von dem Mikrocontroller ausgegebene PWM-Signal aussah. Vergleiche Abbildung \ref{fig:pwm-burst}. Die Amplitude fiel wie geplant höher aus. Somit konnte die Höhe der Amplitude über die Spannungspumpe variiert werden um die Stärke des ausgegebenen Signals zu verändern, ohne den Mikrocontroller durch die höhere Spannung zu beschädigen. Wie in der Abbildung \ref{fig:Senderausgabe} zu entnehmen ist, entstanden durch die angeschlossene Ultraschallkapsel höhere Spannungsimpulse in den Schaltmomenten. Diese Spannungsspitzen, die durch die Ultraschallkapsel entstanden, wurden in den Expirementen vernachlässigt, da keine Gefährdung anderer Bauteile entstand. Das dadurch generierte Ausgangssignal entsprach den Anforderungen und musste für die Versuche nicht weiter bearbeitet werden.
\subsection{Empfängerkreis}
Die Platinen des Sender- und Empfängerkreises wurden gemeinsam auf einer Halterung montiert, damit die Ultraschallkapseln zum senden und empfangen der Signale nebeneinander befestigt werden konnten. Ziel war es, durch verschieben eines Hindernisses die Signaländerungen an den Platinen beobachten zu können, ohne die gesamten Messaufbauten bewegen zu müssen. Bei der Aufnahme der Messungen wurde der Empfängerkreis Schritt für Schritt überprüft, um zu erfahren, wie sich das empfangene Signal durch die einzelnen Bauteile verändert.\\
\begin{minipage}{0.46\textwidth}
\includegraphics[width=1\textwidth%, draft
]{Abbildungen/MessungenP1/Signal-Empfang.png}
\captionof{figure}{Signal Empfang}
\label{fig:Empfang am LS}
\end{minipage}\qquad
\begin{minipage}{0.46\textwidth}
\includegraphics[width=1\textwidth%, draft
]{Abbildungen/MessungenP1/Signal-nach-Verstarkung.png}
\captionof{figure}{Signal nach Verstärkung}
\label{fig:Verstaerkung}
\end{minipage}\\
Die Abbildung \ref{fig:Empfang am LS} zeigt das Signal, das direkt am Empfänger zu messen war. Hier waren verschiedene vorerst nicht zuordenbare Signale zu sehen. Allein aus diesem Bild ließ sich daher keine Aussage zu den einzelnen Signalen machen. Fest stand nur, dass ebenfalls Signale die nicht der gewünschten Frequenz entsprachen, vom Empfänger aufgenommen wurden. Dieses Problem galt es natürlich zu beheben, um unerwünschte Störungen zu vermeiden.
Die Abbildungen \ref{fig:Verstaerkung} und \ref{fig:Verstaerkung2} zeigen den Verlauf des Signals nach der Filterung und Verstärkung in zwei verschiedenen Zeitauflösungen. Dabei entspricht \ref{fig:Verstaerkung} den ersten drei Messintervallen von \ref{fig:Verstaerkung2} und dient um darzustellen, dass die Verstärkung eine maximale Aussteuerung von 3,3\,V nicht überschreitet.\\
\begin{minipage}{0.46\textwidth}
\includegraphics[width=1\textwidth%, draft
]{Abbildungen/MessungenP1/Signal-nach-Verstarkung2.png}
\captionof{figure}{Signal nach Verstärkung 2}
\label{fig:Verstaerkung2}
\end{minipage}\qquad
\begin{minipage}{0.46\textwidth}
\includegraphics[width=1\textwidth%, draft
]{Abbildungen/MessungenP1/Signal-nach-Komparator.png}
\captionof{figure}{Signal nach Komparator}
\label{fig:Komparator}
\end{minipage}\\
Nach dem das Signal den Komparator passiert hatte, ergab sich das Bild wie in Abbildung \ref{fig:Komparator} zu sehen ist. Bei einem Vergleich mit dem Signal nach der Verstärkung \ref{fig:Verstaerkung2} wurde sichtbar, dass der Komparator nur Signale, die über seinem Schwellwert von 1,8\,V liegen, durchschaltet. Die Aufteilung in zwei Signalblöcke in den Abbildungen kam daher, dass der erste Block das Signal der Sender-Kapsel ist, das direkt beim Senden seitlich auf die Empfänger-Kapsel abgestrahlt wurde. Der zweite Block ist bereits das Echo, das vom 20\,cm entfernten Hindernis zurückgeworfen wurde.\\
Auch wurden Vergleichsmessungen mit Ultraschallkapseln verschiedener Hersteller durchgeführt. Für die nachfolgenden Abbildungen wurden  Ultraschallkapseln des Herstellers MURATA verwendet. Für Abbildung \ref{fig:MURATAs1,5m} wurden sowohl für den Sendebetrieb, als auch für den Empfängerbetrieb, als Sender deklarierte Ultraschallkapseln verwendet. Für die Abbildung \ref{fig:MURATAsr1,5m} wurden die Kapseln entsprechend der Beschriftung verwendet.\\
\begin{minipage}{0.46\textwidth}
\includegraphics[width=1\textwidth%, draft
]{Abbildungen/MessungenP1/MURATAs1,5m.png}
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

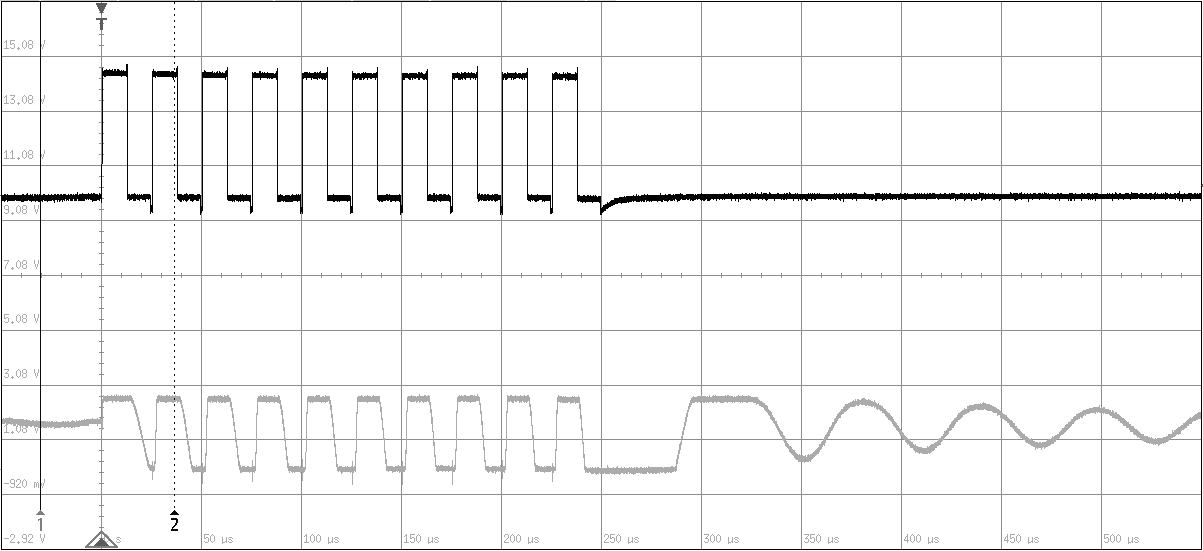
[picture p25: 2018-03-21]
Dokumentation/Ausarbeitung Technikerprojekt/Abbildungen/MessungenP1/Nachschwingen am Verstarker ohne LS.PNG

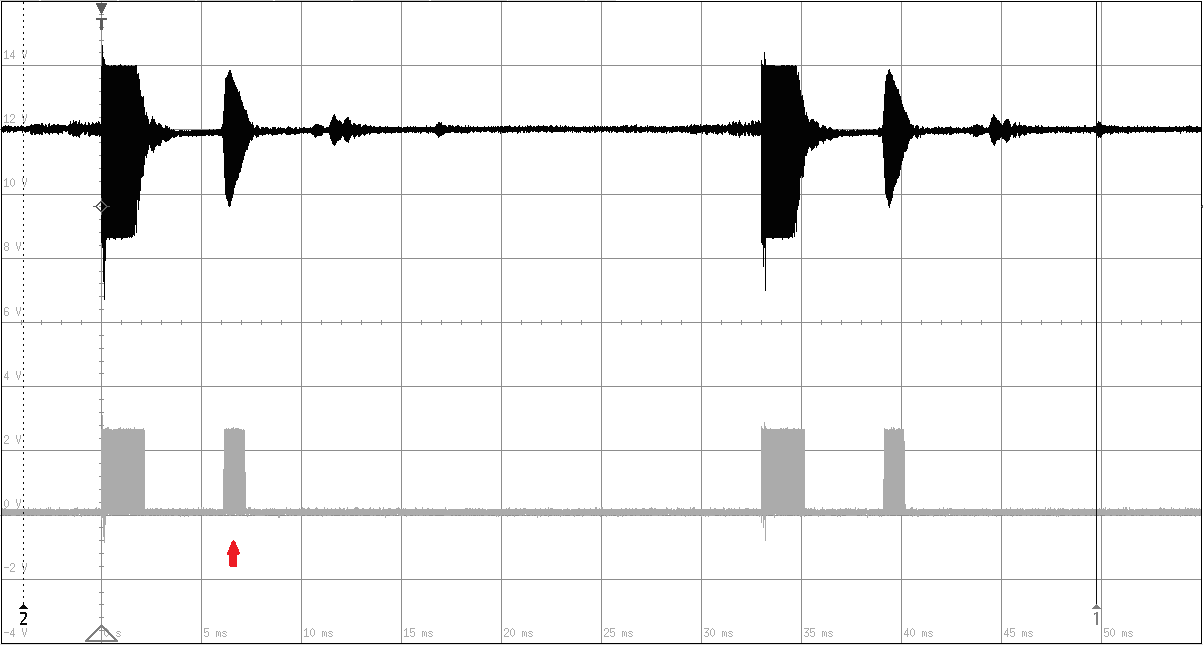
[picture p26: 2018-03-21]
Dokumentation/Ausarbeitung Technikerprojekt/Abbildungen/MessungenP2/5V/1mb.png

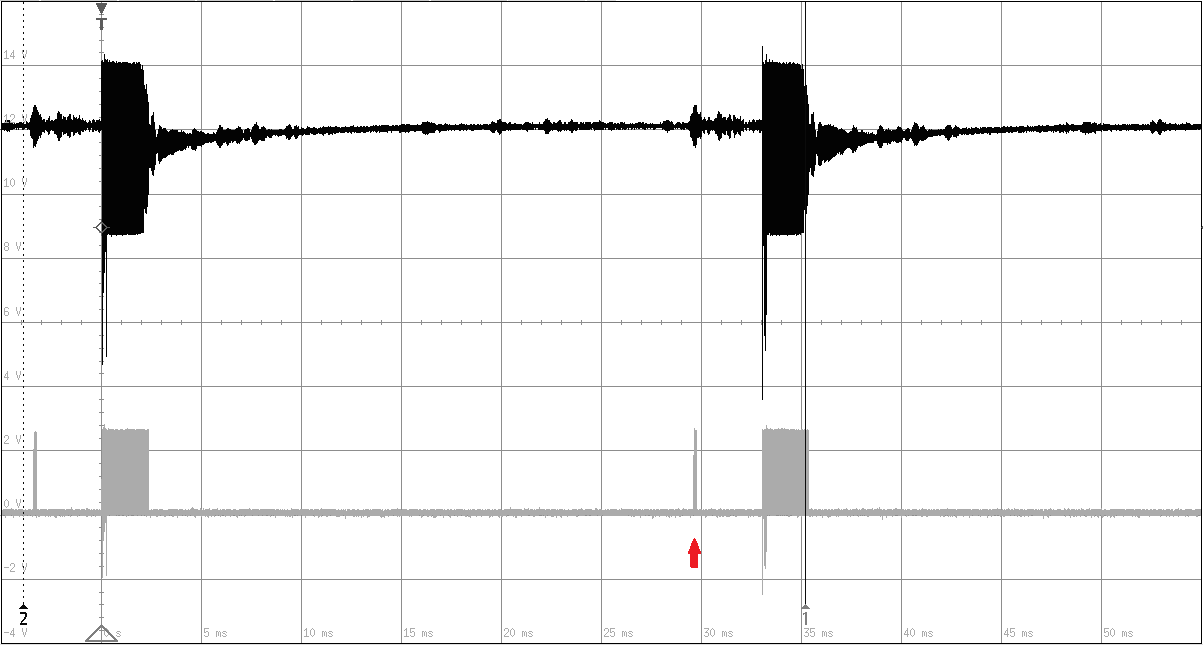
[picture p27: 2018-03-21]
Dokumentation/Ausarbeitung Technikerprojekt/Abbildungen/MessungenP2/15V/5mb.png

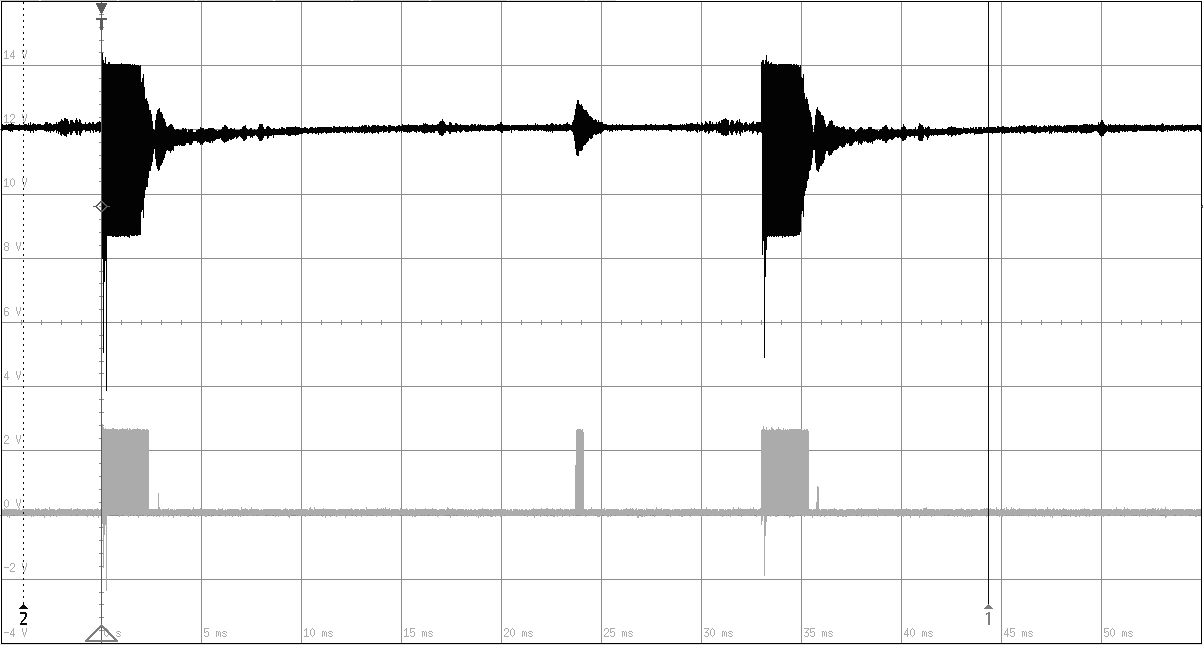
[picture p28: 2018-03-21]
Dokumentation/Ausarbeitung Technikerprojekt/Abbildungen/MessungenP2/10V/4m.PNG

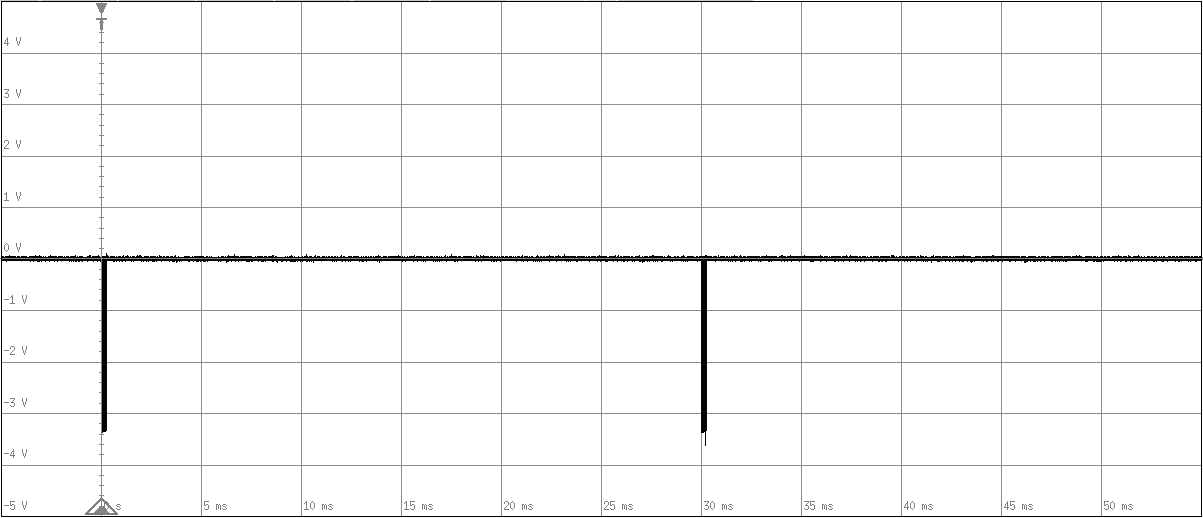
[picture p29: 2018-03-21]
Dokumentation/Ausarbeitung Technikerprojekt/Abbildungen/MessungenP1/Pulsintervall.PNG

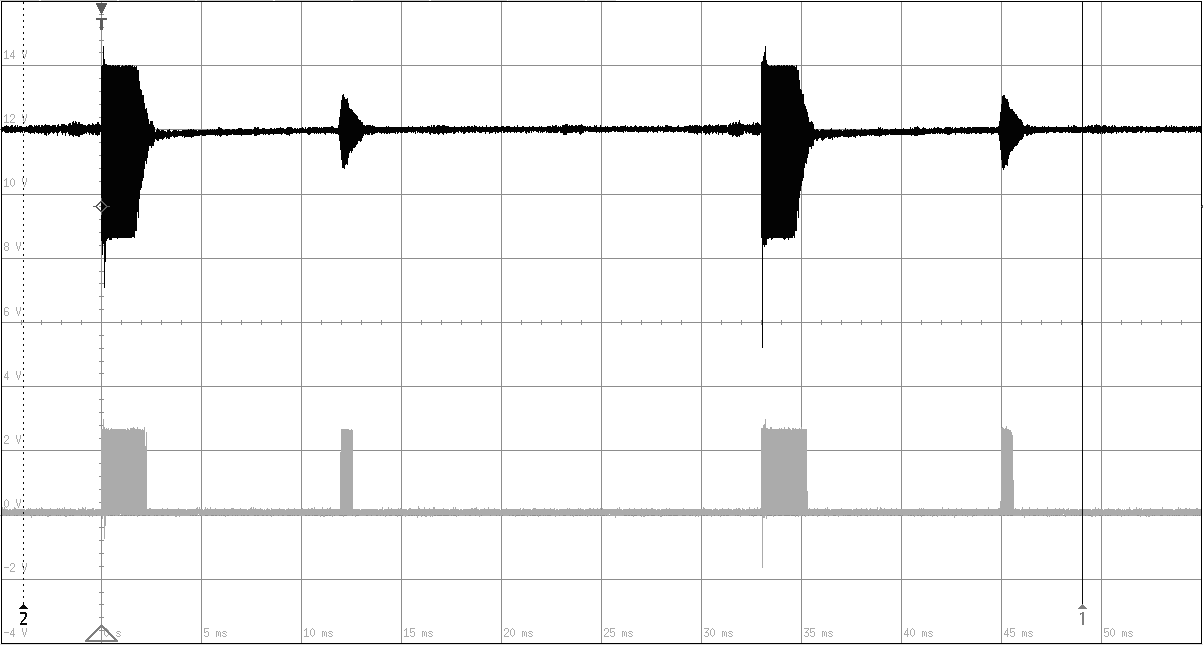
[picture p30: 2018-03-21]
Dokumentation/Ausarbeitung Technikerprojekt/Abbildungen/MessungenP2/5V/2m.PNG

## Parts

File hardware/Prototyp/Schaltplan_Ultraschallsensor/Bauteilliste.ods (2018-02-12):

Id | Designator | Package | Quantity | Designation | Digi-Key
1 | C1,C3,C4,C11,C16 | C0603F | 5 | 100nF
2 | C2 | C0603F | 1 | 220nF
3 | C9 | C0603F | 1 | 270pF
4 | C10 | C0603F | 1 | 4.7nF
5 | C12 | C0603F | 1 | 40pF
6 | C13,C14 | C0603F | 2 | 10pF
7 | C15 | C0402F | 1 | 220pF
8 | D3,D5 | D0603E | 2 | Gelb
9 | D4 | D0603E | 1 | Gleb
10 | IC1 | 16-leadTSSOP_0,137,4,4mmBreite | 1 | A5950 | 620-1862-2-ND 16-Lead TSSOP (LP)
11 | L1,L3 | C0603F | 2 | FB
12 | L2 | NR3030 | 1 | 10uH
13 | LS1 | Ultraschallsensor | 1 | Ultraschall Sender/Empränger | https://www.tme.eu/de/details/sens-c4016l8a40/ultraschallsensoren/sencera/c4016l8a402/ | https://www.voelkner.de/products/40909/Ultraschall-Sensor-1-Set-A-16PT10-A-16PR10-Frequenz-max.-40kHz-x-H-15mm-x-10mm.html | http://www.ultrasonic-distancesensor.com/quality-9455139-dual-use-ultrasonic-distance-transducer
14 | P1 | CON-SENSOR2 | 1 | CON-SENSOR2
15 | P2 | pin_array_5x1 | 1 | CONN_01X05
16 | R2 | R0603F | 1 | 13.3k
17 | R3 | R0603F | 1 | 1M
18 | R4,R11,R12,R13 | R0603F | 4 | 20k
19 | R5,R7,R10 | R0603F | 3 | 100k
20 | R6 | R0603F | 1 | 10 OHM
21 | R8 | ST4ETA | 1 | 50k | ST4ETA503CT-ND
22 | R9 | R0603F | 1 | 120k
23 | RP1 | 0603X4 | 1 | 10k
24 | RP2 | 0603X4 | 1 | 1k
25 | RP3 | 4X0402 | 1 | 82 OHM
26 | RV1 | ST4ETA | 1 | 200k | ST4ETA204TR-ND
27 | U1 | QFN48-EP2 | 1 | XMC1XXX48
28 | U3 | SOT23-5 | 1 | LMR62014X
29 | X1 | CRYSTAL_3225 | 1 | CRYSTAL_3225
30 | D1 | SOD-123 | 1 | B0520LW
31 | C7,C6,C5,C8 | C0805 | 4 | 4.7uF
32 | D2 | SOD-123 | 1 | ZENER
33 | U2 | TSSOP8 | 1 | TLC272 | 296-7354-2-ND 8-TSSOP (0,173", 4,40 mm Breite)
34 | P3 | DEBUG_PAD | 1 | CONN_01X01
35 | P4 | SolderJumper | 1 | CONN_01X02
36 | R17,R18 | R0603F | 2 | 0
37 | U5,U6 | DRILL_NP | 2 | DRILL

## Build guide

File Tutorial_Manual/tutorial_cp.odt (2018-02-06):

Tutorial zum Kompilieren

0. git pull ausführen

1. xmc.lib Downloaden Link: https://www.infineon.com/cms/de/product/microcontroller/32-bit-industrial-microcontroller-based-on-arm-cortex-m/

2. Datei Entpacken und nach tf/bricklib2 kopieren

3. Datei Umbenennen in xmclib

4. bricklib2 Verlinken mit (ln -s ../../../bricklib2/ ) nach:

a. brickletboot_xmc/software/src

b. bootstrupper_xmc/software/src

c. distance-us-v2-bricklet/software/src

5. Nach tf/distance-us-v2-bricklet/software gehen und

./generate_makefile eingeben.

6. Nach tf/distance-us-v2-bricklet/software/build gehen und

make eingeben.

7. Install gtkterm:

a. gtkterm -version eingeben //Prüft ob ein PROGRAMMVORHANDEN IST SOWIE DEREN Software Stand

b. sudo apt install … kopieren und ausführen

8. Install Brick Viewer

a.wget http://download.tinkerforge.com/tools/brickv/linux/brickv_linux_latest.deb

b.sudo apt-get install python python-qt4 python-qt4-gl python-opengl python-serial

c.sudo dpkg -i brickv_linux_latest.deb

9. Install Brick Daemon

a.wget http://download.tinkerforge.com/tools/brickd/linux/brickd_linux_latest_amd64.deb

b.sudo dpkg -i brickd_linux_latest_amd64.deb

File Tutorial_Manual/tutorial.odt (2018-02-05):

Vokabeln

repository | Ordner/Verzeichnis
Index | Bindung Zwischen schritt
commit | Zusage um vom Index zum Head zu wechseln
Head | Ist der Hauptverzeichnis

Befehle

Cd | Wechsel des Arbeitsverzeichnisses
cd .. | Vom Arbeitesverzeichniss Ein Schritt zurück
git pull | Verzeichnis aktualisieren
git add | zum Index hinzufügen
git commit -m "commit-Nachricht" | bestätigst deine Änderungen
git push | Änderung hochladen
git rm -r Dateiname | Datei aus dem Repositorium entfernen
rm -rf dateiname/ | Lösche den Ordner (Repositorium)
git clone /pfad/zum/repositorygit clone benutzername@host:/pfad/zum/repository | Hauptverzeichnis Klonen
git diff Dateiname | Datei Ändern
git add . | Änderung Hochladen
git checkout | Branch auf dem selben Stand wie die 'origin/master'.

Datei Hochladen

Reihenfolge:

1. In der Konsole das Verzeichnis ansteuern von (github) den man bearbeiten möchte

z.B.

„ privat@privat:~$ cd tf/distance-us-v2-bricklet/

privat@privat:~/tf/distance-us-v2-bricklet$ „

2. Den aktuellen stand Herunterlade mit dem Befehl „git pull“

z.B

„omar@omar-P6640:~/tf/distance-us-v2-bricklet$ git pull“

3. Datei Zum Index hinzufügen mit dem Befehl „git add dateiname“

z.B

omar@omar-P6640:~/tf/distance-us-v2-bricklet$ git add Tutorial.odt

4.Bestätigst du deine Änderungen Mit dem Befehl git commit-m" "

z.B

omar@omar-P6640:~/tf/distance-us-v2-bricklet$ git commit -m " "

5.Mit „git push“ die Datei oder die Änderung Hochladen

z.B

omar@omar-P6640:~/tf/distance-us-v2-bricklet$ git push

Datei Löschen

Reihenfolge:

1. Ordner muss auf den aktuellen Stand sein!!!

2. Datei aus dem Repositorium entfernen

z.B

omar@omar-P6640:~/tf/distance-us-v2-bricklet$ git rm -r Schaltplan_Ultraschallsensor

3. Bestätigst du deine Änderungen Mit dem Befehl git commit-m"Lösche Dateiname"

z.B

omar@omar-P6640:~/tf/distance-us-v2-bricklet$ git commit -m "Lösche Schaltplan_Ultraschallsensor"

4. Mit „git push“ die Datei oder die Änderung Hochladen

z.B

omar@omar-P6640:~/tf/distance-us-v2-bricklet$ git push

Hauptverzeichnis Klonen

Reihenfolge:

1. Lösche Ordner (nur wenn der Ordner bereits existiert)

z.B

omar@omar-P6640:~/tf$ rm -rf distance-us-v2-bricklet/

2. Hauptverzeichnis Klonen

z.B

omar@omar-P6640:~/tf$ git clone git@github.com:Tinkerforge/distance-us-v2-bricklet.git

3.en aktuellen stand Herunterlade mit dem Befehl „git pull“

z.B

„omar@omar-P6640:~/tf/distance-us-v2-bricklet$ git pull“

Änderung Hochladen

Reihenfolge:

1. Änderung angeben

z.B

omar@omar-P6640:~/tf/distance-us-v2-bricklet$ git diff omar.odt

2. Änderung Hochladen

z.B

omar@omar-P6640:~/tf/distance-us-v2-bricklet$ git add .

3. Bestätigst du deine Änderungen

z.B

omar@omar-P6640:~/tf/distance-us-v2-bricklet$ git commit -m "Dateiname Geändert "

4. Die Änderung Hochladen

z.B

omar@omar-P6640:~/tf/distance-us-v2-bricklet$ git push

info bei Ordner änderungen: Aus der Anzeige Rausspringen Taste „q“ Drück

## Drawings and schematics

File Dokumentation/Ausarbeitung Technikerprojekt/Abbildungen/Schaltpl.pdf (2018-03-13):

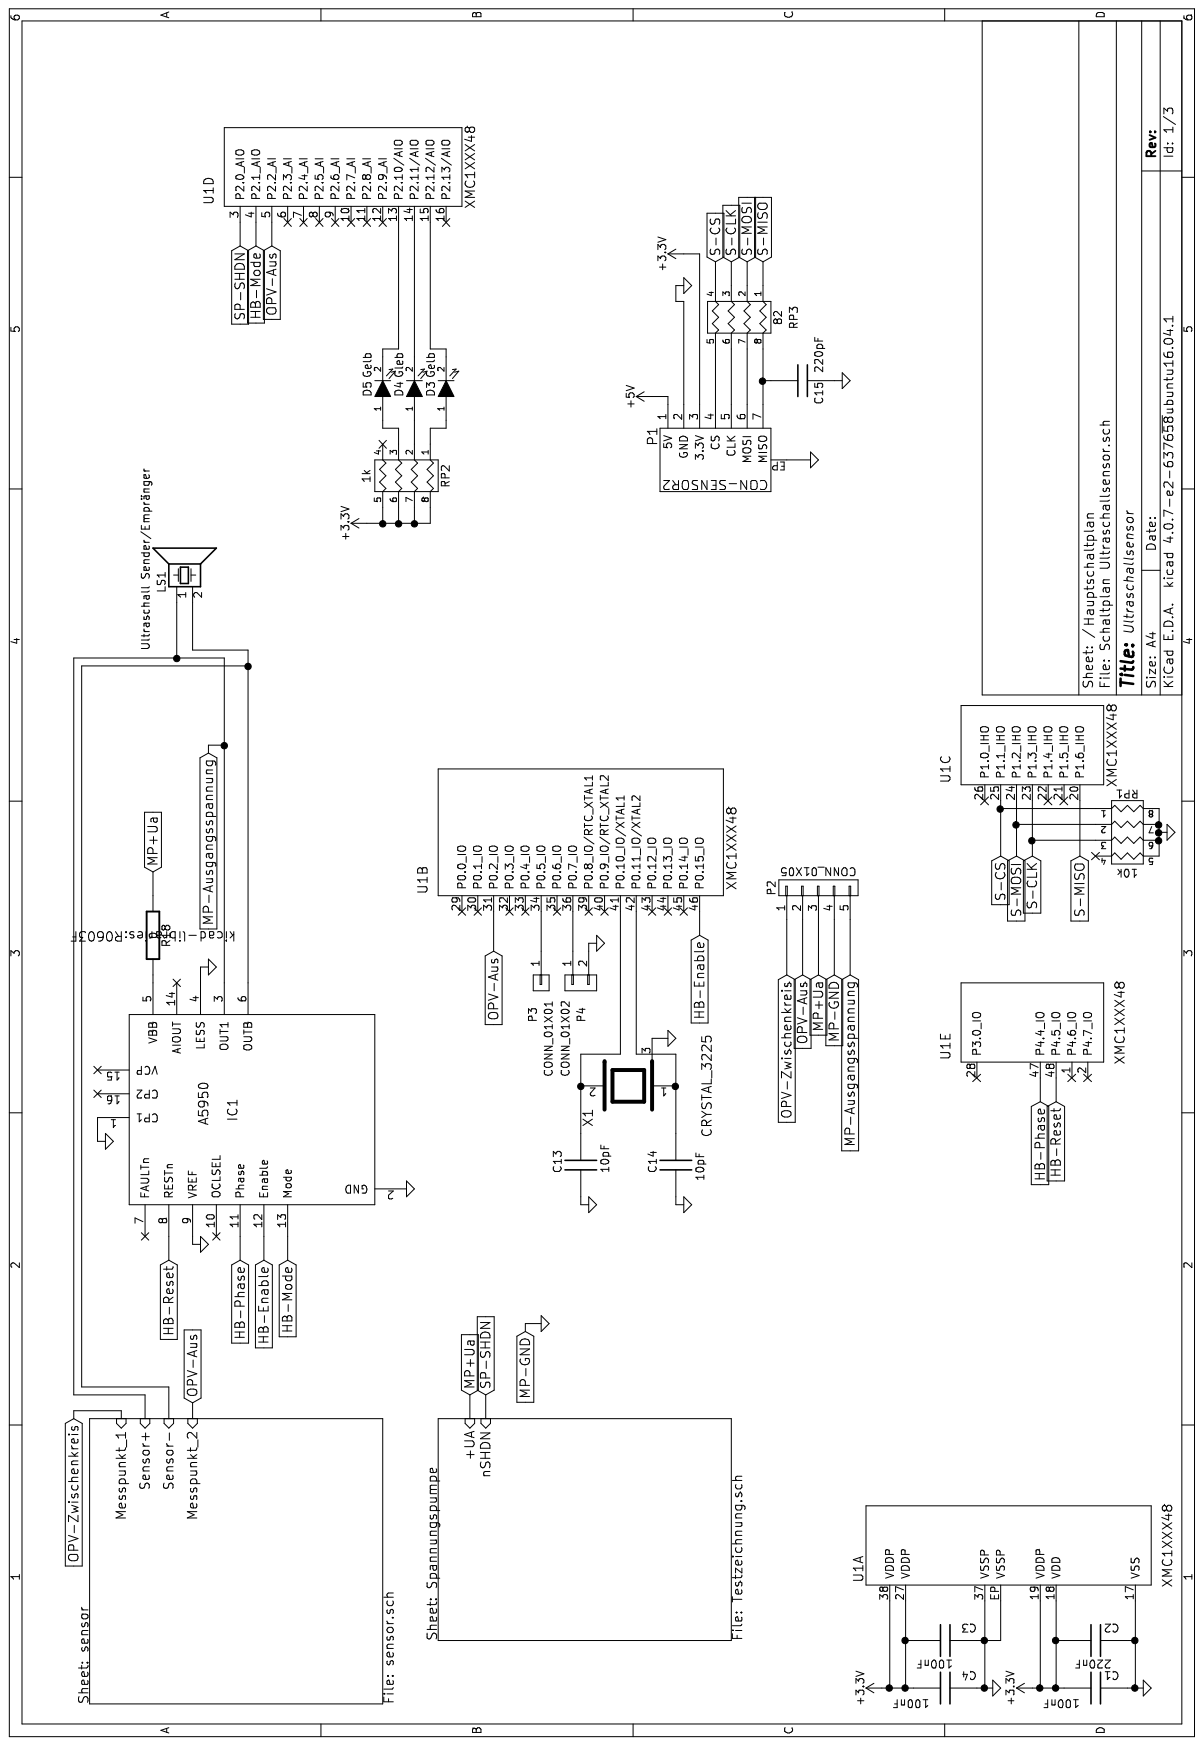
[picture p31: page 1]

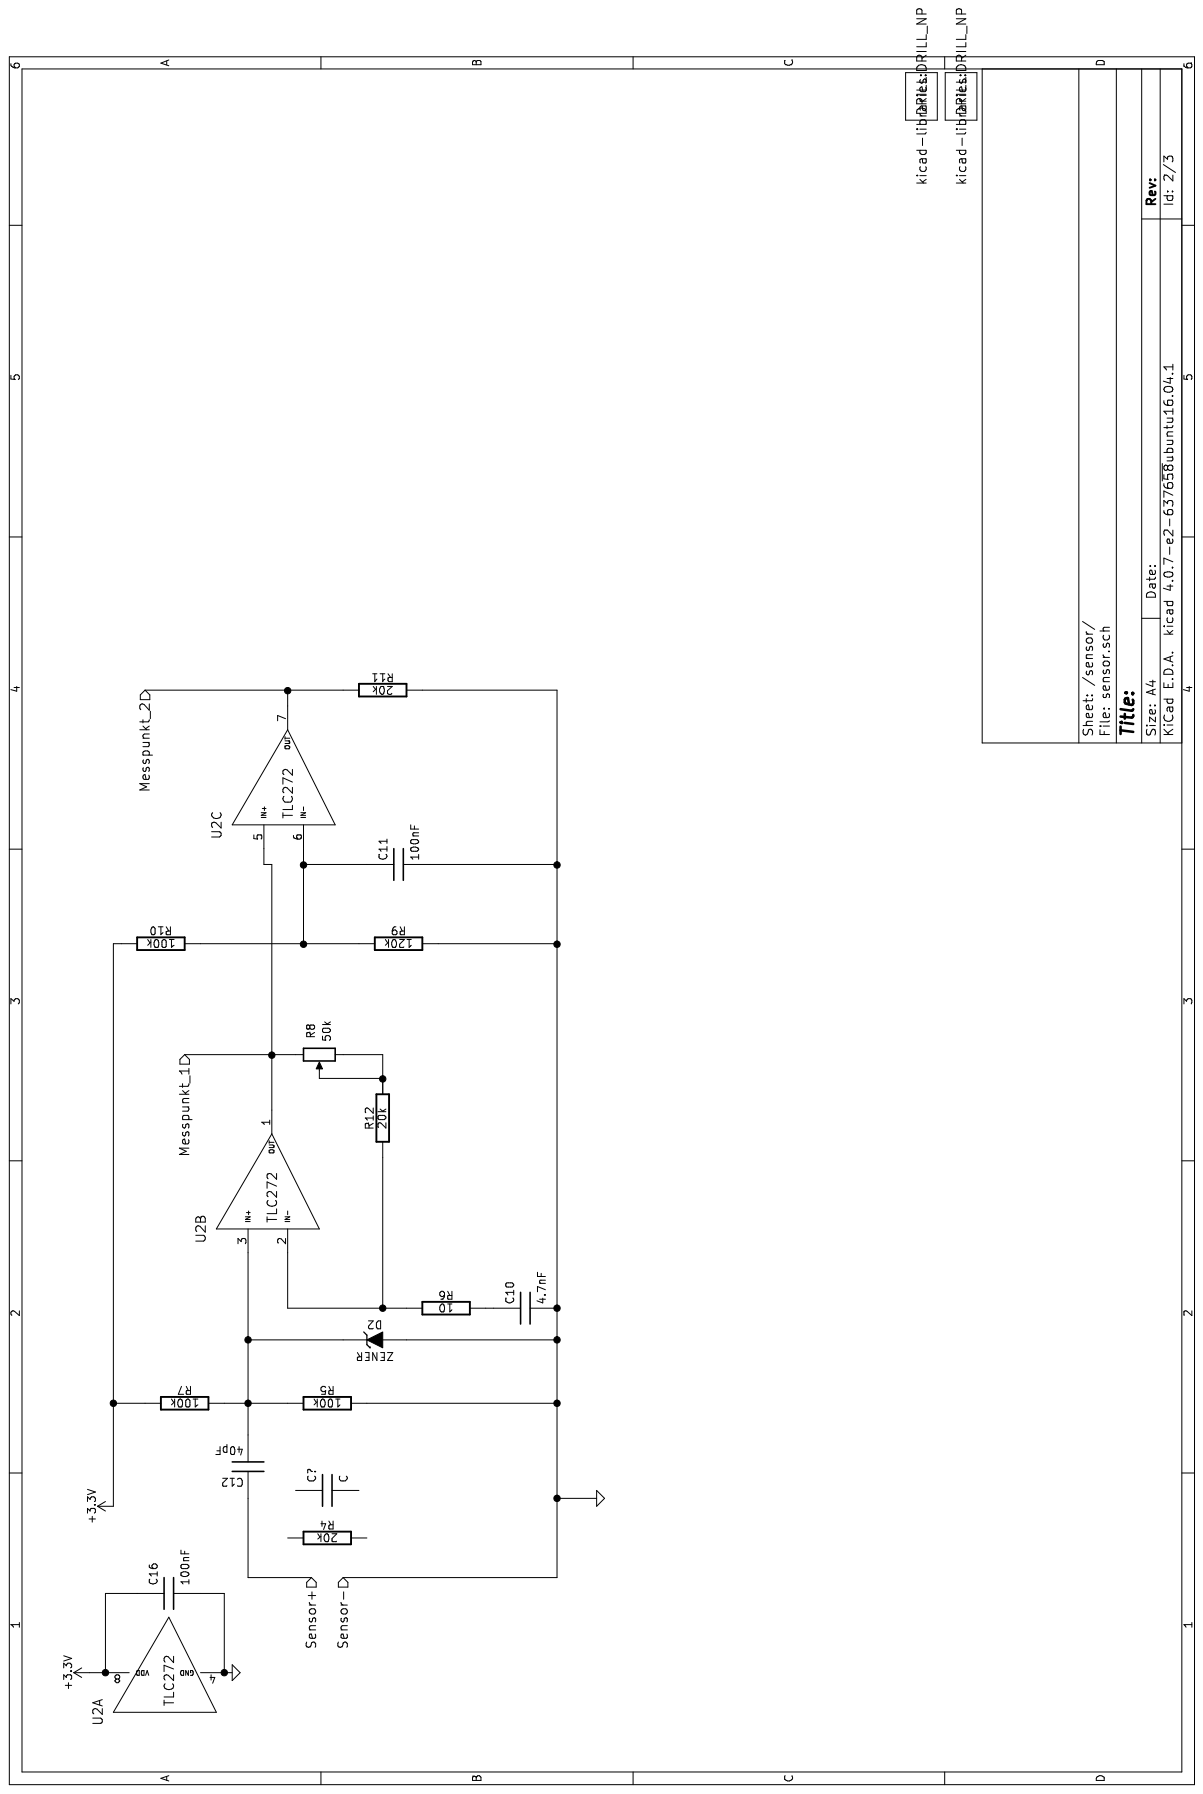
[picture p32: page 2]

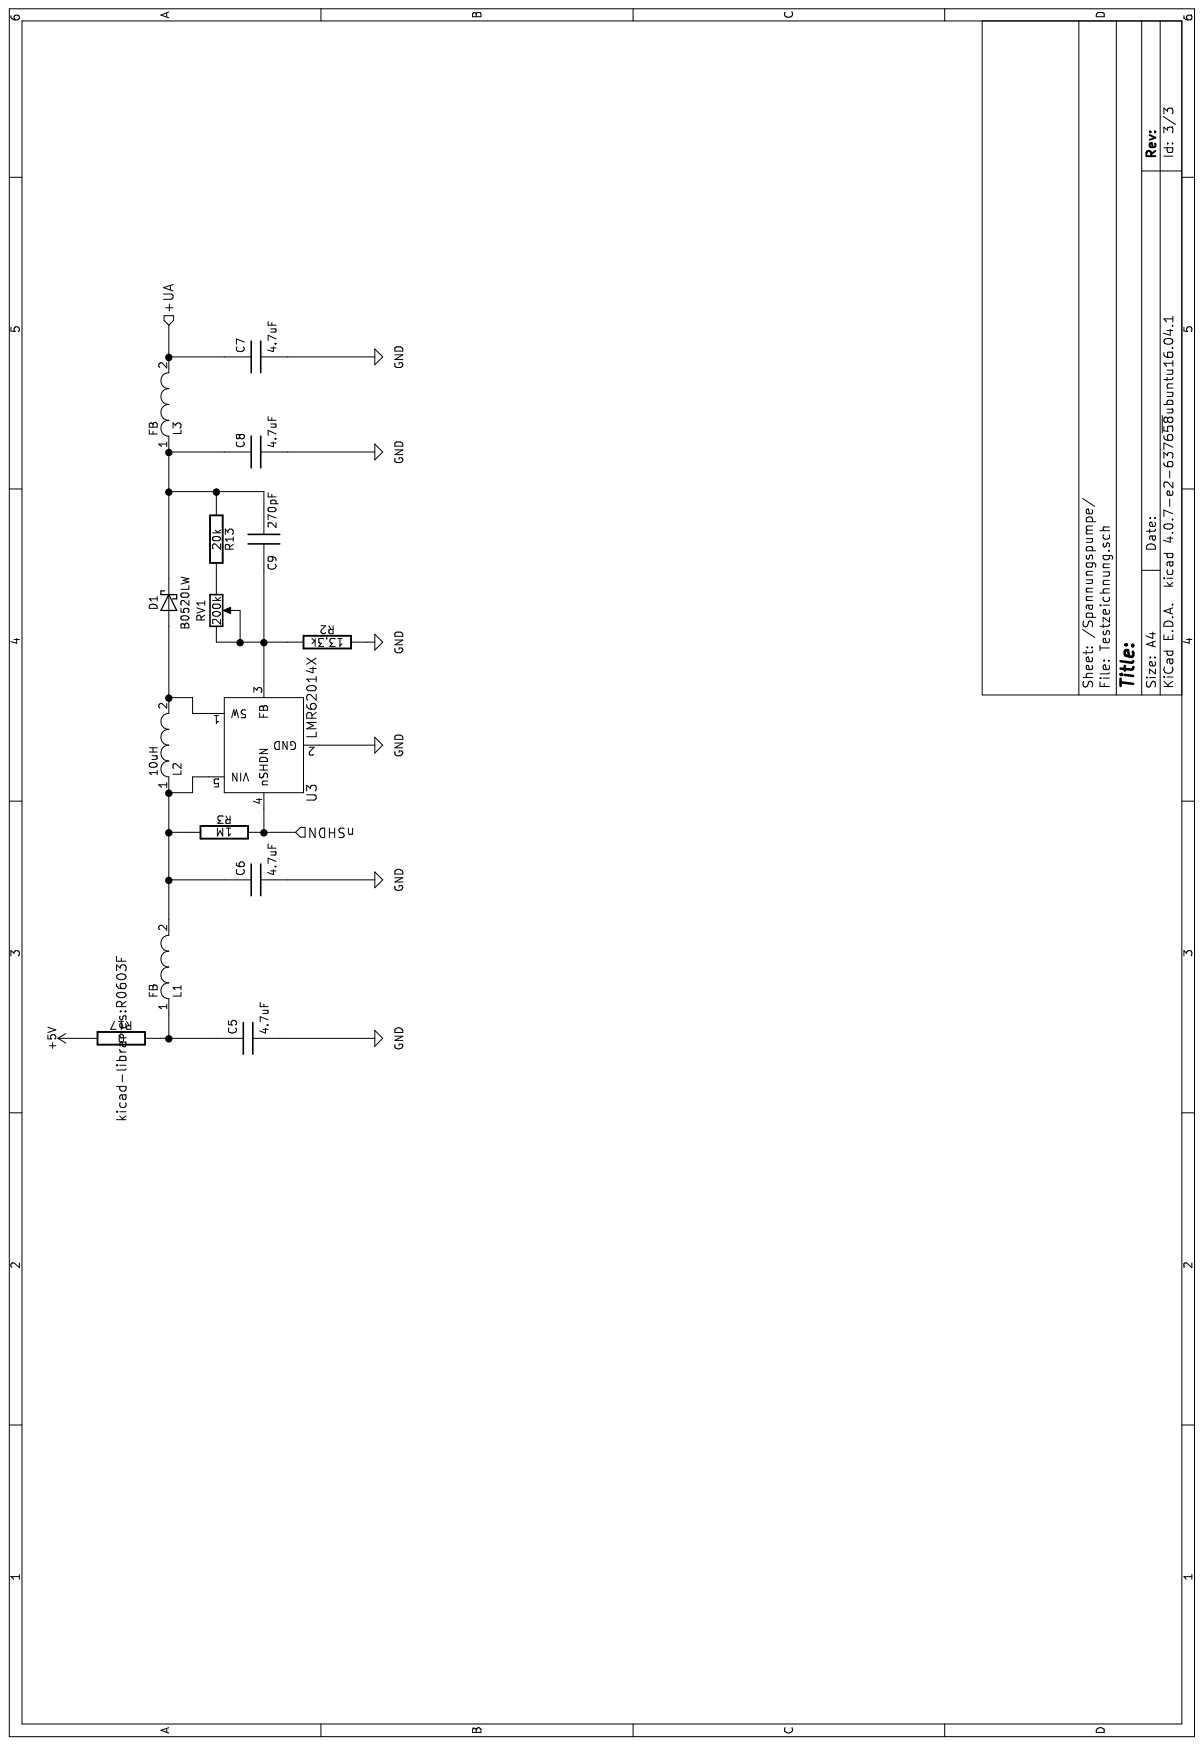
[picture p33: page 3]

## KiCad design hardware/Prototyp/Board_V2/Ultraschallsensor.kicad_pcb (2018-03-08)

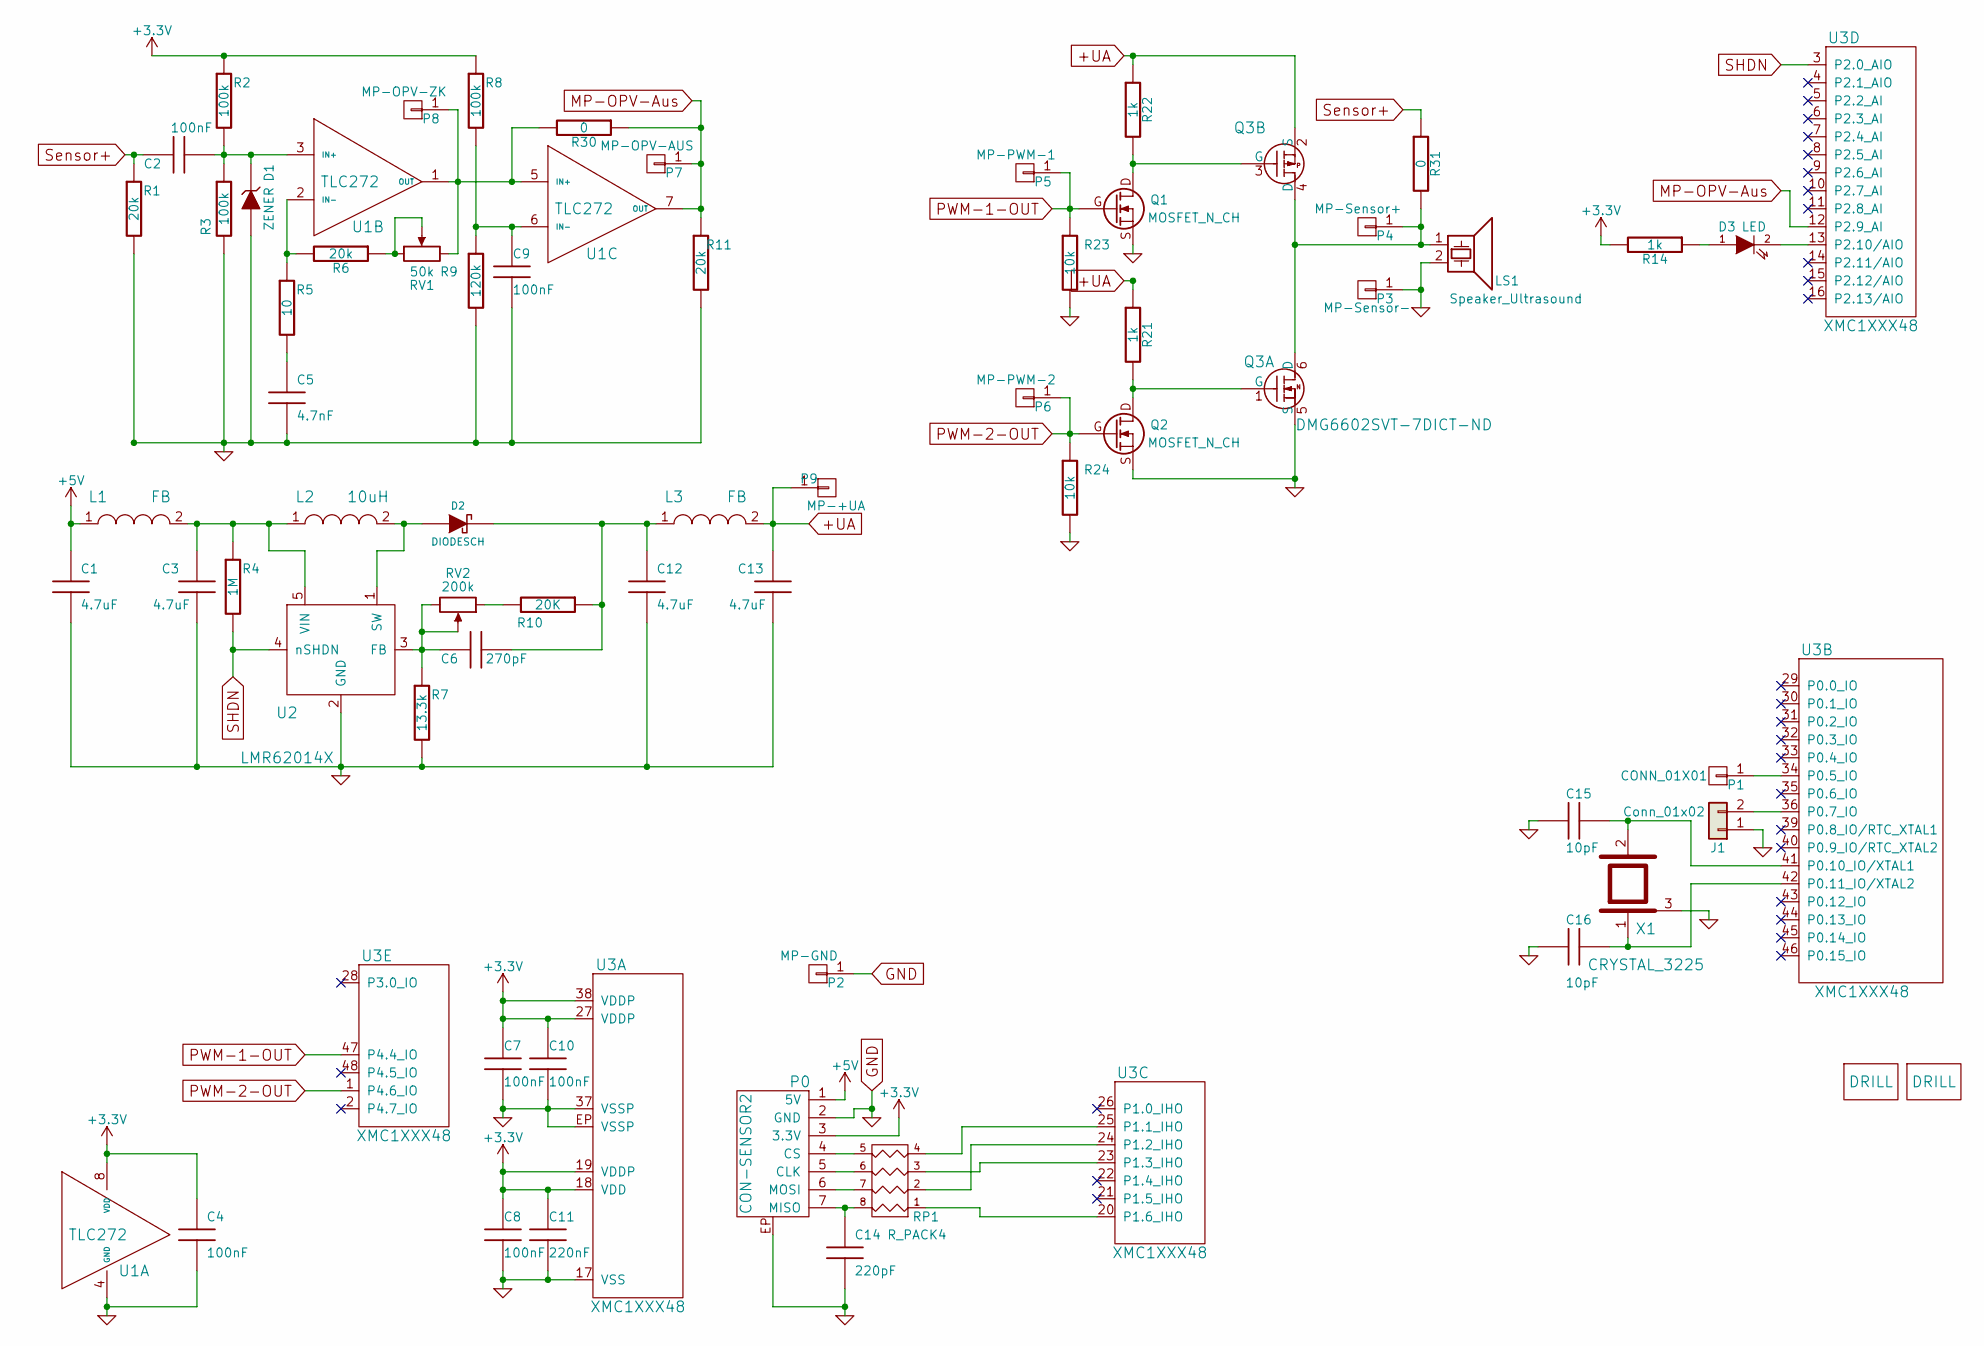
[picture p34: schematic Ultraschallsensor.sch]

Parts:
C1, C3, C12, C13: 4.7uF; C0805
C2, C4, C7, C8, C9, C10: 100nF; C0603F
C5: 4.7nF; C0603F
C6: 270pF; C0603F
C11: 220nF; C0603F
C14: 220pF; C0402F
C15, C16: 10pF; C0603F
D1: ZENER; SOD-123
D2: DIODESCH; SOD-123
D3: LED; D0603E
J1: Conn_01x02; SolderJumper
L1, L3: FB; C0603F
L2: 10uH; NR3030
LS1: Speaker_Ultrasound; PIN_ARRAY_2X1
P0: CON-SENSOR2
P1: CONN_01X01; CONN_1
P2: MP-GND; CONN_1
P3: MP-Sensor-; DEBUG_PAD
P4: MP-Sensor+; DEBUG_PAD
P5: MP-PWM-1; DEBUG_PAD
P6: MP-PWM-2; DEBUG_PAD
P7: MP-OPV-AUS; CONN_1
P8: MP-OPV-ZK; CONN_1
P9: MP-+UA; CONN_1
Q1, Q2: MOSFET_N_CH; SOT23GDS
Q3: DMG6602SVT-7DICT-ND; SOT23-6
R1, R6, R11: 20k; R0603F
R2, R3, R8: 100k; R0603F
R4: 1M; R0603F
R5: 10; R0603F
R7: 13.3k; R0603F
R9: 120k; R0603F
R10: 20K; R0603F
R14: 1k; R0603F
R21, R22: 1k; 1206E
R23, R24: 10k; R0603F
R30, R31: 0; R0603F
RP1: R_PACK4; 4X0402
RV1: 50k; ST4
RV2: 200k; ST4
U1: TLC272; TSSOP8
U2: LMR62014X; SOT23-5
U3: XMC1XXX48; QFN48-EP2
U4, U5: DRILL; DRILL_NP
X1: CRYSTAL_3225

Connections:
+3V3: C4.1, C7.1, C8.1, C10.1, C11.1, P0.3 (3.3V), R2.1, R8.1, R14.2, U1.8 (VDD), U3.18 (VDD), U3.19 (VDDP), U3.27 (VDDP), U3.38 (VDDP)
+5V: C1.1, L1.1, P0.1 (5V)
+UA: C13.1, L3.2, P9.1, Q3.2 (S), R21.1, R22.1
GND: C1.2, C3.2, C4.2, C5.2, C7.2, C8.2, C9.2, C10.2, C11.2, C12.2, C13.2, C14.2, C15.2, C16.2, D1.1 (A), J1.1, LS1.2, P0.2 (GND), P0.EP, P2.1, P3.1, Q1.S, Q2.S, Q3.5 (S), R1.2, R3.2, R7.2, R9.2, R11.2, R23.2, R24.2, U1.4 (GND), U2.2 (GND), U3.17 (VSS), U3.37 (VSSP), U3.EP (VSSP), X1.3
MP-OPV-Aus: P7.1, R11.1, R30.1, U1.7 (OUT), U3.12 (P2.9_AI)
unnamed: C2.1, D1.2 (K), R2.2, R3.1, U1.3 (IN+)
unnamed: C3.1, L1.2, L2.1, R4.1, U2.5 (VIN)
unnamed: C5.1, R5.2
unnamed: C6.2, R7.1, RV2.2, RV2.3, U2.3 (FB)
unnamed: C9.1, R8.2, R9.1, U1.6 (IN-)
unnamed: C6.1, C12.1, D2.2 (K), L3.1, R10.1
unnamed: C14.1, P0.7 (MISO), RP1.8 (R1)
unnamed: C15.1, U3.41 (P0.10_IO/XTAL1), X1.2
unnamed: C16.1, U3.42 (P0.11_IO/XTAL2), X1.1
unnamed: D2.1 (A), L2.2, U2.1 (SW)
unnamed: D3.1 (A), R14.1
unnamed: D3.2 (K), U3.13 (P2.10/AIO)
unnamed: J1.2, U3.36 (P0.7_IO)
unnamed: LS1.1, P4.1, Q3.4 (D), Q3.6 (D), R31.2
unnamed: P0.4 (CS), RP1.5 (R4)
unnamed: P0.5 (CLK), RP1.6 (R3)
unnamed: P0.6 (MOSI), RP1.7 (R2)
unnamed: P1.1, U3.34 (P0.5_IO)
unnamed: P8.1, R30.2, RV1.3, U1.1 (OUT), U1.5 (IN+)
unnamed: Q1.D, Q3.3 (G), R22.2
unnamed: Q2.D, Q3.1 (G), R21.2
unnamed: R5.1, R6.2, U1.2 (IN-)
unnamed: R6.1, RV1.1, RV1.2
unnamed: R10.2, RV2.1
unnamed: RP1.1, U3.20 (P1.6_IHO)
unnamed: RP1.2, U3.24 (P1.2_IHO)
unnamed: RP1.3, U3.23 (P1.3_IHO)
unnamed: RP1.4, U3.25 (P1.1_IHO)
PWM-1-OUT: P5.1, Q1.G, R23.1, U3.47 (P4.4_IO)
PWM-2-OUT: P6.1, Q2.G, R24.1, U3.1 (P4.6_IO)
SHDN: R4.2, U2.4 (nSHDN), U3.3 (P2.0_AIO)
Sensor+: C2.2, R1.1, R31.1

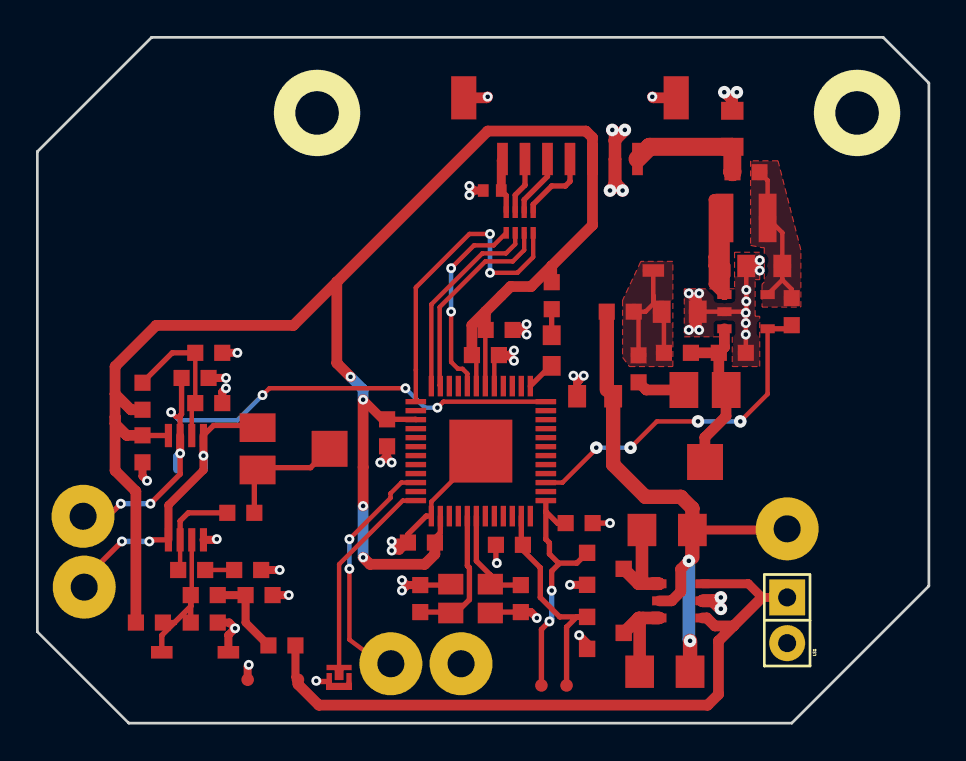
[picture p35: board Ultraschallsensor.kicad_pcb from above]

Board: 2 copper layers, 49.5 x 38.1 mm, 64 parts (1 on the bottom side), 37 nets.

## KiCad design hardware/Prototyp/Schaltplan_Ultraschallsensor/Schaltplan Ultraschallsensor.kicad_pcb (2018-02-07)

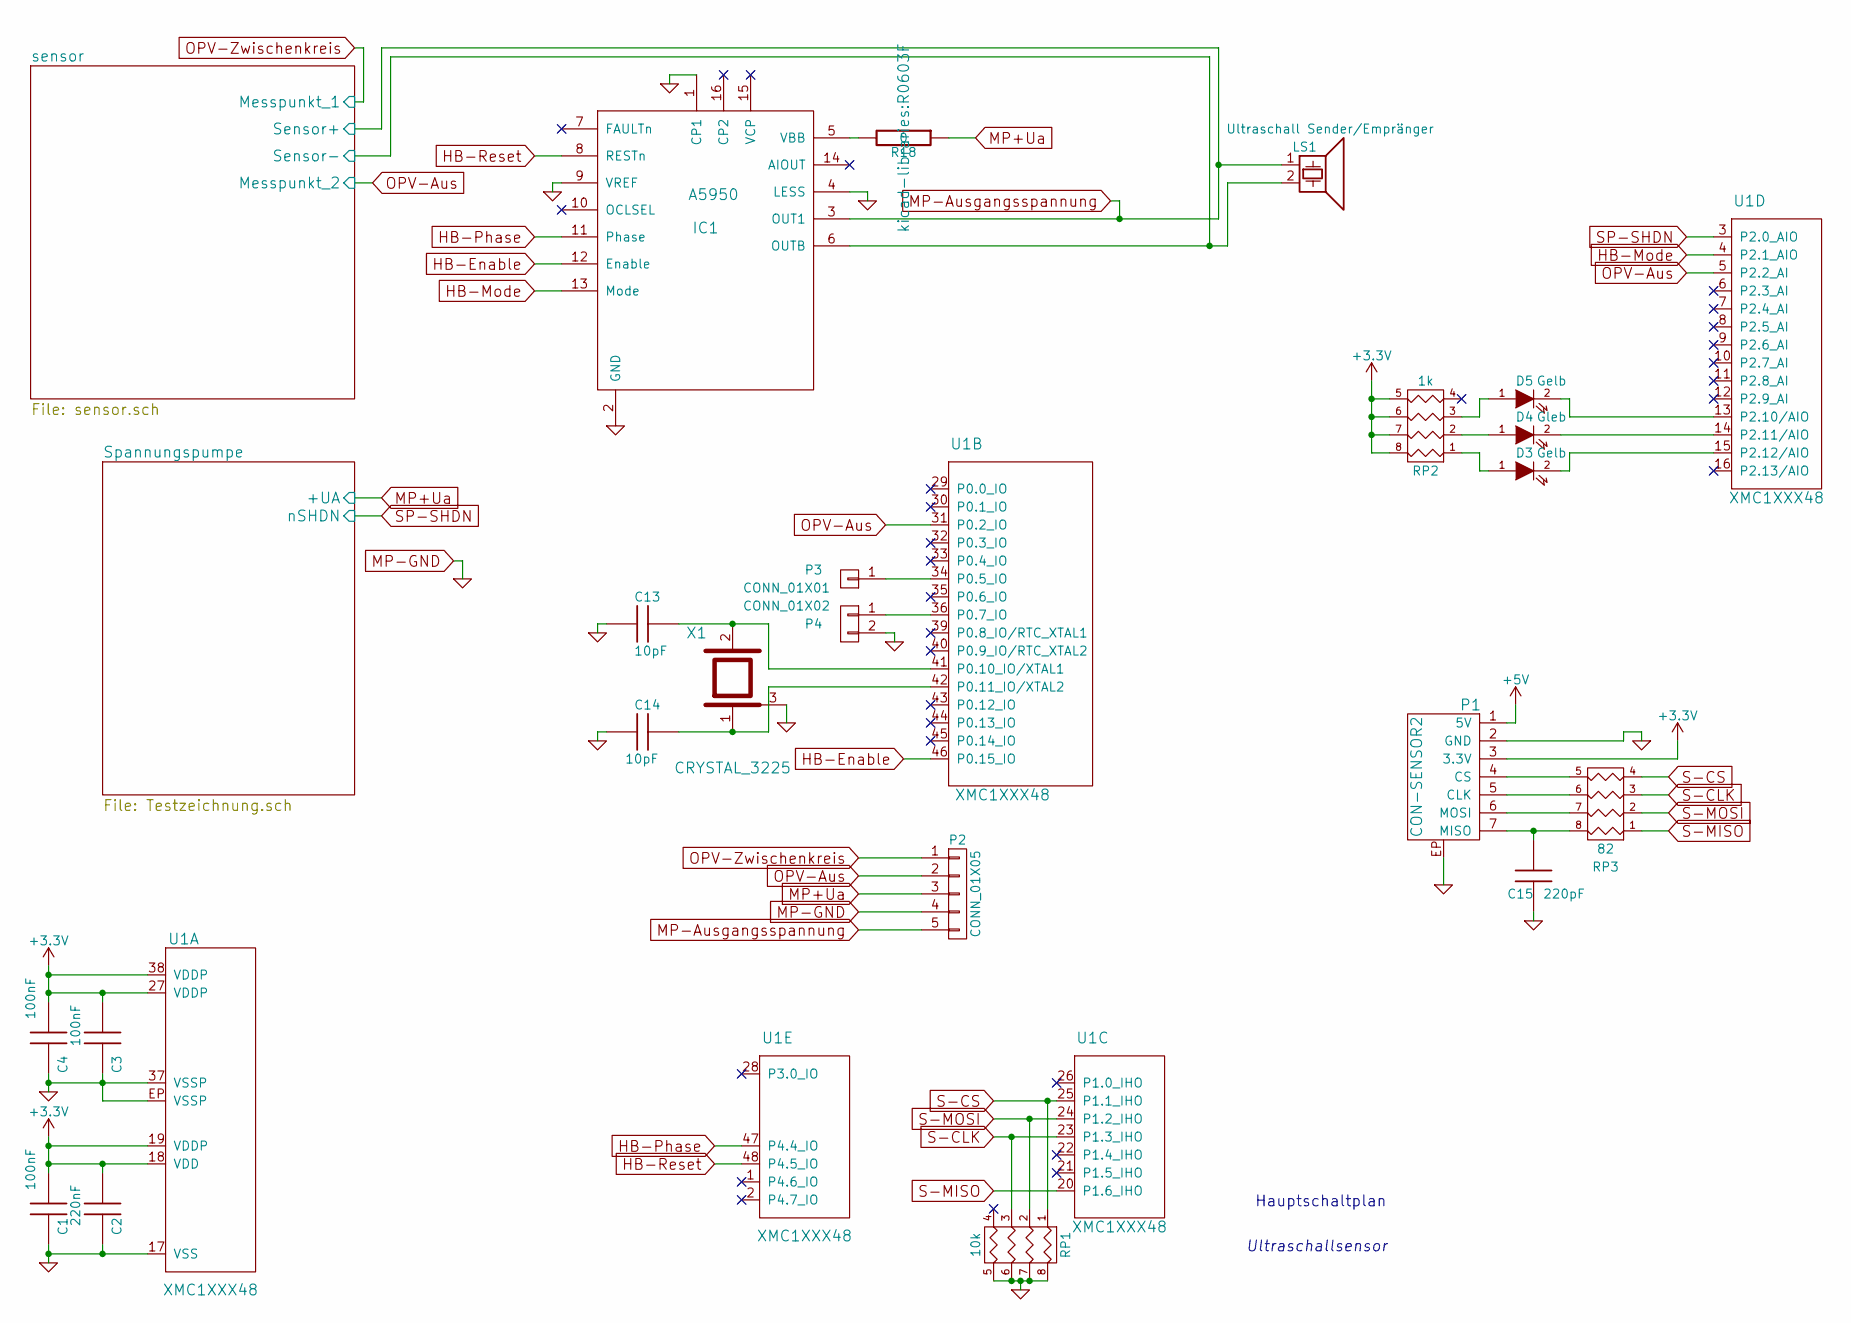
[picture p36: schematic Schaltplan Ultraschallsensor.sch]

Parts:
C1, C3, C4: 100nF; C0603F
C2: 220nF; C0603F
C13, C14: 10pF; C0603F
C15: 220pF; C0402F
D3, D5: Gelb; D0603E
D4: Gleb; D0603E
IC1: A5950; 16-leadTSSOP_0,137,4,4mmBreite
LS1: Ultraschall Sender/Empränger; Ultraschallsensor
P1: CON-SENSOR2
P2: CONN_01X05; pin_array_5x1
P3: CONN_01X01; DEBUG_PAD
P4: CONN_01X02; SolderJumper
R18: 0; R0603F
RP1: 10k; 0603X4
RP2: 1k; 0603X4
RP3: 82; 4X0402
U1: XMC1XXX48; QFN48-EP2
X1: CRYSTAL_3225

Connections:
+5V: P1.1 (5V); also elsewhere on the board
HB-Enable: IC1.12 (Enable), U1.46 (P0.15_IO)
HB-Mode: IC1.13 (Mode), U1.4 (P2.1_AIO)
HB-Phase: IC1.11 (Phase), U1.47 (P4.4_IO)
HB-Reset: IC1.8 (RESTn), U1.48 (P4.5_IO)
MP+Ua: P2.3, R18.1; also elsewhere on the board
MP-Ausgangsspannung: IC1.3 (OUT1), LS1.1, P2.5; also elsewhere on the board
MP-GND: C1.2, C2.2, C3.2, C4.2, C13.2, C14.2, C15.2, IC1.1 (CP1), IC1.2 (GND), IC1.4 (LESS), IC1.6 (OUTB), IC1.9 (VREF), LS1.2, P1.2 (GND), P1.EP, P2.4, P4.2, RP1.5 (R4), RP1.6 (R3), RP1.7 (R2), RP1.8 (R1), U1.17 (VSS), U1.37 (VSSP), U1.EP (VSSP), X1.3; also elsewhere on the board
unnamed: C13.1, U1.41 (P0.10_IO/XTAL1), X1.2
unnamed: C14.1, U1.42 (P0.11_IO/XTAL2), X1.1
unnamed: C15.1, P1.7 (MISO), RP3.8 (R1)
unnamed: D3.1 (A), RP2.1
unnamed: D3.2 (K), U1.15 (P2.12/AIO)
unnamed: D4.1 (A), RP2.2
unnamed: D4.2 (K), U1.14 (P2.11/AIO)
unnamed: D5.1 (A), RP2.3
unnamed: D5.2 (K), U1.13 (P2.10/AIO)
unnamed: IC1.5 (VBB), R18.2
unnamed: P1.4 (CS), RP3.5 (R4)
unnamed: P1.5 (CLK), RP3.6 (R3)
unnamed: P1.6 (MOSI), RP3.7 (R2)
unnamed: P3.1, U1.34 (P0.5_IO)
unnamed: P4.1, U1.36 (P0.7_IO)
OPV-Aus: P2.2, U1.5 (P2.2_AI), U1.31 (P0.2_IO); also elsewhere on the board
S-CLK: RP1.3, RP3.3, U1.23 (P1.3_IHO)
S-CS: RP1.1, RP3.4, U1.25 (P1.1_IHO)
S-MISO: RP3.1, U1.20 (P1.6_IHO)
S-MOSI: RP1.2, RP3.2, U1.24 (P1.2_IHO)
SP-SHDN: U1.3 (P2.0_AIO); also elsewhere on the board

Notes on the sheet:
Ultraschallsensor
Hauptschaltplan

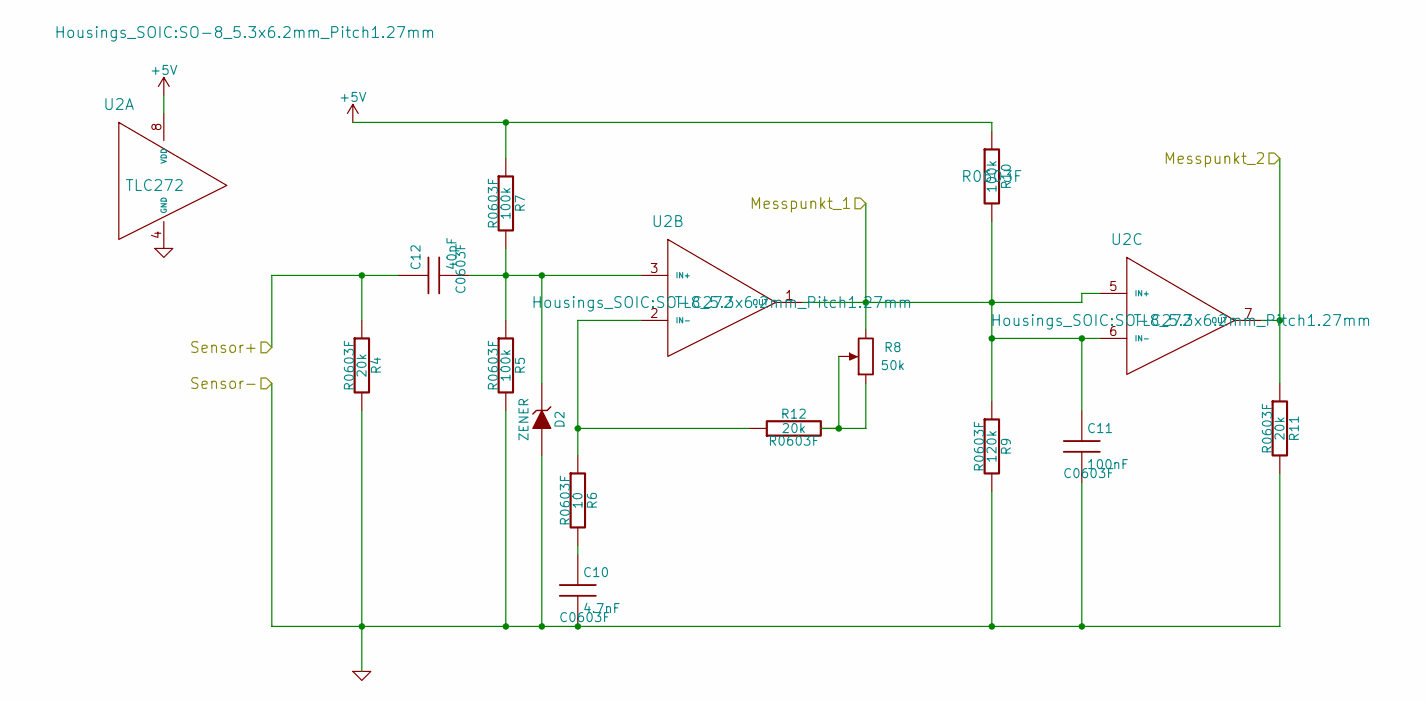
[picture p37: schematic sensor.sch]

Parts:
C10: 4.7nF; C0603F
C11: 100nF; C0603F
C12: 40pF; C0603F
D2: ZENER
R4, R11, R12: 20k; R0603F
R5, R7, R10: 100k; R0603F
R6: 10; R0603F
R8: 50k
R9: 120k; R0603F
U2: TLC272; SO-8_5.3x6.2mm_Pitch1.27mm

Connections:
MP-Ausgangsspannung: C12.1, R4.1; also elsewhere on the board
MP-GND: C10.2, C11.2, D2.1 (A), R4.2, R5.2, R9.2, R11.2, U2.4 (GND); also elsewhere on the board
unnamed: C10.1, R6.2
unnamed: C12.2, D2.2 (K), R5.1, R7.2, U2.3 (IN+)
unnamed: R6.1, R12.1, U2.2 (IN-)
unnamed: R8.1, R8.2, R12.2
OPV-Aus: R11.1, U2.7 (OUT); also elsewhere on the board

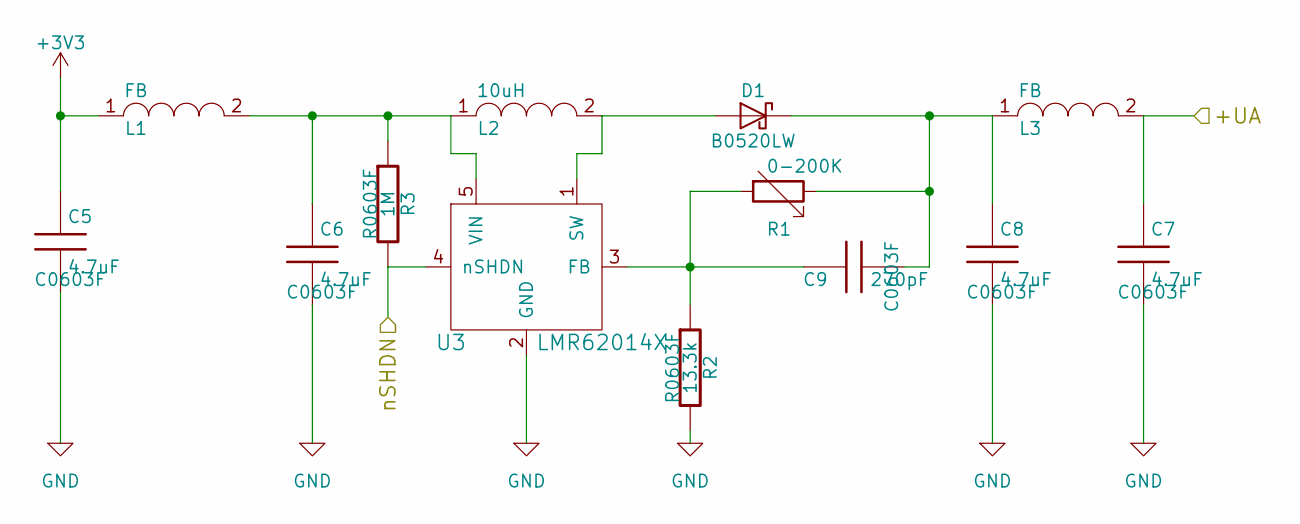
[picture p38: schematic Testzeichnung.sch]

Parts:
C5, C6, C7, C8: 4.7uF; C0603F
C9: 270pF; C0603F
D1: B0520LW
L1, L3: FB
L2: 10uH
R1: 0-200K
R2: 13.3k; R0603F
R3: 1M; R0603F
U3: LMR62014X

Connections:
MP+Ua: C7.1, L3.2; also elsewhere on the board
MP-GND: C5.2, C6.2, C7.2, C8.2, R2.2, U3.2 (GND); also elsewhere on the board
unnamed 8: C5.1, L1.1; also elsewhere on the board
unnamed: C6.1, L1.2, L2.1, R3.1, U3.5 (VIN)
unnamed 10: C8.1, C9.2, D1.1 (K), L3.1, R1.1; also elsewhere on the board
unnamed 11: C9.1, R1.2, R2.1, U3.3 (FB); also elsewhere on the board
unnamed: D1.2 (A), L2.2, U3.1 (SW)
SP-SHDN: R3.2, U3.4 (nSHDN); also elsewhere on the board

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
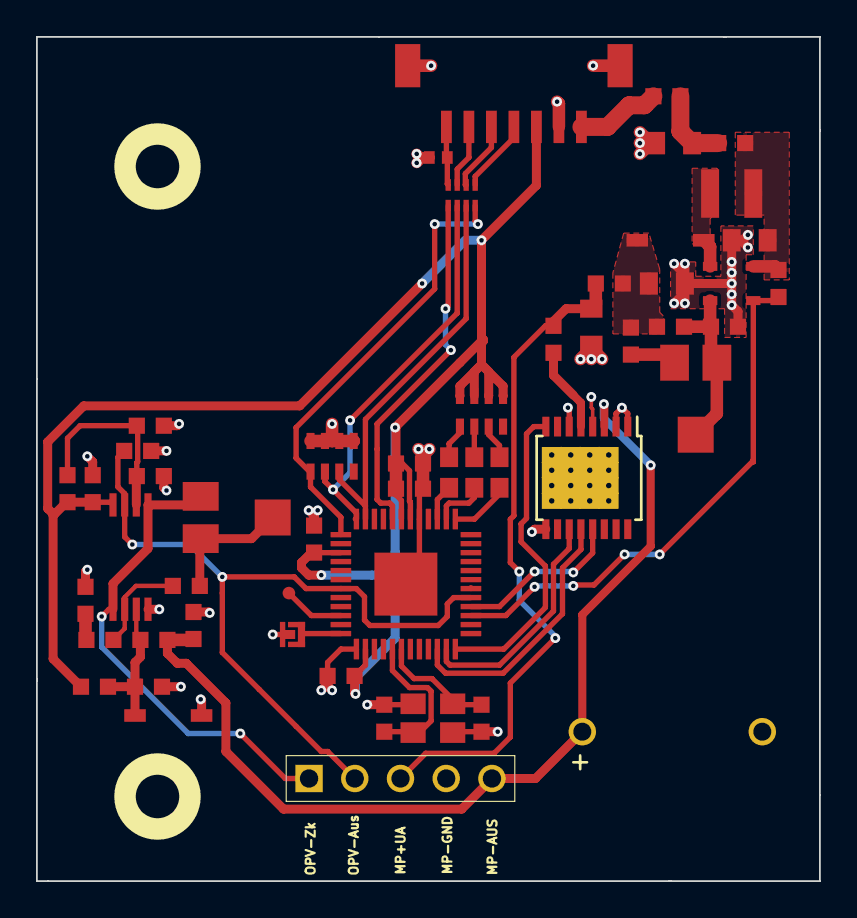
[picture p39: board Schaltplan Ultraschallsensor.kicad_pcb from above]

Board: 2 copper layers, 43.5 x 46.9 mm, 54 parts (0 on the bottom side), 42 nets.

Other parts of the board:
C16: 100nF; C0603F
R13: 20k; R0603F
R17: 0; R0603F
RV1: 200k; ST4ETA
U5, U6: DRILL; DRILL_NP

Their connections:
+5V: R17.1; also elsewhere on the board
MP-GND: C16.2; also elsewhere on the board
unnamed 8: R17.2; also elsewhere on the board
unnamed 10: R13.1; also elsewhere on the board
unnamed 11: RV1.2, RV1.3; also elsewhere on the board
unnamed: R13.2, RV1.1

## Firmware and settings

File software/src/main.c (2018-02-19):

/* distance-us-v2-bricklet
 * Copyright (C) 2018 Olaf Lüke <olaf@tinkerforge.com>
 *
 * main.c: Initialization for Distance US V2 Bricklet
 *
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
 * You should have received a copy of the GNU Lesser General Public
 * License along with this library; if not, write to the
 * Free Software Foundation, Inc., 59 Temple Place - Suite 330,
 * Boston, MA 02111-1307, USA.
 */

#include <stdio.h>
#include <stdbool.h>

#include "configs/config.h"
/*************Eigene_Include_Dateien************/
#include "bricklib2/bootloader/bootloader.h"
#include "system_timer/system_timer.h"
#include "bricklib2/logging/logging.h"
#include "communication.h"
#include "a16pt.h"


int main(void) {
	logging_init();
	logd("Start Distance US V2 Bricklet\n\r"); //Für den DBugModus TXPin P0_12

	communication_init();											//Funktionsaufruf
	a16pt_init();															//Funktionsaufruf


	while(true)
{

		a16pt_tick(); 												//Funktionsaufruf
		bootloader_tick();										//Funktionsaufruf
		communication_tick();									//Funktionsaufruf

}
}

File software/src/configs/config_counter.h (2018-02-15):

/* industrial-counter-bricklet
 * Copyright (C) 2017 Olaf Lüke <olaf@tinkerforge.com>
 *
 * config_counter.h: Configuration for counter
 *
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
 * You should have received a copy of the GNU Lesser General Public
 * License along with this library; if not, write to the
 * Free Software Foundation, Inc., 59 Temple Place - Suite 330,
 * Boston, MA 02111-1307, USA.
 */

#ifndef CONFIG_COUNTER_H
#define CONFIG_COUNTER_H

#define COUNTER_STATUS0_LED_PIN          P4_7
#define COUNTER_STATUS1_LED_PIN          P4_6
#define COUNTER_STATUS2_LED_PIN          P4_5
#define COUNTER_STATUS3_LED_PIN          P4_4


#define COUNTER_IN0_PIN                  P0_4
#define COUNTER_IN1_PIN                  P0_12
#define COUNTER_IN2_PIN                  P3_0
#define COUNTER_IN3_PIN                  P0_0

#define COUNTER_IN0_NONEXTDIR_PIN        P0_4
#define COUNTER_IN1_NONEXTDIR_PIN        P0_12
#define COUNTER_IN2_NONEXTDIR_PIN        P3_0
#define COUNTER_IN3_NONEXTDIR_PIN        P0_0

#define COUNTER_IN0_POSIF_PIN            P1_2
#define COUNTER_IN1_POSIF_PIN            P1_1
#define COUNTER_IN2_POSIF_PIN            P1_0

#define COUNTER_IN0_MODULE               CCU41
#define COUNTER_IN0_MODULE_NUMBER        1

#define COUNTER_IN0_SLICE0               CCU41_CC40
#define COUNTER_IN0_SLICE0_NUMBER        0

#define COUNTER_IN0_SLICE1               CCU41_CC41
#define COUNTER_IN0_SLICE1_NUMBER        1

#define COUNTER_IN0_SLICE2               CCU41_CC42
#define COUNTER_IN0_SLICE2_NUMBER        2

#define COUNTER_IN0_SLICE3               CCU41_CC43
#define COUNTER_IN0_SLICE3_NUMBER        3


#define COUNTER_IN1_MODULE               CCU80
#define COUNTER_IN1_MODULE_NUMBER        0

#define COUNTER_IN1_SLICE0               CCU80_CC80
#define COUNTER_IN1_SLICE0_NUMBER        0

#define COUNTER_IN1_SLICE1               CCU80_CC81
#define COUNTER_IN1_SLICE1_NUMBER        1

#define COUNTER_IN1_SLICE2               CCU80_CC82
#define COUNTER_IN1_SLICE2_NUMBER        2

#define COUNTER_IN1_SLICE3               CCU80_CC83
#define COUNTER_IN1_SLICE3_NUMBER        3


#define COUNTER_IN2_MODULE               CCU81
#define COUNTER_IN2_MODULE_NUMBER        1

#define COUNTER_IN2_SLICE0               CCU81_CC80
#define COUNTER_IN2_SLICE0_NUMBER        0

#define COUNTER_IN2_SLICE1               CCU81_CC81
#define COUNTER_IN2_SLICE1_NUMBER        1

#define COUNTER_IN2_SLICE2               CCU81_CC82
#define COUNTER_IN2_SLICE2_NUMBER        2

#define COUNTER_IN2_SLICE3               CCU81_CC83
#define COUNTER_IN2_SLICE3_NUMBER        3


#define COUNTER_IN3_MODULE               CCU40
#define COUNTER_IN3_MODULE_NUMBER        0

#define COUNTER_IN3_SLICE0               CCU40_CC40
#define COUNTER_IN3_SLICE0_NUMBER        0

#define COUNTER_IN3_SLICE1               CCU40_CC41
#define COUNTER_IN3_SLICE1_NUMBER        1

#define COUNTER_IN3_SLICE2               CCU40_CC42
#define COUNTER_IN3_SLICE2_NUMBER        2

#define COUNTER_IN3_SLICE3               CCU40_CC43
#define COUNTER_IN3_SLICE3_NUMBER        3

#endif

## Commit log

2018-02-01 neue Version
    [OPV.kicad_pcb, OPV.sch, Schaltplan Ultraschallsensor.kicad_pcb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]
2018-02-02 Lösche Schaltplan
    [OPV.kicad_pcb, OPV.sch, Schaltplan Ultraschallsensor.kicad_pcb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]
2018-02-02 Lösche sensor
    [sensor.kicad_pcb, sensor.sch]
2018-02-02 lösche schaltplan_ultraschallsensor
    [OPV.kicad_pcb, OPV.sch, Schaltplan Ultraschallsensor.kicad_pcb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]
2018-02-02 Lösche Schaltplan_Ultraschall
    [OPV.kicad_pcb, OPV.sch, Schaltplan Ultraschallsensor.kicad_pcb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]
2018-02-02 An TF angepasst
    [OPV.kicad_pcb, OPV.sch, Schaltplan Ultraschallsensor.kicad_pcb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]
2018-02-02 lösche
    [OPV.kicad_pcb, OPV.sch, Schaltplan Ultraschallsensor.kicad_pcb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]
2018-02-05 Add stub software implementation for Distance US Bricklet 2.0
    [cmake_config_custom.txt]
2018-02-05 Fix status and boot pad pins
    [config_custom_bootloader.h]
2018-02-05 Use correct flash size
    [cmake_config_custom.txt]
2018-02-14 Defines für den US sensor fertig
2018-02-19 Neue Ordner und Software
2018-02-19 Use correct shadow transfers, make sure that wie use slice number as integer instead of pointer if necessary, add proper indentation
    [ccu4_pwm_timer.c]
2018-02-19 Start pwm timer every 33ms (30 measurements per second)
2018-02-19 Stop slice 0 if slice interrupt occurs (10x edge alternation of PWM)
2018-02-22 Use correct pins for boot pad and status led
    [config_custom_bootloader.h, config_custom_bootstrapper.h]
2018-03-02 set clearance to 0
    [Ultraschallsensor.kicad_pcb]
2018-03-05 update documentation
    [Ultraschallsensor.kicad_pcb, Ultraschallsensor.sch]
2018-03-06 Add define for gap between PWM. The high side/low side switch are not allowed to be turned on at the same time, so we add a small gap between the PWM peaks to make sure that we never have a short cir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
    [config_a16pt.h]
2018-03-06 Refactor pwm config function, so the function can be properly called with different slice numberes again
2018-03-06 When we want to stop the PWM, we have to make sure that the "high peak" of the second PWM runs completely through before we stop it. Otherwise we get 10 peaks on the low side switch but only 9.5 peak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
2018-03-06 Put slice independent configurations and configurations that are not done for every PWM in the init function directly
2018-03-06 Start timer CCUs synchronously through SCU with high trigger
2018-03-06 Before start clear slice 0 and initialize slice 2 with compare value, so we get the offsets between the PWMs.
2018-03-08 Korrektur pcb
    [Ultraschallsensor.kicad_pcb, Ultraschallsensor.sch, _saved_Schaltplan Ultraschallsensor.sch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]
2018-03-14 Add files via upload
    Neue Struktur und Text
2018-03-15 Änderung an der Überschrift 2.3
2018-03-15 Add files via upload
    Extrea Kaptiel Besonderheit der Software
2018-03-15 Add files via upload
    Programm abschnitt bei Interrupt richtig geändert
2018-03-16 Add files via upload
    Filterschaltung sowie Hochsetzsteler bearbeitet
2018-03-17 Add files via upload
    Erste Korrekturen wurden vorgenommen und eine Überschrift angepasst
2018-03-19 Add files via upload
    Um die Init erweiter usw.
2018-03-20 Update 10_Fazit_Auftraggeber.tex
    aus "mach" wird "ist" im letzten Satz
2018-04-18 Schaltplan Korrektur
    [Ultraschallsensor.sch]
2021-10-25 Update KiCad link
    https://www.kicad.org/blog/2021/10/Avoid-links-to-former-kicad-domain/
